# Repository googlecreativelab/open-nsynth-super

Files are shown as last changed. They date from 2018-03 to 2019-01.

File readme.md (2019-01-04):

# Open NSynth Super

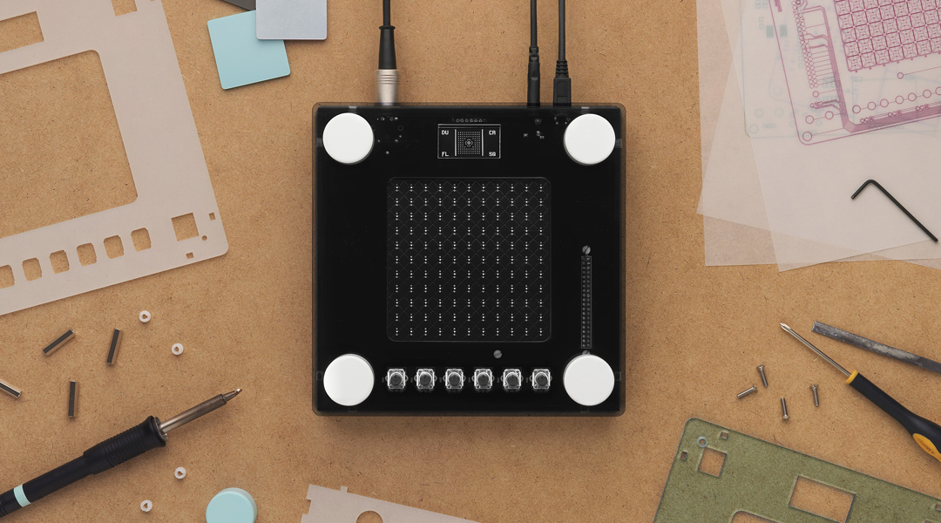
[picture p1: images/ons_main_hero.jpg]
Open NSynth Super with tools and designs


Open NSynth Super is an experimental physical interface for NSynth, a machine learning algorithm developed by [Google Brain’s Magenta team](https://magenta.tensorflow.org/) to generate new, unique sounds that exist between different sounds. Open NSynth Super allows you to create and explore new sounds that it generates through a simple to use hardware interface that integrates easily into any musician’s production rig. To find out more, visit the [NSynth Super website](https://nsynthsuper.withgoogle.com).

This repository contains all the instructions and files required to build an Open NSynth Super instrument from scratch, and you can use them to make your own version. Anyone can fork the code and schematics to remix the instrument in any way they wish.

### About this document

This document has three chapters – an overview of the instrument itself, a 'make your own' guide, and an overview of the audio creation process.

- [The 'how it works' overview](#how-it-works) summarises the technical and user interface features of the Open NSynth Super instrument.

- [The 'make your own' guide](#guide-how-to-make-open-nsynth-super) takes you through the steps required to build an Open NSynth Super unit and load it with an example Linux image containing pre-computed sample audio, helping you to get started with the instrument straight away.

- [The audio creation overview](#audio-creation-overview) gives a high-level summary of the audio creation pipeline, which enables you to process audio files (on a separate computer) and load the instrument with your own input sounds.

This repository also includes individual chapters on every aspect of Open NSynth Super, so you can build a unit from scratch, or hack and customise any part of it:

- [Application software](/app)
- [Audio creation pipeline](/audio)
- [Case & dials](/case)
- [Firmware & microcontroller](/firmware)
- [OS and provisioning](/linux)
- [PCB and hardware](/pcb_hardware)

# How it works

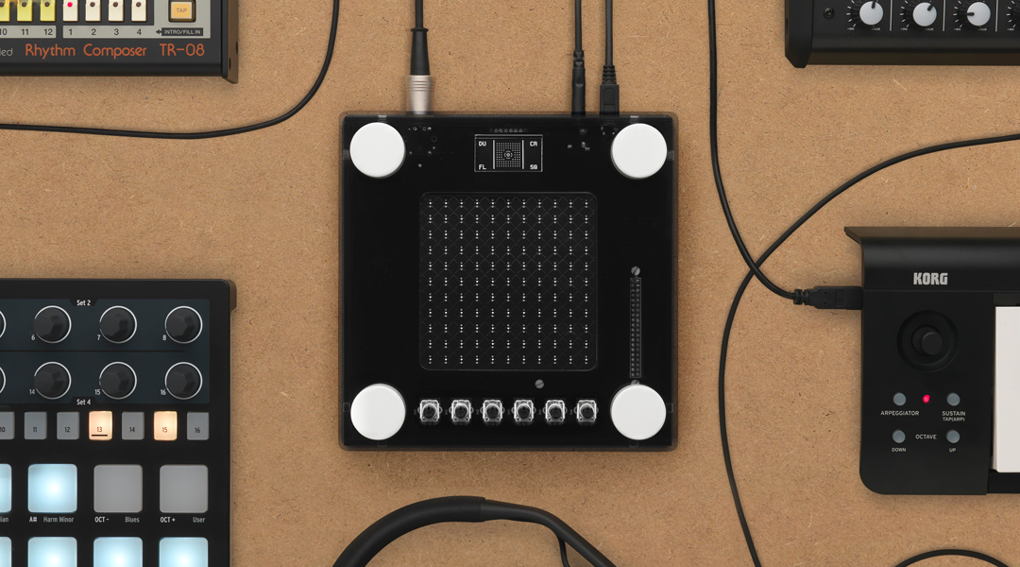
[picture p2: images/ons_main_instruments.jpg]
Open NSynth Super with audio equipment


Open NSynth Super is super simple to integrate into any production music rig. Like many other synthesizer modules, it receives MIDI input via a 5-pin DIN connector, and outputs audio through a 3.5mm jack cable. This simple interface allows it to work with almost any MIDI source, like keyboards, DAWs, or hardware sequencers.

### User interface

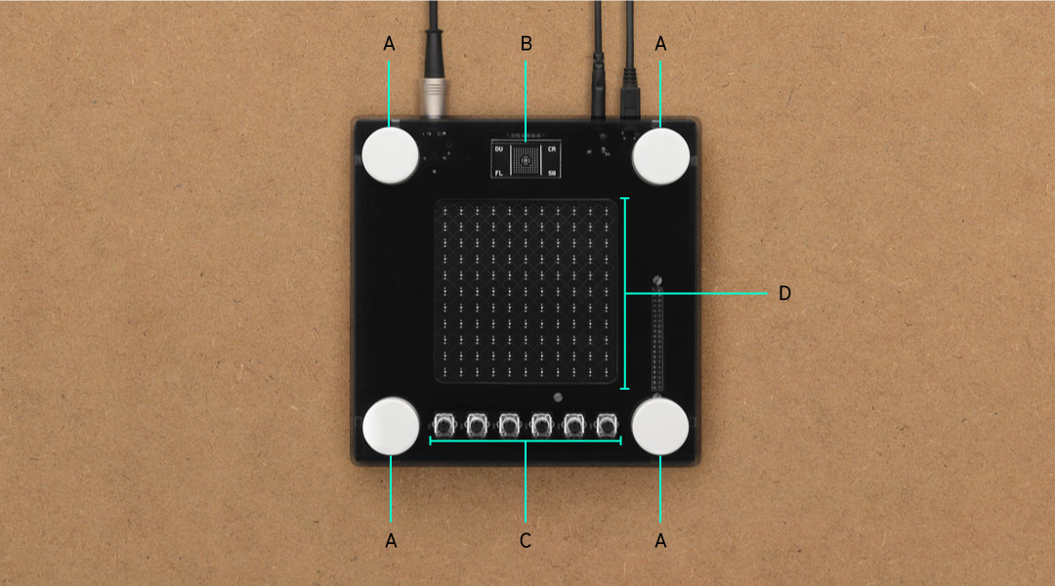
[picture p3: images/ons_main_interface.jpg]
Open NSynth Super user interface


The physical interface of Open NSynth Super is constructed around a square touch interface. Using dials in the corners of the touch surface, musicians can select four source sounds and use the touch interface to explore the sounds that the NSynth algorithm has generated between them. In addition, the instrument also has controls for tuning the new sounds via the fine controls.

**(A) Instrument selectors & patch storage** - These rotary dials are used to select the instruments that are assigned to the corners of the interface. In version 1.2.0, these selectors can be pushed down to store or clicked to recall settings patches.

**(B) OLED display** - A high-contrast display shows you the state of the instrument and additional information about the controls that you are interacting with.

**(C) Fine controls** - These six dials are used to further customize the audio output by the device:

- 'Position' sets the initial position of the wave, allowing you to cut out the attack of a waveform, or to start from the tail of a newly created sound.
- 'Attack' controls the time taken for initial run-up of level from nil to peak.
- 'Decay' controls the time taken for the subsequent run down from the attack level to the designated sustain level.
- 'Sustain' sets the level during the main sequence of the sound's duration, until the key is released.
- 'Release' controls the time taken for the level to decay from the sustain level to zero after the key is released.
- 'Volume' adjusts the overall output volume of the device.

**(D) Touch interface** - This is a capacitive sensor, like the mouse pad on a laptop, which is used to explore the world of new sounds that NSynth has generated between your chosen source audio.

### Technical overview

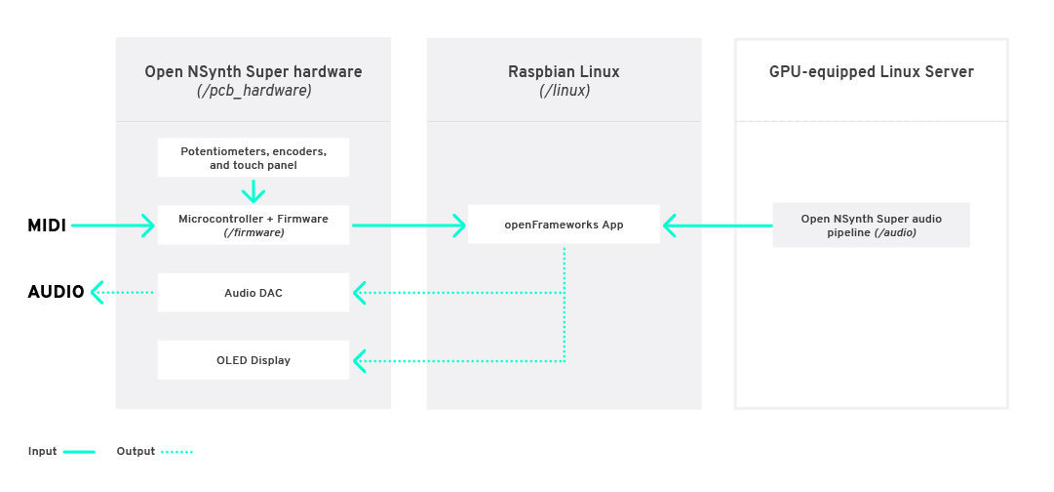
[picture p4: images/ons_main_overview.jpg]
Open NSynth Super system diagram


There are several distinct components to each Open NSynth Super unit: a custom PCB with a dedicated microcontroller and firmware for handling user inputs; a Raspberry Pi 3 computer running Raspbian Linux and an openFrameworks-based audio synthesiser application; and a series of scripts for preparing audio on a GPU-equipped Linux server using the NSynth algorithm. In addition to the software, firmware, and hardware, there are files for creating a casing and dials for the unit.

##### Hardware & firmware

The electronics are built around a Raspberry Pi 3 running Raspbian Linux, and a custom PCB used to read the inputs and control the outputs. A microcontroller on the PCB manages the physical inputs: there are four rotary encoders on the four corners for instrument selection; six potentiometers below the interface to control the position, envelope, and volume settings; and a capacitive grid on the surface of the PCB (exposed through the top layer of the case) used to select the mixing point of the four instruments.

More information on the electronics, hardware, and firmware can be found [here](/pcb_hardware), and [here](/firmware). A complete bill of materials for the case and electronics is available in this Excel [spreadsheet](https://storage.googleapis.com/open-nsynth-super/onss_bom_1.2.0.xlsx).

##### Software
Open NSynth Super runs a multisampler audio application built on [openFrameworks](http://openframeworks.cc) to process incoming MIDI note data and generate sound output. More information about this application can be found in the [software readme file](/app).

##### Case
We designed a case for the electronics that can be easily manufactured with a laser cutter, and held together with standard screws and fittings. This design is easily customisable using different materials, colors, dials, and shapes. Read more about this in the [case readme file](/case).

##### Audio
Audio for the Open NSynth Super instrument is produced by the NSynth algorithm. Because generating audio requires a great deal of processing power, this repository includes a set of scripts that you can run on a server which will take any audio recordings of your choice and convert them into a format compatible with the instrument. For more information, see the [audio readme file](/audio) or the [audio creation overview](#audio-creation-overview) in this document.

# Guide: How to make Open NSynth Super

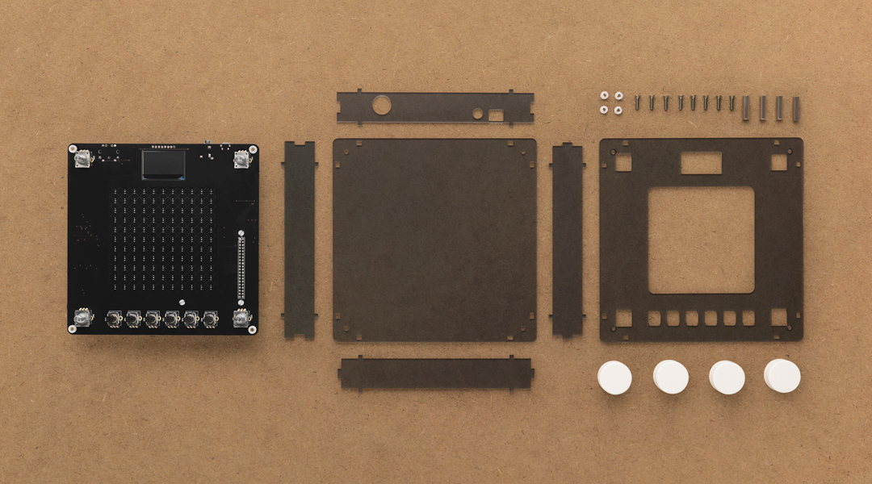
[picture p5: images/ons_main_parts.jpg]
Open NSynth Super parts


This guide gives you an overview of how to create casing and electronics for Open NSynth Super, and load the device with a premade Linux image which is already set up with application software, hardware support, and example sounds.

The example image file includes the following software features:
- Raspbian Linux Lite
- Full configuration to support the Open NSynth Super mainboard
- Open NSynth Super software application pre-loaded and configured
- Sample audio data
- A read-only filesystem for robustness

You will need the following off-the-shelf items to complete this guide:

- Micro SD card (16GB or 64GB)
- Raspberry Pi 3B+
- 5V 2A micro-USB power supply

You will also need the following Open NSynth Super-specific items, which are detailed in the steps below:

- Open NSynth Super mainboard
- Laser cut Open NSynth Super case
- 3D printed dials (optional)

### 1. Laser cut the shell

This repository contains a reference design for a laser-cut shell for Open NSynth Super. As well as the case design, there are two sizes of 3D-printed dials which can optionally be added to the build. Parts for the case can be cut manually, or obtained easily from a laser-cutting service by supplying these files. More detailed information and specifications for the case can be found in the [case readme](/case) file.

You should make or order a case following the above guide before moving forward with the build. Don't assemble the case yet, as you will need access to the ports on the Raspberry Pi.

### 2. Manufacture and assemble the PCB 

Open NSynth Super is built around a custom PCB with inputs for the hardware controls, audio and data I/O ports, and an OLED display for the UI. The PCB can be ordered fully assembled (this is most cost effective when ordering several boards), or be assembled by hand in a few hours. Further detail on the manufacture and assembly of the board can be found in the [PCB readme](/pcb_hardware) file.

**You will need to obtain or build your PCB before proceeding further with this guide.**

In order to test the board, you will need to have a working Open NSynth Super software installation, which you will prepare at the next step. Before proceeding, connect the Raspberry Pi GPIO pins to the Open NSynth Super mainboard.

### 3. Prepare the SD card

There are two preconfigured OS images available, both loaded with sample audio and fully configured for use with NSynth Super. Depending on the size of your SD card, you can choose either the [64GB image](https://storage.googleapis.com/open-nsynth-super/images/onss_1.2.0_full.img.bz2) or [16GB image](https://storage.googleapis.com/open-nsynth-super/images/onss_1.2.0_lite.img.bz2).

The easiest way to create the SD card is to use GUI software like [Etcher](https://etcher.io/), Win32DiskImager, or the [SD Card Association's](https://www.sdcard.org/downloads/formatter_4/) formatter to burn the example image to a card.

The supplied images are compressed in bz2 format. These can be decompressed on the fly when writing to an SD card using the following command:

```
$ bzcat <IMAGE NAME> | sudo dd of=<DISK NAME>
```

 Connect a keyboard and screen to the Raspberry Pi, insert the SD card, and plug a USB power cable into the socket on the Open NSynth Super mainboard. You should see the Pi booting up on the connected display; when you receive a prompt, you can login with the default username and password: pi / raspberry. **Note that the device might run a file system check when you first boot up from the new card – this will take about 5 minutes depending on the size of the disk.**

### 4. Install the firmware

The firmware will need to be loaded to the microcontroller on your Open NSynth Super mainboard. This allows the software application running on the Raspberry Pi to interact with the controls.

Because the file system is locked for robustness, you will need to remount the disk as read/write by running the following command on your Raspberry Pi:

```
$ sudo mount -o remount,rw /
```

Next, navigate to the firmware directory and run the install command:

```
$ cd /home/pi/open-nsynth-super-master/firmware/src
$ make install
```

This command will build and install the firmware to the microcontroller. You will receive a message on screen confirming the operation has been successful:

```
** Programming Started **
auto erase enabled
Info : device id = 0x10006444
Info : flash size = 32kbytes
wrote 12288 bytes from file ../bin/main.elf in 0.607889s (19.740 KiB/s)
** Programming Finished **
** Verify Started **
verified 11788 bytes in 0.050784s (226.680 KiB/s)
** Verified OK **
** Resetting Target **
adapter speed: 1001 kHz
shutdown command invoked
```

More detailed information about the firmware can be found in the [firmware readme](/firmware) file. When the firmware installation is complete, you can power down the system using the following command, and move to the next step:

```
$ sudo poweroff
```

### 5. Verify the installation

Before assembling the shell and 'finishing' the instrument, it's important to check that everything is functioning correctly. To do this, plug in a MIDI device (like a keyboard), a pair of headphones or speakers, and power on the instrument.

After a few seconds, you should see the grid interface appear on the OLED screen. Move your finger around the touch interface to test its responsiveness. Next, adjust the six controls at the base of the unit; the UI should update according to the control that you are adjusting. Finally, test the four instrument selection encoders, which will scroll through an instrument list on the screen.

To test the audio, ensure your MIDI device is broadcasting on channel 1 (the default channel), and send some notes to the device. You should hear audio coming from the speakers or headphones (if you don't hear anything, make sure the device audio is turned up, and that the envelope and position controls aren't cutting the audible part of the waveform).

Because the standard image is preconfigured, you can use it to test that your Open NSynth Super mainboard is functioning correctly. If all features are up and running, you can move on to final assembly.

### 6. Assemble the shell

Now that you have a fully functioning instrument, you can finally build it into its shell. Power the unit down, remove all connections (e.g. screen, keyboard, MIDI, power), and follow the instructions found [here](/case).

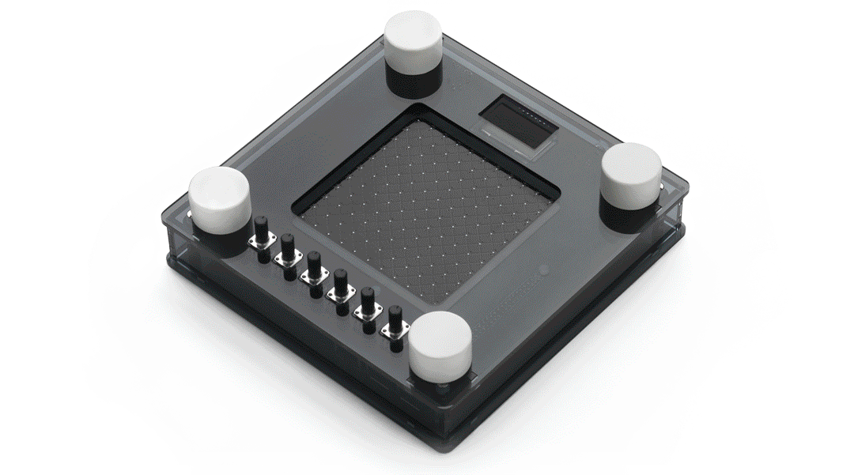
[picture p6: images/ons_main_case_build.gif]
Open NSynth Super case


### 7. Play with Open NSynth Super

With the case assembled, firmware installed, and the device tested, you're ready to go and make music with your Open NSynth Super. There are detailed readmes in this repository for the software application, case, PCB and audio creation pipeline if you want to go into more detail, or start hacking the device.

# Audio creation overview

Sounds for Open NSynth Super are created using the neural synthesis technique implemented by Google Brain’s [Magenta](https://magenta.tensorflow.org/) team as part of their NSynth project. You can read more about Magenta and NSynth on their [project page](https://github.com/tensorflow/magenta/tree/master/magenta/models/nsynth).

Because generating audio requires a great deal of processing power, this repository includes a set of scripts that you can run on a server which will take any audio recordings of your choice and convert them into a format compatible with the instrument. This audio pipeline is built on top of the NSynth implementation available through [Magenta's GitHub page](https://github.com/tensorflow/magenta/tree/master/magenta/models/nsynth).

The pipeline has the following stages:

1. Assemble input audio files and assign sounds to corners of the interface
2. Calculate the embeddings of the input sounds with the NSynth model
3. Interpolate between these to create a set of embeddings for newly generated sounds
4. Generate the audio
5. Remove crackles and other artifacts from the generated audio
6. Package and deploy the audio to the device

**More detailed instructions on how to run the pipeline, including how to set up and provision a GPU-equipped Linux server for processing audio, are available [here](/audio).**

---

### Changelog

##### Version 1.2.0
The latest version of Open NSynth Super is 1.2.0. This version adds support for storage and recall of patches and settings, swaps the instrument selector encoders for push-button variants, and introduces note looping to enable sustaining notes beyond their original sample length. Version 1.2.0 software is backwards compatible with version 1.0.0 hardware, although the push-button patch storage feature is not available.

##### Version 1.0.0
Version 1.0.0 is tagged in this repository. The example disk images for software version 1.0.0 are available for download as a [64GB image](https://storage.googleapis.com/open-nsynth-super/images/onss_1.1_full.img) or [16GB image](https://storage.googleapis.com/open-nsynth-super/images/onss_1.0_lite.img).

---

### Notes
This is a collaborative effort between Google Creative Lab and [Magenta](https://github.com/tensorflow/magenta), [Kyle McDonald](https://github.com/kylemcdonald), and our partners at [RRD Labs](https://github.com/dgym). This is not an official Google product.

We encourage open sourcing projects as a way of learning from each other. Please respect our and other creators’ rights, including copyright and trademark rights when present when sharing these works and creating derivative work. If you want more info on Google's policy, you can find it [here](https://www.google.com/permissions/). To contribute to the project, please refer to the [contributing](CONTRIBUTING.md) document in this repository.

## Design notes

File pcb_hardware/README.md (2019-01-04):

# Open NSynth Super PCB hardware

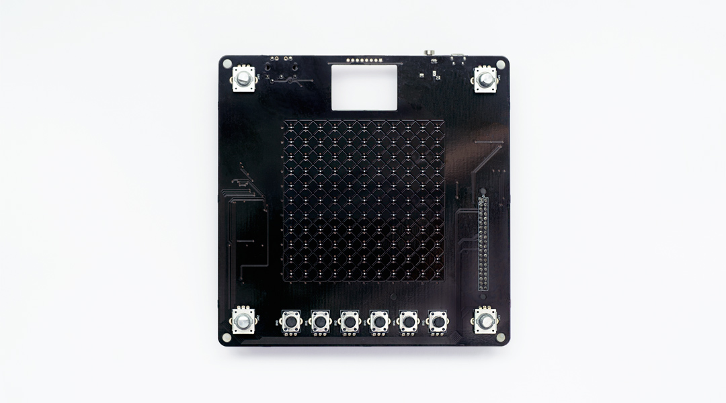
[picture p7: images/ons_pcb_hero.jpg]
Open NSynth Super PCB


This folder contains all of the source files for making your own Open NSynth Super PCB hardware: a KiCAD project for the PCB in `projects/open-nsynth-super`, rendered gerber files from the KiCAD project in `render/`, and exported schematics from the KiCAD project in `schematics/`.

The PCB design includes a mix of SMT and through-hole components. It is possible to assemble individual boards by hand in a few hours, however for multiple boards it would be advisable to order multiple fully assembled (or at least SMT assembled) PCBs. If you wish to have the PCB manufactured, the files in `render/` should be all you need; additionally, a bill of materials is [available here](https://storage.googleapis.com/open-nsynth-super/onss_bom_1.2.0.xlsx).

For reference, development PCBs were fabricated at the following specification:

- 160mm x 160mm board
- 1.6mm thickness
- 1oz copper
- 2 layers
- Silkscreen both sides
- Smallest drill (for vias) 0.4mm
- Smallest router 0.8mm

# PCB overview

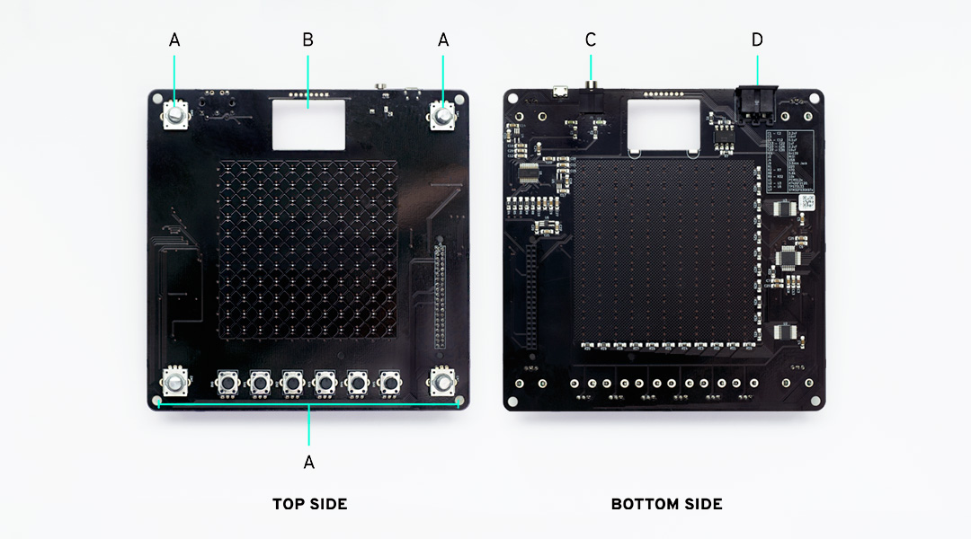
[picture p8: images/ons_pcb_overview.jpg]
Top and bottom sides of Open NSynth Super PCB


The hardware component of Open NSynth Super provides:

 **(A)** A set of encoders and potentiometers for controlling the audio signal and interface, and a capacitive sensor as a physical interface for controlling the synthesizer voice

 **(B)** Connector for an OLED display module

 **(C)** A dedicated audio output circuit with a 3.5mm audio output

 **(D)** MIDI input via a 5-pin DIN jack

# User inputs

### Rotary encoders

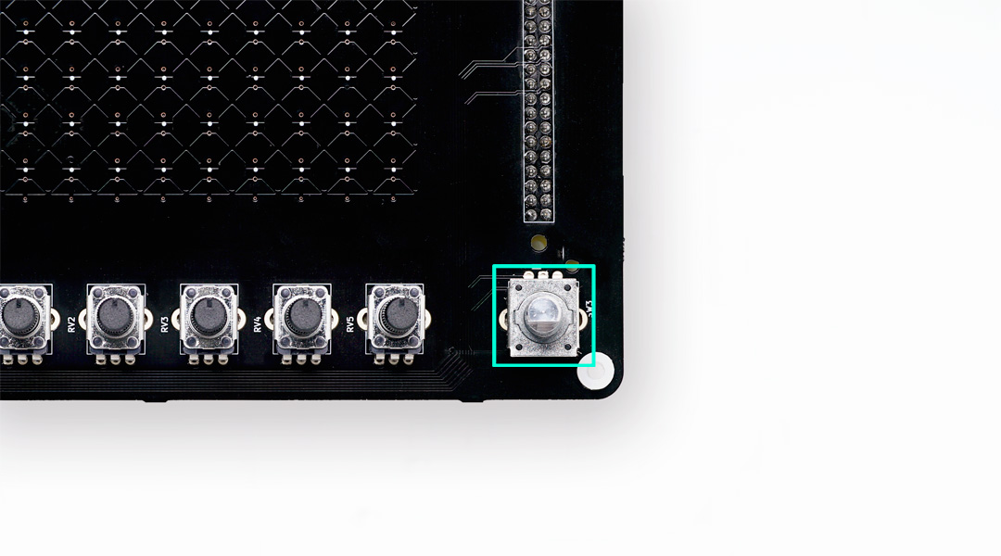
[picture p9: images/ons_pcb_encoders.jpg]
Rotary encoders select source sounds


The four instruments are selected by rotary encoders placed in the four corners of the PCB. These are connected to the MCU which keeps track of their changes.

### Potentiometers

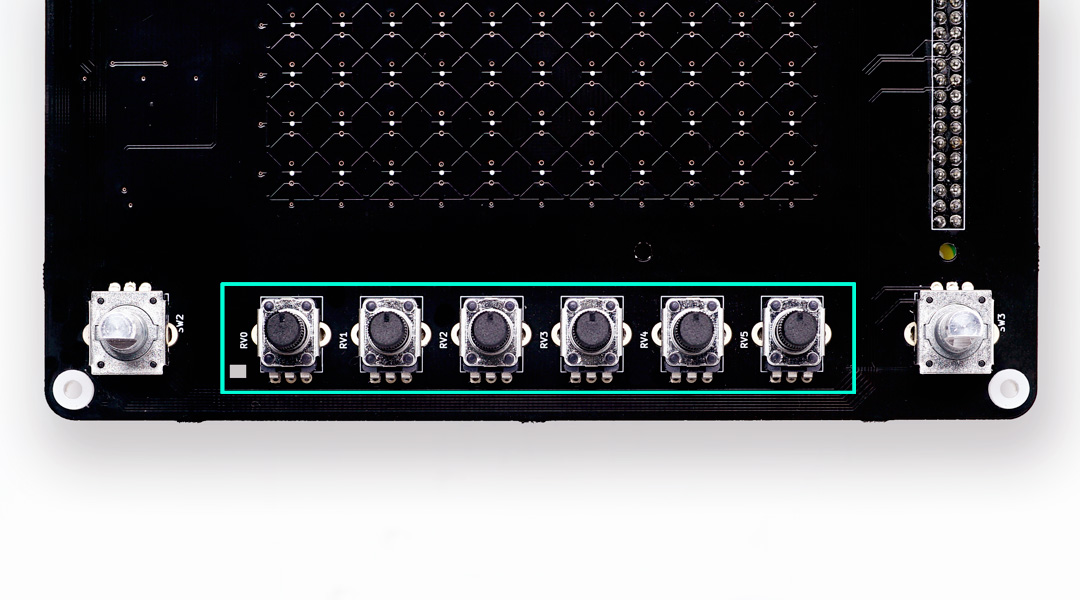
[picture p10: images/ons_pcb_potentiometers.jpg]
Potentiometers are for fine control


The position, sound envelope and volume are controlled by six potentiometers placed along the bottom edge of the PCB. These are connected to the MCU which performs the ADC conversions to read the current values.

### Touch interface

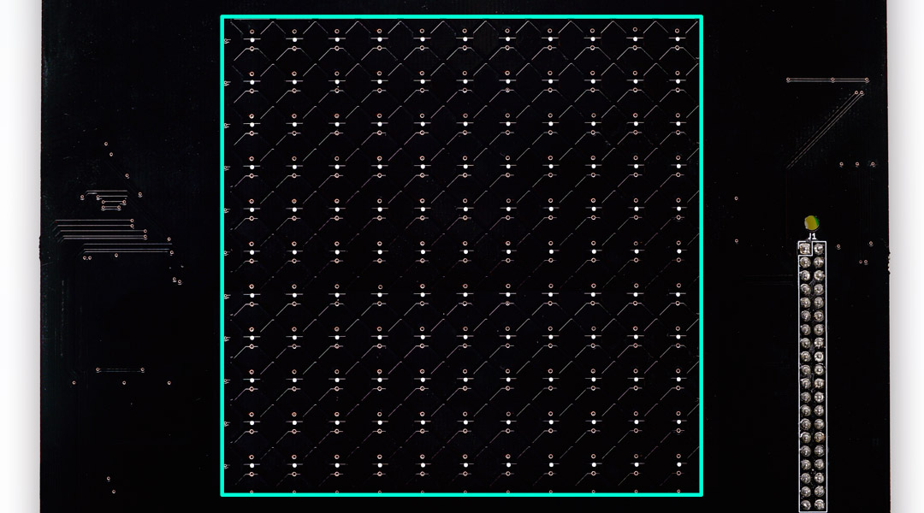
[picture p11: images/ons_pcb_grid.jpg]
Touch sensitive grid for choosing new voices


The PCB has a touch sensitive area used to control the interpolation between the four selected instruments. Each axis of the grid is connected to a touch controller IC reading the eleven channels. Because the touch controllers use a fixed I²C address they can not operate on the same bus. For this reason they are not connected to the Raspberry Pi's I²C bus, instead they are connected to the MCU on two additional I²C buses.

# Inputs & outputs

### MIDI

The 5 pin 180 degree MIDI input socket is connected to an opto-isolator circuit. The output of this is connected to the Raspberry Pi's serial input.

### Audio

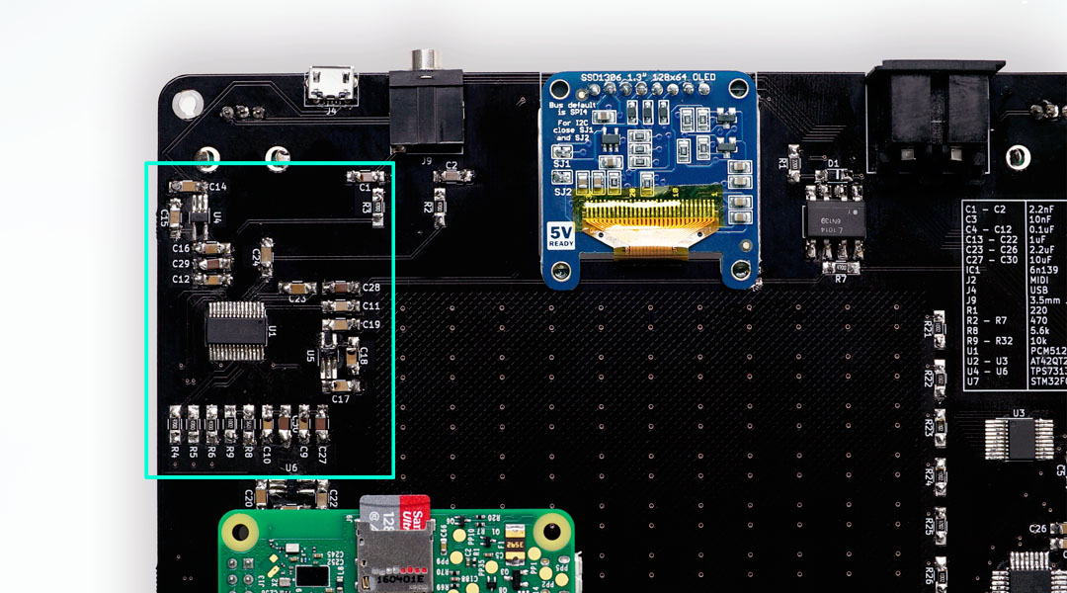
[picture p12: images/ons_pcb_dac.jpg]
Audio output portion of the Open NSynth Super PCB


The PCB includes a good quality DAC driving the line out 3.5mm jack. The DAC is connected to the Raspberry Pi's I²S bus for audio data. It is also connected to the Raspberry Pi's I²C bus for volume and other controls.

The DAC's analog and charge pump sources are supplied by two dedicated LDO voltage regulators for improved sound quality.

# Attaching the display

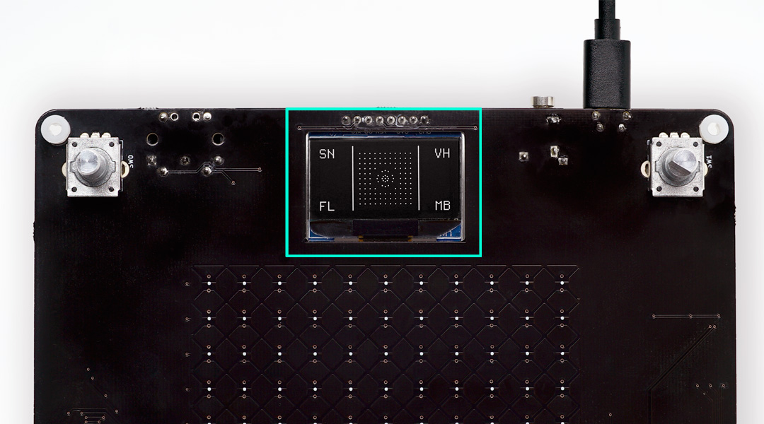
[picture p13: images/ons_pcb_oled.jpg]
High contrast OLED display module


For ease of assembly the display is an [off the shelf module](https://www.adafruit.com/product/938) with a board to board mounting. It is controlled by I²C and is on the Raspberry Pi bus. The module requires reset logic that can be done in hardware but to reduce component count it is done by GPIO instead. The reset pin is connected to a Raspberry Pi GPIO pin. The OLED screen supports two modes: I²C and SPI. By default, it runs in SPI mode, but for Open NSynth Super it should be set to I²C. On the back of the screen there are two jumper pads (SJ1 and SJ2) that need to be soldered to switch to I²C mode:

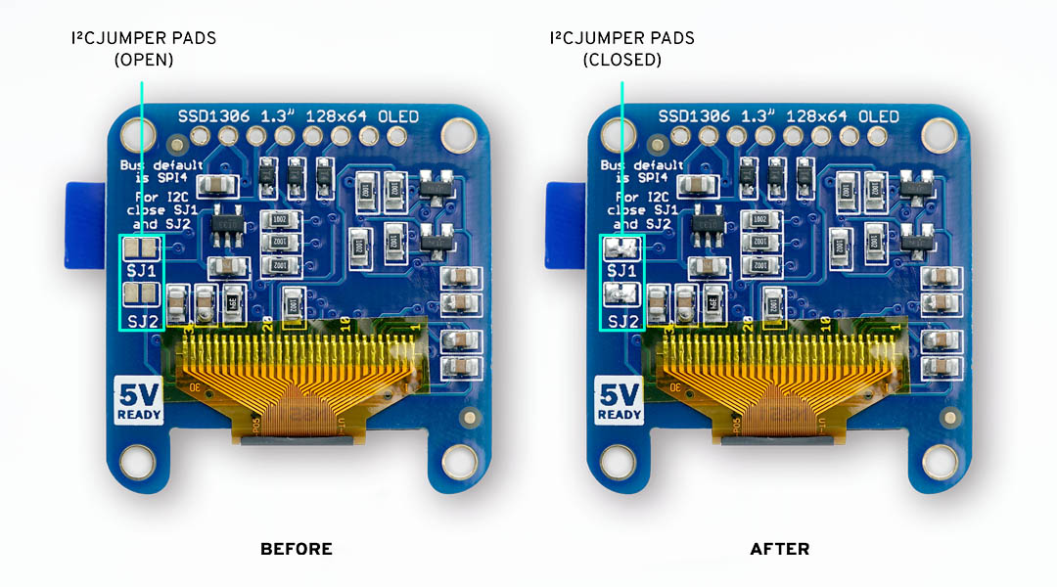
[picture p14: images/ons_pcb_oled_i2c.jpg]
Set the display module to I2C mode


The screen module has a through hole connector that connects it directly to the PCB. To improve mechanical resistance, we suggest to solder also the bottom pads. First, apply some flux on the pads:

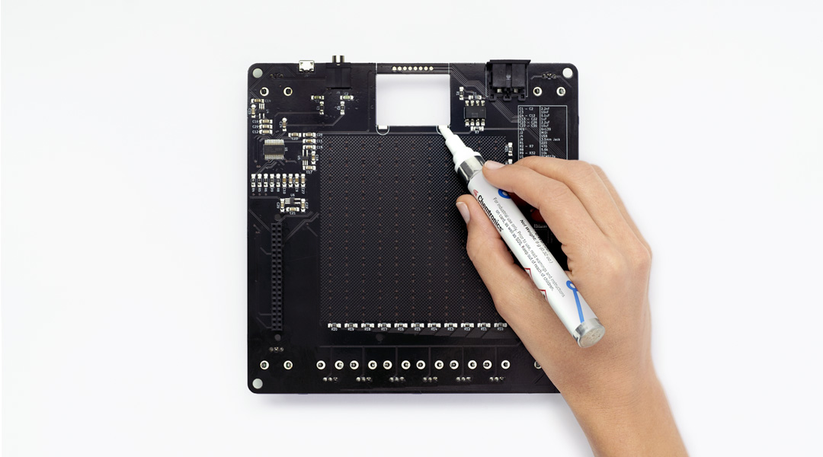
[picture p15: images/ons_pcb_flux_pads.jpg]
Apply flux to the pads


Apply some solder to the pads:

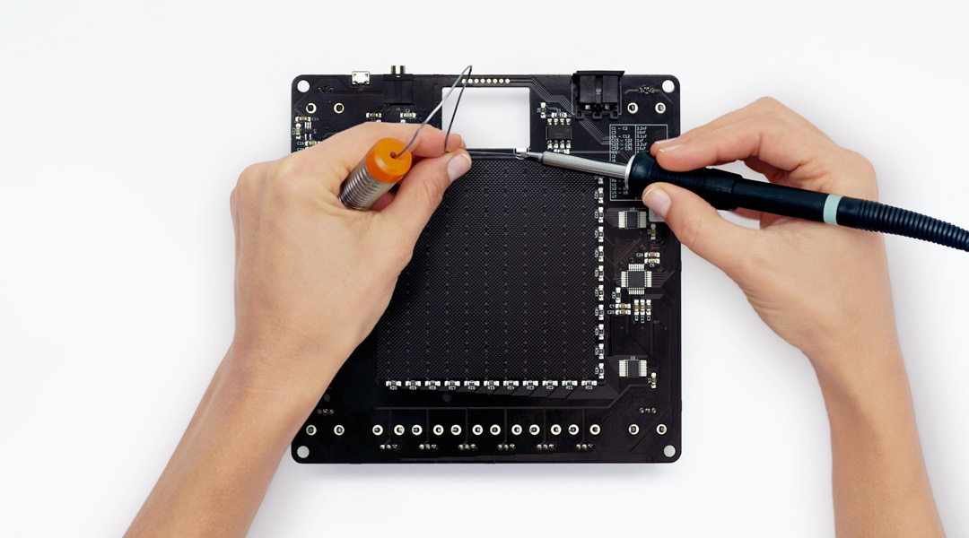
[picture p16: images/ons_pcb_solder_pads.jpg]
Apply solder to the pads


With the screen PCB held in place (you can use electrical tape to help), push one end of the header through both PCBs and solder to the top side of the main Open NSynth Super board:

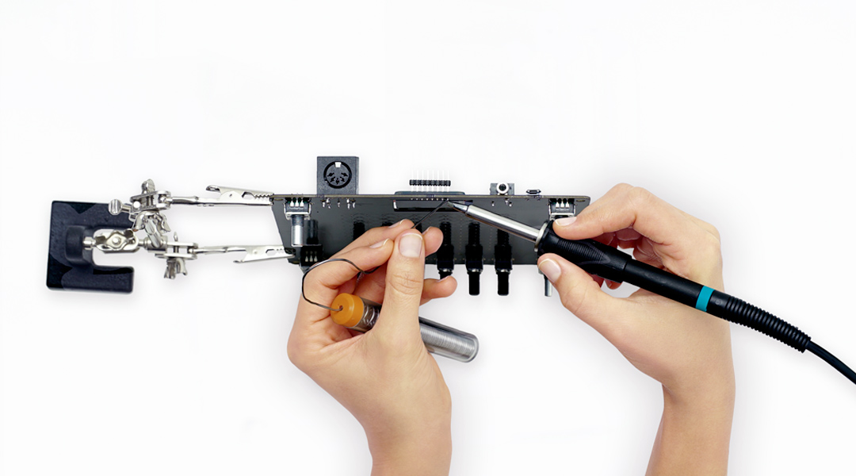
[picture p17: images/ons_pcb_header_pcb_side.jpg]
Solder headers to the Open NSynth Super PCB


Clip the excess header on the reverse side of the board, leaving enough to securely solder to the screen PCB:

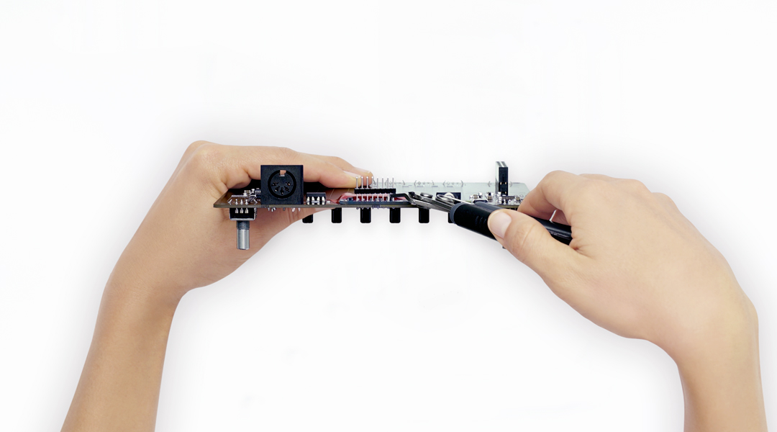
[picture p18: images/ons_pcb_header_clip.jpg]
Clipp the excess header


Solder the remaining header connector on the screen board (you can cut away any excess header after this step):

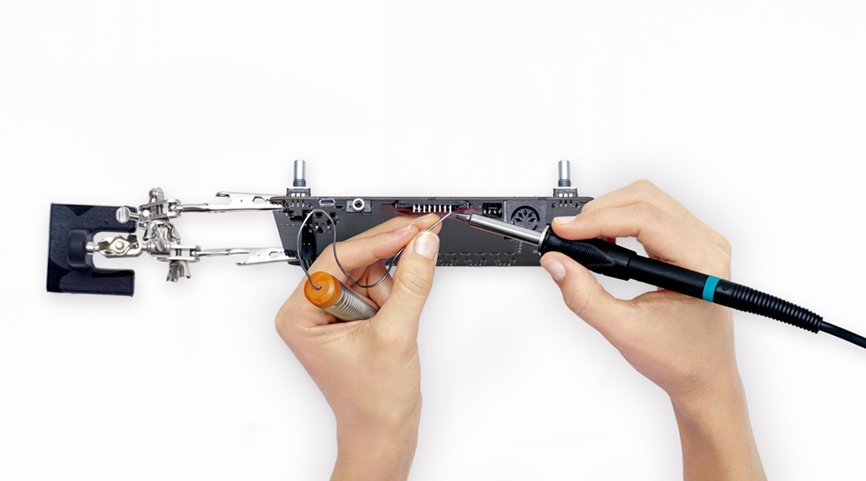
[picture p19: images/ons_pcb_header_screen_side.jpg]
Solder header to the screen module


Finally, you need to solder the screen on the bottom pads for extra mechanical strength. Put a good amount of flux in the screen PCB hole:

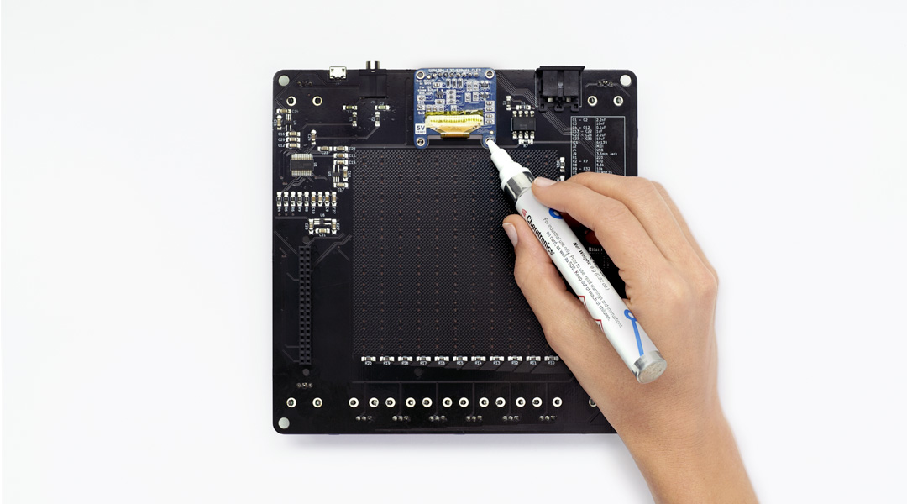
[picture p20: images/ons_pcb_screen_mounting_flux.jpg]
Apply flux to the screen mounting holes


Now, apply a small amount of solder on the tip of the iron, and then, while holding the screen down to the board, hold the iron in the mounting hole for a short period of time (until you feel the solder has melted). Continue holding the board and screen together until you feel that the solder has cooled:

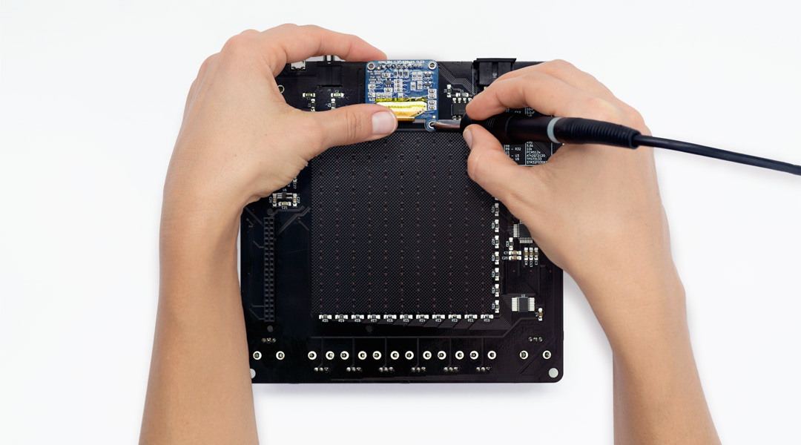
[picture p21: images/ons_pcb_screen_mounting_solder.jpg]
Apply solder to the screen mounting holes


# Finishing the PCB

After soldering the potentiometers and rotary encoders, the pins highlighted below (SW3, RV5, RV4) should be trimmed, to avoid contact with the Raspberry Pi. Optionally, they can also be covered with an insulant material such as electrical tape.

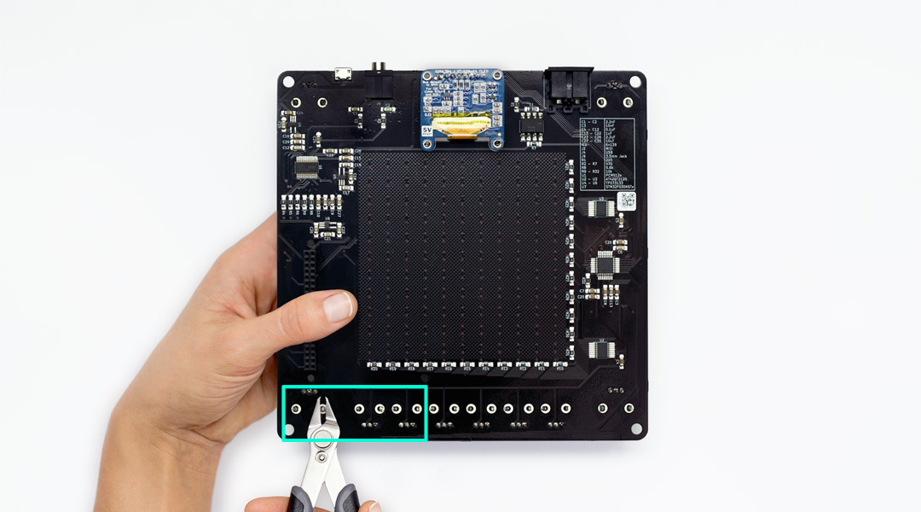
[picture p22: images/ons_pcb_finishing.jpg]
Finishing the board by clipping excess solder and mounts


In order to preserve performance of the touch panel, you can add a layer of adhesive plastic to the surface of the board to insulate from moisture (depending on the thickness of the plastic you may wish to adjust the sensitivity of the touch sensor; however the default settings should work for a thin sheet of adhesive plastic.)

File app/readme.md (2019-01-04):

# Open NSynth Super application

Open NSynth Super is run by an openFrameworks application that is installed on the Raspberry Pi. It communicates with the OLED display, receives input from the encoders and potentiometers via the microcontroller, processes incoming MIDI data, and outputs audio. The app is built using openFrameworks 0.9.8 and the following addons:

- [SoundParts](https://github.com/kylemcdonald/SoundParts) by Kyle McDonald
- [ofJson](https://github.com/openframeworks/openFrameworks/blob/master/libs/openFrameworks/utils/ofJson.h) from openFrameworks (development version)

This document includes a guide for setting up the application, and additional details for configuring the application (e.g. MIDI channel, file paths, audio settings).

# Installation guide

1. If you haven't already copied this repository to the device, you will need to do so. You can run the following command on your device to find out its IP address:
	```
	$ ifconfig | grep inet
	inet addr: <DEVICE IP ADDRESS> Bcast: 255.255.255.0 Mask 255.255.255.0
	```

	You can copy the repository directory to the device from your host computer via SCP:

	```
	$ scp -r open-nsynth-super-master pi@<DEVICE IP ADDRESS>:~
	```

2. These instructions assume that you have run the setup script from the [provisioning readme](../linux), which establishes the file structure used in this guide.

	On the Pi, navigate to the openFrameworks apps directory, and create a new directory for the ```open-nsynth``` application.

	```
	$ cd /home/pi/opt/of/apps/
	$ mkdir open-nsynth
	```

3. Copy the contents of the app directory in this repository into the openFrameworks app directory you just created on the device.

	```
	$ cp -r /home/pi/open-nsynth-super-master/app/open-nsynth /home/pi/opt/of/apps/open-nsynth
	```

4. When the directory has copied, navigate to it, and build the application. This will take up to 2 hours.

	```
	$ cd /home/pi/opt/of/apps/open-nsynth/open-nsynth
	$ make -j4
	```

	The openFrameworks build script will inform you if the application has installed successfully. When you see this message, the application is set up. If you are using an example settings file, you should copy it now to the application folder:

	```
	$ cp /home/pi/settings.json /home/pi/opt/of/apps/open-nsynth/open-nsynth/bin/data/settings.json
	```

	If you are following the provisioning instructions, you can return to that guide now.

# Changing application settings

The application is configured via a JSON file (`settings.json`) which is located in the `/home/opt/of/apps/open-nsynth/open-nsynth/bin/data/` directory. The most important property is instrument assignment (which source sounds are placed in which corner), which should match exactly the names of the audio patches that you are using.

### Audio data path
Set the property `nsynth: dataDirectory` to the absolute path of the audio data directory (either the [1.7GB lite](https://storage.googleapis.com/open-nsynth-super/audio/onss_lite_audio.tar.gz) or [26GB full](https://storage.googleapis.com/open-nsynth-super/audio/onss_full_audio.tar.gz) sample audio, or created using the [audio pipeline](../audio)).

### Pitches
The `nsynth: pitches` array should contain all of the input note values that you have trained the dataset on. Setting this incorrectly will cause pitches and voicings to be mismatched on playback.

### Instrument assignment
Use `corners: instruments` to assign instruments to the corners of the interface. The order of these arrays are: top left, top right, bottom left, bottom right. The `name` property should match the filename; `display` will set the text displayed in the instrument selection interface on the device (with a limit of 8 characters); `abbr` is the two character abbreviation used in the main display.

### MIDI channel
The default MIDI device should be unchanged, while the channel can be safely altered with the `channel` property.

### Loop points
There is a default audio looping point defined in the settings file. By tweaking the values of `loopStart` and `loopEnd` you can change the point in the sample where the device will loop notes. Looping can be enabled and disabled with the `looping` boolean.

### Patch Saving
The patch saving feature in version 1.2.0 enables storing and recalling settings. The path for this file can be set with the `patchFile` property.

# Deploying new sounds to the device
Any sounds that you've created using the [audio pipeline](../audio) should be placed in a directory on the device. As this can be many gigabytes of audio data, it's recommended that you remove the SD card from the device and copy locally using a Linux computer. (You may need to wait for `fsck` to run when you reinsert the card to the device and boot up for the first time after copying.)

The `dataDirectory` setting needs to be updated to match the new file and instrument names that have been copied. It's quite a common error to input the instrument names incorrectly, or in the wrong order, which prevents the software from locating the audio files. If you experience any issues after updating audio, this is the most likely issue.

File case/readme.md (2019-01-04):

# Open NSynth Super case

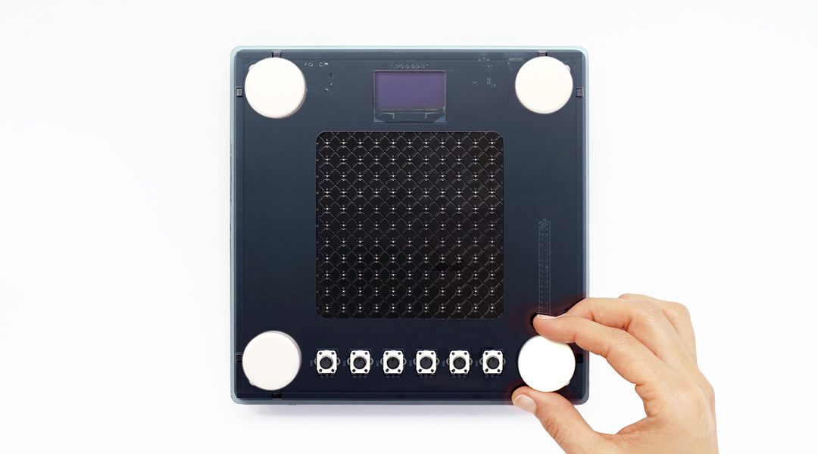
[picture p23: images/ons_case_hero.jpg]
Open NSynth Super case design


This directory contains all of the source files you will need to construct your own case for an Open NSynth Super unit. These files are provided as a reference design and are intended to be modified.

If you're in the process of building an Open NSynth Super for the first time, it's strongly advised that you make assembling your instrument into a case your last step, as you'll need access to ports for debugging.

# About the files

### Laser cutting template

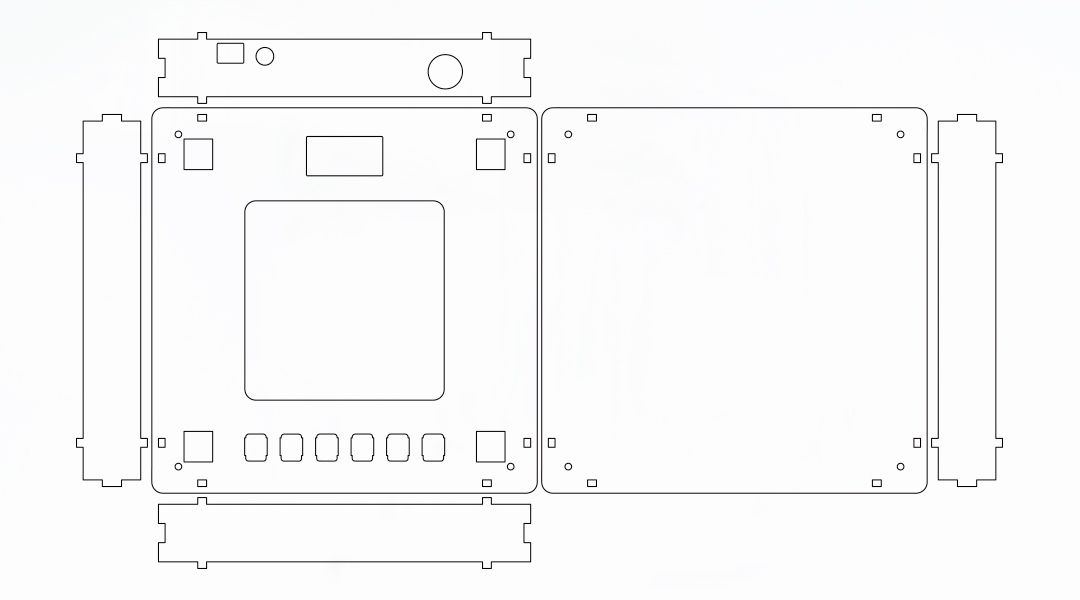
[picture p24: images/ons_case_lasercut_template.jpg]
Laser cut vector template


- [NSynth_Super_Lasercut_Template.dxf](NSynth_Super_Lasercut_Template.dxf)
- [NSynth_Super_Lasercut_Template.ai](NSynth_Super_Lasercut_Template.ai)

Templates for laser cutting the reference case design are provided in Adobe Illustrator and DXF format.

### Dial designs for 3D printing

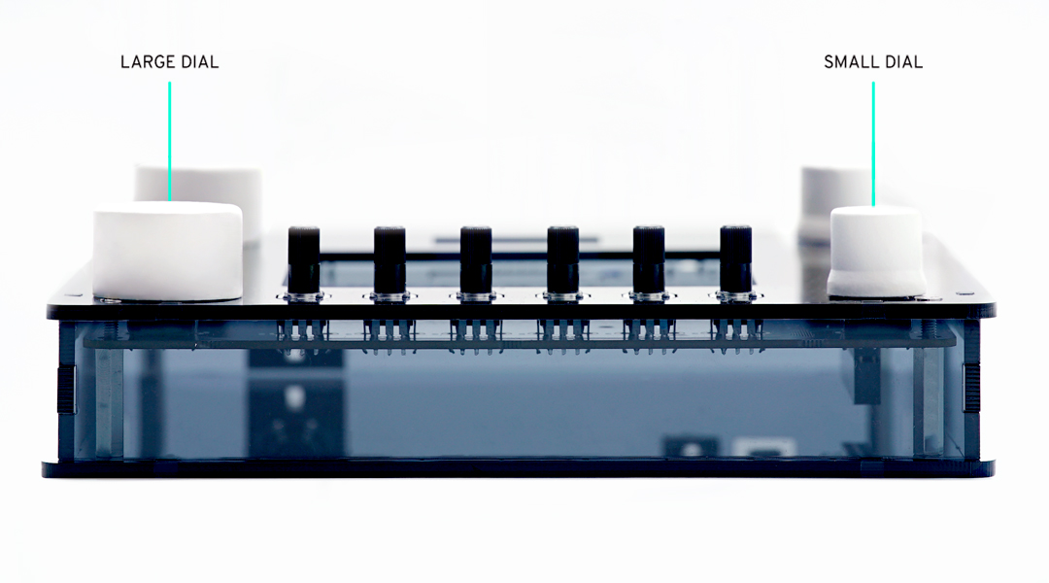
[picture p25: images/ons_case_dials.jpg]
Large and small dial designs


- [NSynth_Super_Dial_Big.stl](NSynth_Super_Dial_Big.stl)
- [NSynth_Super_Small_Dial.stl](NSynth_Super_Small_Dial.stl) 

There are two 3D-printable dial designs for the Open NSynth Super's instrument selection encoders. The larger dial requires you to countersink the mounting screws into the face of the top plate.

### Parts

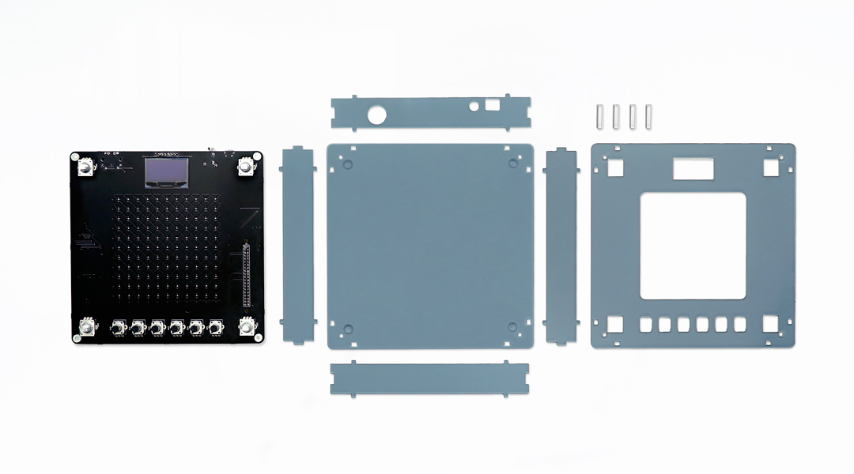
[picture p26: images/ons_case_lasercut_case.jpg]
Laser-cut acrylic Open NSynth Super case


- A sheet of 3mm thick, laser cuttable material (approx. 430mm x 260mm)
- 8 x 12mm M3 screws
- 4 x 20mm M3 standoffs 
- 4 x 3.2mm self retaining spacers
- Allen keys or screwdriver (depending on screw socket)

A bill of materials for the whole project is [available here](https://storage.googleapis.com/open-nsynth-super/onss_bom_1.2.0.xlsx).

# Building the case

Start by downloading the .ai or .dxf file from this repository for laser cutting. If necessary, load the files and edit for compatibility with your laser cutter (depending on the brand and model of the laser cutter you are using the setting will vary).

Attach the self retaining spacers to the PCB as shown.

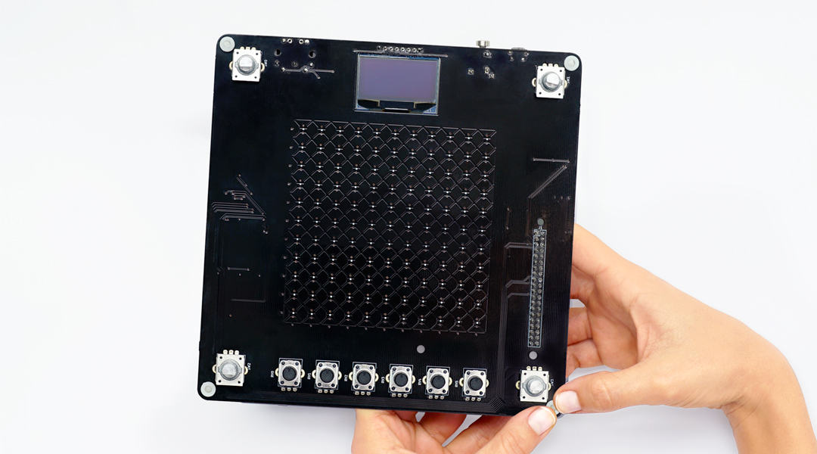
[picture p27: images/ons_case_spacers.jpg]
Attach self retaining spacers to the PCB


Use four of the 12mm M3 screws to fasten the 20mm standoffs to the bottom face of the case.

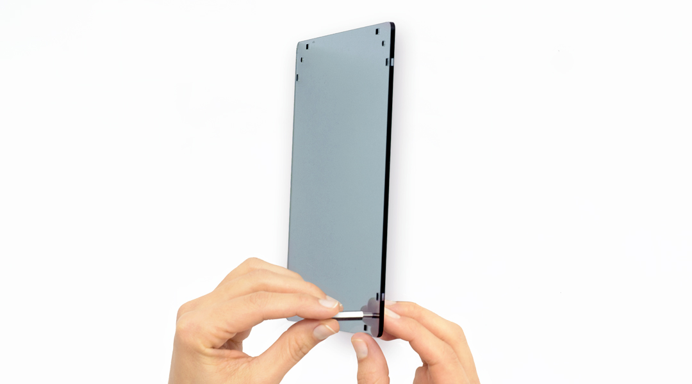
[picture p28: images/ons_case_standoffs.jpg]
Attach standoffs to the bottom panel


Position the PCB on the standoffs so that the drill holes are aligned with the screw holes of the standoffs.

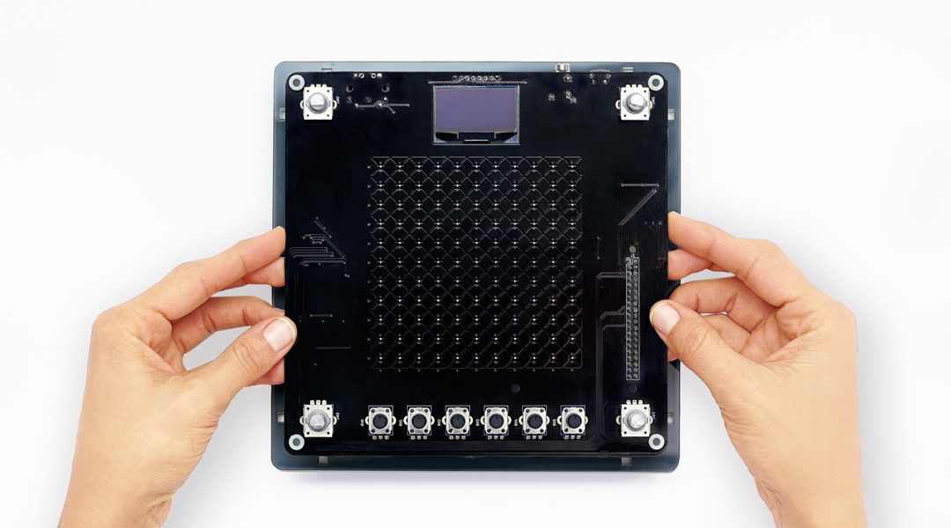
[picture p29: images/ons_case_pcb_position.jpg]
Position the PCB above the standoffs


Slot the back panel of the case into the base.

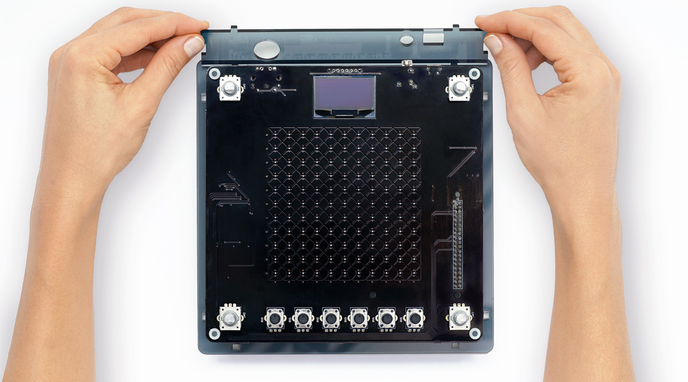
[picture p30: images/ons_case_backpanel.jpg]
Fit the back panel to the base


Fit the remaining side and front faces to the base and slot together the corner joints.

Fit the side and front pieces

Place the top face over the PCB, aligning the teeth with the side panels.

Place the top panel over the PCB

Screw the top face in place using the other four 12mm M3 screws. If you are using a dial with a radius bigger than 9.5 mm, such as the larger example in this repository, the top screws need to be countersunk using a pillar drill. 

Screw in the top panel

To finish the case, attach the dials to the encoders.

Attach the dials to the encoders

# Hacking the case

Cases made with different materials

These files are a starting point for creating a reference Open NSynth Super case; experimentation and modification is encouraged, for example adding vector graphics to the .AI file in a separate layer for rastering, or combining different materials and colors.

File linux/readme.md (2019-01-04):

# Open NSynth Super Device provisioning

Use this guide to provision a new Open NSynth Super device from scratch. You may wish to skip this process and download one of the pre-made images: [64GB with all sample audio](https://storage.googleapis.com/open-nsynth-super/images/onss_1.2.0_full.img.bz2) or the [16GB 'lite' version](https://storage.googleapis.com/open-nsynth-super/images/onss_1.2.0_lite.img.bz2).

As part of the process of setting up a new system, you will also have to install the Open NSynth Super software application and firmware for the Open NSynth Super mainboard. There are separate documents in this repository to help with this, which are linked in this step-by-step guide. Creating a new OS image will take 1-2 hours (depending on your internet connection speed) however most of this time is spent downloading and compiling software; the 'hands-on' time required is considerably shorter.

You will need:

- A Raspberry Pi 3
- An assembled Open NSynth Super mainboard PCB
- An SD card with at least 8GB capacity
- A wireless or wired network connection
- Raspbian Stretch Lite ([version 2018-06-27](http://downloads.raspberrypi.org/raspbian_lite/images/raspbian_lite-2018-06-29/))
- A Mac, Linux or Windows PC with SD writing capability (for example using [Etcher](http://etcher.io))

### 1. Create the SD card (cross-platform)

The easiest way to create the SD card is to use the Etcher software. Download the [application](http://etcher.io) from the Etcher website and set up on your machine (the process for doing this will differ across platforms).

You will need to download the correct Raspbian Stretch Lite image from the [Raspbian archive](http://downloads.raspberrypi.org/raspbian_lite/images/raspbian_lite-2018-06-29/). Open NSynth Super may work with other releases too.

It should take about 5 minutes to flash the image, depending on the speed of your card reader and card.

### 2. Create the SD card (*NIX specific)

##### Mac OS

1. Download Raspbian Stretch Lite from the [Raspbian archive](http://downloads.raspberrypi.org/raspbian_lite/images/raspbian_lite-2018-06-29/).

2. Insert the SD card and use Disk Utility to check your system for its path:

	```
	$ diskutil list

	/dev/<DISK_NAME> (external, physical):
	#:	TYPE NAME 					SIZE 			IDENTIFIER
	0:	FDisk_partition_scheme		*127.9 GB 		disk2
	1:	Windows_FAT_32				127.9 GB 		disk2s1
	```

3. Unmount the disk:

	```
	$ diskutil unmountDisk /dev/<DISK_NAME>
	Unmount of all volumes on disk2 was successful
	```

4. Start the copying process to flash the image:

	```
	$ sudo dd if=2018-06-27-raspbian-stretch-lite.img of=<DISK_NAME> bs=64m
	```

5. Upon completion, eject the disk and insert into the Raspberry Pi:

	```
	$ sudo diskutil eject /dev/<DISK_NAME>
	Disk /dev/disk2 ejected
	```

##### Linux

1. Download Raspbian Stretch Lite from the [Raspbian archive](http://downloads.raspberrypi.org/raspbian_lite/images/raspbian_lite-2018-06-29/).

2. Insert the SD card and use check your system for its path (to ensure you choose the correct path, list the contents of `/dev/sd*` before and after inserting the card):

	```
	$ ls /dev/sd*
	/dev/sda	/dev/sdb	/dev/sdb1	/dev/sdc	/dev/sdc1
	```

3. Unmount the SD card:

	```
	$ sudo umount /dev/<DISK_NAME>
	```

4. Start the copy process to flash the image:

	```
	$ sudo dd if=2018-06-27-raspbian-stretch-lite.img of=/dev/<DISK_NAME> bs=64M
	```

5. Upon completion, unmount the disk and insert into the Raspberry Pi:

	```
	$ sudo umount /dev/<DISK_NAME>
	```

### 3. Prepare the OS

1. First, connect the Open NSynth Super mainboard to the Raspberry Pi 3, and plug in a screen and keyboard. You can now insert the SD card and power up by connecting a micro USB power supply to the port on the ONS mainboard. The device will power up, and expand the filesystem before rebooting. When the system has booted to a login prompt, enter the default username and password (`pi` / `raspberry`).

2. Connect the device to a network; either using an ethernet cable, or using the built-in wifi of the Raspberry Pi 3 (for instructions, follow [this guide](https://wiki.archlinux.org/index.php/WPA_supplicant#Connecting_with_wpa_cli), starting from 'At this poin run:' around half way down the page; you don't need to set up `wpa_supplicant` as it is preconfigured on the Raspbian image).

3. Update the package list and upgrade any dependencies (this will take up to an hour depending on your internet connection speed):

	```
	$ sudo apt-get update
	$ sudo apt-get upgrade -y
	```

4. Enable SSH, I²C, serial, and SPI on the device in the 'Interfacing Options' of the Raspberry Pi configuration tool (they are listed under 'Interfacing Options' in the main menu of the tool):

	```
	$ sudo raspi-config
	```

5. You should now copy this repository to the device. You can run the following command on your Pi to find out its IP address:

	```
	$ ifconfig | grep inet
	```

	With this information, you can now copy the `open-nsynth-super-master` directory to the device via `scp` (running from your host computer):

	```
	$ scp -r open-nsynth-super-master pi@<DEVICE IP ADDRESS>:~
	```

6. There is a script included 
in the repository which will set up all OS dependencies and establish a file structure in the home directory on the device. To run the script, enter the following commands on the Pi (this will take up to an hour, based on your internet connection speed):

	```
	$ cd /home/pi/open-nsynth-super-master/linux
	$ bash nsynth-setup.sh
	```

	You will be returned to a command prompt when this script has finished running; if there are any errors logged to the console, you should address any issues and re-run the script (for example if any packages are unavailable, or the network connection is lost).

### 4. Copy audio files

You can use the [audio pipeline](../audio) in this repository to create your own audio patches for running on your Open NSynth Super device. To get you started, there are three example audio patches available to download: the [full set (27GB)](https://storage.googleapis.com/open-nsynth-super/audio/onss_full_audio.tar.gz) or ['lite' set (1.7GB)](https://storage.googleapis.com/open-nsynth-super/audio/onss_lite_audio.tar.gz). Whichever approach you take, ensure that the application settings are updated to match the filenames of the patches you've created or chosen.

When you have a directory of audio files (from either source) saved to your computer, copy them to the home directory of the Raspberry Pi. If possible, you should do this directly (by inserting the SD card into your computer); however you can also copy via a network (this will take considerably longer - up to a few hours for the larger sets of audio, depending on the speed of your network connection).

In addition to the audio files, you will need to copy the accompanying settings file(for the [full set](https://storage.googleapis.com/open-nsynth-super/audio/onss_full_settings.json), for the ['lite' set](https://storage.googleapis.com/open-nsynth-super/audio/onss_lite_settings.json)).

```
$ scp -r pads/ pi@<DEVICE IP ADDRESS>:~
$ scp onss_full_settings.json pi@<DEVICE IP ADDRESS>:~
```

When you have installed the application software in a later step, you will need to update the `settings.json` file in the application directory; for now, you can leave it in the home directory.

### 5. Set up the firmware

Having copied all necessary files to the device, you are ready to install the MCU firmware for the Open NSynth Super mainboard. There are detailed instructions on how to approach this in the [firmware readme](../firmware) file. When you have completed these instructions, you can return to this guide and move to the next step.

### 6. Set up the application

The only remaining element to set up on the device is the Open NSynth Super application itself. There is a detailed guide on how to accomplish this in the [application readme](../app) file. Make sure that if you are using an example `settings.json` file that you now move it to the application directory, for example:

```
$ cp onss_full_settings.json /home/pi/opt/of/apps/open-nsynth/open-nsynth/bin/data/settings.json
```

When you have completed these instructions, you can return to this guide and move to the next step.

### 7. Test the configuration

Before assembling the shell and 'finishing' the instrument, it's important to check that everything is functioning correctly. First, power off the device:

```
$ sudo poweroff
```

You can now remove the keyboard and screen from the Raspberry Pi. Connect a pair of headphones or speakers, and a MIDI keyboard (or other MIDI device). You can now power up the device.

After a few seconds, you should see the grid interface appear on the OLED screen. Move your finger around the touch pad to test its responsiveness. Next, adjust the six controls at the base of the unit; the UI should update according to the control that you are adjusting. Finally, test the four instruent selection encoders, which will scroll through an instrument list on the screen.

To test the audio, ensure your MIDI device is broadcasting on the channel you have set in your application configuration (the default channel is 1 for all the sample audio sets) and send some notes to the device. You should hear audio coming from the speakers or headphones (if you don't hear anything, make sure the device audio is turned up, and that the envelope and position controls aren't cutting the audible part of the waveform).

##### Debugging audio

If you aren't able to hear audio, you should power down the device, reconnect the keyboard and screen, and boot it up again. When you see the command prompt, enter the following commands:

```
$ sudo service open-nsynth stop
$ speaker-test
```

If your audio hardware is functioning, you should hear a test sound playing through the connected headphones or speakers.

##### Debugging MIDI

If your audio hardware is working correctly, but you aren't hearing audio played by the application via MIDI, you should first check that your device is broadcasting on the correct channel (this is set in the `settings.json` file in the Open NSynth Super application directory; for more information about the settings file, see the [application readme](../app) file).

##### Controlling the service

You can start and stop the `open-nsynth` service using the following commands:

```
$ sudo service open-nsynth stop
$ sudo service open-nsynth start
$ sudo service open-nsynth restart
```
### 7. Lock the filesystem (optional)

When you have set up your device and are happy with the configuration, it is advisable to lock the file system to prevent corruption upon a hard power down (i.e. when the power cable is removed from the device). Reconnect the keyboard and screen for these steps. 

1. Open `fstab` in a text editor
	```
	$ sudo vi /etc/fstab
	```

2. Add `,ro` to the root partition to lock the filesystem at next boot:

	```
	proc 					/proc           proc    defaults  	        	0 		0
	PARTUUID=7762b82d-01 	/boot           vfat    defaults				0 		2
	PARTUUID=7762b82d-02 	/               ext4    defaults,noatime,ro 	0 		1
	```

3. Reboot, and test the filesystem by using `touch xyz` to create a new file named `xyz`. You should be denied this if the system is in read-only mode.

4. To remount as read-write (to make changes), you can remove the ```,ro``` flag from fstab. To make this change temporarily (e.g. to edit some files), you can remount the filesystem as read-write:

	```
	$ sudo mount -o remount,rw /
	```

When you restart, the filesystem will once more be read-only. Your instrument is now fully set up – you can proceed to build it into a case and start to make music with it!

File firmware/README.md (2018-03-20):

# Open NSynth Super firmware

This firmware is responsible for reading hardware inputs and making that state available to the Raspberry Pi over I²C.

The inputs are:

 - 4 rotary encoders used for instrument selection
 - 6 potentiometers used for altering the sound envelope and volume
 - 2 touch controller ICs used for the touch sensitive grid

The output is an I²C interface using SMBus transactions to send the current state of the inputs.

# Installation guide

These instructions will guide you through the steps needed to build and install the firmware that runs on the Open NSynth Super mainboard microcontroller. For more information about setting up the rest of the system, you should follow first either the [main quick-start guide](https://github.com/googlecreativelab/open-nsynth-super) or the [full Linux setup](../linux) documentation. You should have the Open NSynth Super mainboard connected to the Raspberry Pi, and a keyboard and screen plugged in before starting.

1. If you haven't already copied this repository to the device, you will need to do so. You can run the following command on your device to find out its IP address:
	```
	$ ifconfig | grep inet
	inet addr: <DEVICE IP ADDRESS> Bcast: 255.255.255.0 Mask 255.255.255.0
	```

	You can copy the repository directory to the device from your host computer via SCP:

	```
	$ scp -r open-nsynth-super-master pi@<DEVICE IP ADDRESS>:~
	```

2. In addition to the files in the firmware directory of the repository, you will need some supporting libraries from STMicroelectronics. You can download the files from the bottom of [this page on their website](http://www.st.com/en/embedded-software/stm32cubef0.html). Note that you will have to register with STM in order to download the libraries. When you have downloaded the zip archive, you need to copy it to the device:

	```
	$ scp en.stm32cubef0.zip pi@192.168.0.10:~/open-nsynth-super-master/firmware
	```

	Next, unzip the archive, and rename the unzipped directory so that it can be found by the firmware compile script. (The renamed `cube` directory should be in the `firmware` directory, alongside the `src` directory.)

	```
	$ cd /home/pi/open-nsynth-super-master/firmware/
	$ unzip en.stm32cubef0.zip 
	$ mv STM32Cube_FW_F0_V1.9.0 cube
	```

3. With the files in place, you can now compile and install the firmware:
	```
	$ cd /home/pi/open-nsynth-super-master/firmware/src
	$ make
	$ make install
	```

	You will receive a message similar to the listing below if the installation was successful:

	```
	** Programming Started **
	auto erase enabled
	Info : device id = 0x10006444
	Info : flash size = 32kbytes
	wrote 12288 bytes from file ../bin/main.elf in 0.607889s (19.740 KiB/s)
	** Programming Finished **
	** Verify Started **
	verified 11788 bytes in 0.050784s (226.680 KiB/s)
	** Verified OK **
	** Resetting Target **
	adapter speed: 1001 kHz
	shutdown command invoked
	```

	In order to verify that the firmware is functioning correctly, you will need to install the Open NSynth Super application software; a guide for this is [available here](../app). You can now return to the provisioning guide if you have been following it.

# About the firmware

### Inputs

##### Rotary encoders

The rotary encoders are two channel devices, each one is connected to two digital input pins on the MCU. The state of these pins is monitored at fixed intervals to help with de-bouncing. The input state is represented as an 8 bit integer. When a clockwise turn is detected the input state is incremented by one, and when an anticlockwise turn is detected the input state is decremented by one. The input state is not clamped, it wraps around on overflow.

An application reading these values can detect changes by comparing the current value to the previous value.

##### Potentiometers

The potentiometers are connected to analog input pins and read via the MCUs ADC unit. The input state is an unsigned 8 bit integer.

Because ADC readings are subject to noise the firmware employs two filtering steps. The first as to average many readings together to reduce high frequency noise. The second is to not report sub-bit changes to reduce jitter when the input is close to a bit boundary.

##### Touch controllers

The touch controllers are responsible for reading 11 lines each. Both ICs communicate over I²C but unfortunately have a single fixed address. They are therefore unable to operate on the same I²C bus, so the MCU defines two additional I²C buses - one for each touch IC. The MCU of the Open NSynth Super mainboard has a single hardware I²C unit and this is used to communicate with the Raspberry Pi. The additional buses are defined in firmware by bit banging the pins.

The input state for each axis is an 8 bit integer. The value is 0-10 (inclusive) if a touch has been detected, or 255 (-1) if no touch has been detected. 

### Output

The hardware I²C unit is configured to communicate with the Raspberry Pi. The interface supports separate reads and writes as well as combined write-then-read transactions commonly used for SMBus transactions.

Due to timing constraints all read transactions read from an internal buffer. To update this buffer with the current input state a write transaction must be performed. Thus a typical read cycle consists of a write followed by a read, which again is commonly used for SMBus transactions.

The MCU sends 16 bytes of data for the inputs, followed by a 4 byte checksum. For efficiency the checksum is calculated as a 32 bit value. It is the sum of 0xAA55AA55, the first 32 bits of the inputs, the second 32 bits of the inputs and the third 32 bits of the inputs.

### Hardware used

 - The hardware I²C unit is used for communications with the host. It generates interrupts.
 - A timer (TIM16) is used to generate interrupts for reading the rotary encoders. 
 - The ADC unit is used for reading the potentiometers. It generates interrupts.
 - A timer (TIM17) is used to time the bit banged I²C interfaces.
 
### Priorities

 1. The hardware I²C interrupts are given the highest priority to ensure that communications are reliable.
 2. The rotary encoders are given the next highest priority so that they are read at regular intervals.
 3. The ADC reads are given the lowest interrupt priority.
 4. Reading from the touch ICs is performed as the base task in the main loop.
 
### Compatible devices

This firmware is designed for STM320F030K6Tx devices, and is also drop in compatible with STM320F031K6Tx.

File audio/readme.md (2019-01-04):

# Open NSynth Super audio pipeline

By following this guide, you will be able to prepare audio samples in WAV format, process and interpolate them using NSynth, and deploy them to an Open NSynth Super device.

A fast computer is required to produce audio in a reasonable amount of time; however it is possible to speed up the process by simplifying the task. The variables are:

- Batch size (per process)
- Number of interpolation combinations
- Number of example pitches
- Grid resolution

As an example, a complex interpolation task (e.g. to produce the sounds in the [large example OS image](https://storage.googleapis.com/open-nsynth-super/images/onss_1.2.0_full.img.bz2)) included 4 different sounds in each corner of the instrument for a total of 256 different permutations, a 9x9 grid resolution, and 15 example pitches. (The source audio for generating these patches is available [here](https://storage.googleapis.com/open-nsynth-super/audio/onss_source_audio.tar.gz).)

For reference, a machine with 8 NVidia K80 GPUs, 128GB RAM and 8 CPU cores can generate the nearly 120,000 audio samples produced by this example in approximately 36 hours with a conservative batch size of 512.

By reducing the number of instruments in each corner to 2, the time required is reduced significantly; with a far more modest server (2x GPU, 2x CPU 16GB RAM) it would be possible to produce a patch of this size in a couple of days.

This directory includes a sequence of scripts wrapping core NSynth functions, and for processing and converting audio for deployment on the device.
You will need to a Linux PC or server with at least one CUDA-compatible GPU.

# Key files

`/settings.json` is the settings file which governs each stage of the pipeline. If running on multiple machines, ensure that this is identical across instances.

All work should be performed in the `/workdir` directory. It contains the pipeline scripts, numbered 1 - 6; these stages are:

1. Compute input file embeddings
2. Compute embeddings for the output sounds to be generated
3. Batch the output embeddings for parallel processing
4. Generate audio (this is markdown reference file rather than a script; commands should be run manually)
5. Clean the generated audio files
6. Build pads for deployment on the device

# Setting up your environment
These steps assume you have installed and configured NVIDIA CUDA correctly on your machine, which is outside the scope of this document (if you’ve been able to run Tensorflow GPU on CUDA previously, then these instructions will apply correctly). You may wish to make use of a virtual environment for some steps; this is not documented. Note that you may need additional permissions on your machine (via `sudo`) for some steps if you are installing in global scope.

### Install Bazel:

(More detailed instructions on this step are available from the [Bazel website](https://docs.bazel.build/versions/master/install-ubuntu.html).)
```
$ sudo apt-get install openjdk-8-jdk
$ echo "deb [arch=amd64] http://storage.googleapis.com/bazel-apt stable jdk1.8" | sudo tee /etc/apt/sources.list.d/bazel.list
curl https://bazel.build/bazel-release.pub.gpg | sudo apt-key add -
$ sudo apt-get update
$ sudo apt-get install bazel
$ sudo apt-get upgrade bazel
```

### Python

Check Python version is 2.7 and install / upgrade `tqdm` and `pip`:

```
$ python --version
$ pip install tqdm
$ pip install --upgrade pip
```

### Magenta
Fetch and build Magenta’s multigpu branch

```
$ git clone https://github.com/jesseengel/magenta.git
$ cd magenta
$ git checkout origin/synth-multigpu
$ bazel build //magenta/tools/pip:build_pip_package
$ bazel-bin/magenta/tools/pip/build_pip_package ~/magenta-pip-pkg --gpu
$ cd ~/magenta-pip-pkg
$ pip install -U {filename}
```

Download and install the WaveNet checkpoint file from Magenta on GitHub:

```
$ cd magenta/magenta/models/nsynth
$ wget http://download.magenta.tensorflow.org/models/nsynth/wavenet-ckpt.tar
$ tar xf wavenet-ckpt.tar
```

# Preparing to run the pipeline

### 1. Preparing audio
Open NSynth Super requires one-note samples for each of the desired source sounds across a range of pitches. In the default configuration, these should be 4000ms long. Optionally, you can release the note after 3000ms to leave a decay, however this is subjective, and something to experiment with.

According to the default settings, these files should be created at the following MIDI notes:

- 24 (C2)
- 28 (E2)
- 32 (G#2)
- 36 (C3)
- 40 (E3)
- 44 (G#3)
- 48 (C4)
- 52 (E4)
- 56 (G#4)
- 60 (C5)
- 64 (E5)
- 68 (G#5)
- 72 (C6)
- 76 (E6)
- 80 (G#6)
- 84 (C7)

For instruments that are out of range at any of these pitches, you can pitch down or up using software, or repeat the nearest ‘available’ pitch to fill in the gaps. Alternatively, for unpitched sounds like drums you can maintain a single pitch across all notes, or pitch each one manually.

Changing these conditioning values can result in interesting different combinations and is one of the most interesting and powerful ways to alter the behaviour of the instrument.

Samples should be named using the following convention:

```
[soundname]_[pitch].wav
```

For example, the sound ‘guitar’ would be stored as:

```
guitar_24.wav
guitar_28.wav
...
```

Audio should be saved as 16-bit integer wave files at 16000kHz. See the following soxi output for a valid input file:

```
$ soxi guitar_24.wav

Input File     : 'grungebass_24.wav'
Channels       : 1
Sample Rate    : 16000
Precision      : 16-bit
Duration       : 00:00:04.00 = 64000 samples ~ 300 CDDA sectors
File Size      : 128k
Bit Rate       : 256k
Sample Encoding: 16-bit Signed Integer PCM
```

When you have selected the input audio files you wish to interpolate, they should be placed in the `audio_input` folder in the pipeline working directory. There is a helper script for converting AIF audio files to the correct format in `workdir/helpers`.

### 2. Update the settings file

The entire pipeline process is governed by the settings.json file, which will need to be reflected in the application. For example:
```
{
   "pads":  {
      "NW":       ["brass","caridle", "crotales", "electroclav"],
      "NE":       ["fatpoly", "flute", "softpad", "kick"],
      "SW":       ["marimba", "electricpiano", "snare", "steeldrum"],
      "SE":       ["synthbrass", "cleanbass", "uprightbass", "windfx"]
   },

   "magenta_dir": "~/magenta",
   "pitches":     [24, 28, 32, 36, 40, 44, 48, 52, 56, 60, 64, 68, 72, 76, 80, 84],
   "resolution":  9,
   "final_length": 60000,
   "gpus":        16
}
```

##### pads
The pads property is a map of instrument layout. This object places the source audio files in different corners of the NSynth instrument; its properties are the compass locations of each corner. The lists should reflect the instrument filenames, i.e. ‘guitar’ will point the pipeline to all the correctly named ‘guitar_24.wav’, ‘guitar_28.wav’ files.

##### magenta_dir
This should point to the root directory of your Magenta installation. This is used to locate the WaveNet checkpoint file so should be set to the Magenta installation containing that file if you have multiple installations.

##### pitches
This is a list of the different input pitches that should be interpolated by the pipeline. This (as with all settings) should be reflected in the application settings file to ensure proper indexing of the audio files.

##### resolution
This setting controls how many inter-instrumental interpolations are created. Higher resolutions will create closer and smoother interpolations at a cost of disk space and processing time.

##### final_length
The length in samples of the output wave files.

##### gpus
Set this number to match the number of GPUs your system is equipped with. This will control the number of batches the processes are split into (enabling much faster processing times).

# Running the pipeline

### 1. Compute inpute embeddings

```
$ python 01_compute_input_embeddings.py
```

On occasion, this script can chop the leading character of some filenames, resulting in 'missing file' errors later on in the pipeline. You can use the `correct_truncated_names.py` helper script (in `workdir/helpers`) to correct these filenames in batches.

### 2. Compute interpolated embeddings

```
$ python 02_compute_new_embeddings.py
```

This script interpolates between the input embeddings according to the different permutations of input sounds and resolution. The target embeddings are placed in the `embeddings_output` folder.

### 3. Batch embeddings for processing
```
$ python 03_batch_embeddings.py
```

This script divides the audio embeddings into a folder per-GPU according to the settings file, in the `embeddings_batched` folder.

### 4. Generate audio
This command should be run manually, using the Magenta `nsynth_generate` command. You will need to run this command once for each batch / GPU. It is recommended that you run these commands in a series of detachable terminal sessions (for example using [`screen`](https://linux.die.net/man/1/screen) or [`tmux`](https://linux.die.net/man/1/tmux)) so that you can leave the process running for extended periods of time without having to maintain a session on the machine (even on a multi-GPU server, this process will take tens of hours depending on configuration and process settings).

The command should be invoked as follows:

```
$ nsynth_generate --checkpoint_path=/home/user/magenta/magenta/models/nsynth/wavenet-ckpt/model.ckpt-200000 --source_path=/home/user/nsynth-pipeline/workdir/embeddings_batched/batch0 --save_path=/home/user/nsynth-pipeline/workdir/audio_output/batch0 --batch_size=512 --alsologtostderr --gpu_number=0
```

You should run this command for each batch / GPU, updating the `batchN` file paths and `gpu=N` argument. This process will take a considerable amount of time depending on machine spec and arguments (e.g. batch size; number of input instruments).

### 5. Clean files

New NSynth audio files will be placed in `batchN` folders under the `output_audio` directory. Inside this directory, create a `raw_wav` folder and move all `batchN` folders into it:

```
$ mkdir audio_output/raw_wav
$ mv audio_output/batch* audio_output/raw_wav
```

The cleaning script will convert all input wave files to MP3, normalise them, and export as wave files for packing onto the device. This process is also batched; you can run it once for each batch (put the batch number after the script invocation).

```
$ python 05_clean_files.py 0
$ python 05_clean_files.py 1
...
```

### 6. Build pads
```
$ python 06_build_pads.py
```

This script will pack the wave files into efficient binary files for fast access on the device. It will output a single binary file for each instrument combination to the `pads_output` folder.

### 7. Deploy to the device
The the `pads_output` folder will now contain a binary file for each conmbination of input instruments, ready to load on to the device.

Once you have copied the contents of the `pads_output` folder to the device, you will need to update the `settings.json` file according to the new instrument names and pipeline settings. For more information on this, refer to the [application settings](../app) guide.

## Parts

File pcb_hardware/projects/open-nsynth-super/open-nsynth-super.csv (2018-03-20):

Reference | Value | Footprint | Datasheet
J1 | Raspberry_Pi_2_3 | open-nsynth-super:RPi
J9 | Audio-Jack-3 | open-nsynth-super:KLBR_4
J2 | DIN-5_180degree | open-nsynth-super:MIDI
J3 | OLED13 | open-nsynth-super:oled13
J4 | USB_OTG | Connectors:USB_Micro-B
U4 | TPS73133 | open-nsynth-super:SOT-23-5
C14 | 1uF | Capacitors_SMD:C_1206_HandSoldering
C15 | 1uF | Capacitors_SMD:C_1206_HandSoldering
C16 | 1uF | Capacitors_SMD:C_1206_HandSoldering
U5 | TPS73133 | open-nsynth-super:SOT-23-5
C17 | 1uF | Capacitors_SMD:C_1206_HandSoldering
C18 | 1uF | Capacitors_SMD:C_1206_HandSoldering
C19 | 1uF | Capacitors_SMD:C_1206_HandSoldering
U6 | TPS73133 | open-nsynth-super:SOT-23-5
C20 | 1uF | Capacitors_SMD:C_1206_HandSoldering
C21 | 1uF | Capacitors_SMD:C_1206_HandSoldering
C22 | 1uF | Capacitors_SMD:C_1206_HandSoldering
C23 | 2.2uF | Capacitors_SMD:C_1206_HandSoldering
C24 | 2.2uF | Capacitors_SMD:C_1206_HandSoldering
R2 | 470 | Resistors_SMD:R_1206_HandSoldering
R3 | 470 | Resistors_SMD:R_1206_HandSoldering
C1 | 2.2nF | Capacitors_SMD:C_1206_HandSoldering
C2 | 2.2nF | Capacitors_SMD:C_1206_HandSoldering
C9 | 0.1uF | Capacitors_SMD:C_1206_HandSoldering
C10 | 0.1uF | Capacitors_SMD:C_1206_HandSoldering
R8 | 5k6 | Resistors_SMD:R_1206_HandSoldering
R9 | 10k | Resistors_SMD:R_1206_HandSoldering
C30 | 10uF | Capacitors_SMD:C_1206_HandSoldering
C27 | 10uF | Capacitors_SMD:C_1206_HandSoldering
C11 | 0.1uF | Capacitors_SMD:C_1206_HandSoldering
C28 | 10uF | Capacitors_SMD:C_1206_HandSoldering
C12 | 0.1uF | Capacitors_SMD:C_1206_HandSoldering
C29 | 10uF | Capacitors_SMD:C_1206_HandSoldering
R4 | 470 | Resistors_SMD:R_1206_HandSoldering
R5 | 470 | Resistors_SMD:R_1206_HandSoldering
R6 | 470 | Resistors_SMD:R_1206_HandSoldering
U1 | PCM512x | open-nsynth-super:TSSOP-28_4.4x9.7mm_Pitch0.65mm
U7 | STM32F030K6Tx | open-nsynth-super:LQFP-32_7x7mm_Pitch0.8mm
R32 | 10k | Resistors_SMD:R_1206_HandSoldering
C13 | 1uF | Capacitors_SMD:C_1206_HandSoldering
C6 | 0.1uF | Capacitors_SMD:C_1206_HandSoldering
C7 | 0.1uF | Capacitors_SMD:C_1206_HandSoldering
C25 | 2.2uF | Capacitors_SMD:C_1206_HandSoldering
C3 | 0.01uF | Capacitors_SMD:C_1206_HandSoldering
C8 | 0.1uF | Capacitors_SMD:C_1206_HandSoldering
RV4 | POT | open-nsynth-super:Potentiometer_Alps_RK09K
RV3 | POT | open-nsynth-super:Potentiometer_Alps_RK09K
RV2 | POT | open-nsynth-super:Potentiometer_Alps_RK09K
RV1 | POT | open-nsynth-super:Potentiometer_Alps_RK09K
RV0 | POT | open-nsynth-super:Potentiometer_Alps_RK09K
RV5 | POT | open-nsynth-super:Potentiometer_Alps_RK09K
SW0 | Rotary_Encoder | Potentiometers:Potentiometer_Alps_RK09L_Sleve_Single_Horizontal
SW1 | Rotary_Encoder | Potentiometers:Potentiometer_Alps_RK09L_Sleve_Single_Horizontal
SW2 | Rotary_Encoder | Potentiometers:Potentiometer_Alps_RK09L_Sleve_Single_Horizontal
SW3 | Rotary_Encoder | Potentiometers:Potentiometer_Alps_RK09L_Sleve_Single_Horizontal
C26 | 2.2uF | Capacitors_SMD:C_1206_HandSoldering
U2 | AT42QT2120 | open-nsynth-super:TSSOP-20_4.4x6.5mm_Pitch0.65mm
C4 | 0.1uF | Capacitors_SMD:C_1206_HandSoldering
U3 | AT42QT2120 | open-nsynth-super:TSSOP-20_4.4x6.5mm_Pitch0.65mm
C5 | 0.1uF | Capacitors_SMD:C_1206_HandSoldering
TC1 | touch | open-nsynth-super:touch_cell
TC2 | touch | open-nsynth-super:touch_cell
TC3 | touch | open-nsynth-super:touch_cell
TC4 | touch | open-nsynth-super:touch_cell
TC5 | touch | open-nsynth-super:touch_cell
TC6 | touch | open-nsynth-super:touch_cell
TC7 | touch | open-nsynth-super:touch_cell
TC8 | touch | open-nsynth-super:touch_cell
TC9 | touch | open-nsynth-super:touch_cell
TC10 | touch | open-nsynth-super:touch_cell
TC11 | touch | open-nsynth-super:touch_cell
TC12 | touch | open-nsynth-super:touch_cell
TC13 | touch | open-nsynth-super:touch_cell
TC14 | touch | open-nsynth-super:touch_cell
TC15 | touch | open-nsynth-super:touch_cell
TC16 | touch | open-nsynth-super:touch_cell
TC17 | touch | open-nsynth-super:touch_cell
TC18 | touch | open-nsynth-super:touch_cell
TC19 | touch | open-nsynth-super:touch_cell
TC20 | touch | open-nsynth-super:touch_cell
TC21 | touch | open-nsynth-super:touch_cell
TC22 | touch | open-nsynth-super:touch_cell
TC23 | touch | open-nsynth-super:touch_cell
TC24 | touch | open-nsynth-super:touch_cell
TC25 | touch | open-nsynth-super:touch_cell
TC26 | touch | open-nsynth-super:touch_cell
TC27 | touch | open-nsynth-super:touch_cell
TC28 | touch | open-nsynth-super:touch_cell
TC29 | touch | open-nsynth-super:touch_cell
TC30 | touch | open-nsynth-super:touch_cell
TC31 | touch | open-nsynth-super:touch_cell
TC32 | touch | open-nsynth-super:touch_cell
TC33 | touch | open-nsynth-super:touch_cell
TC34 | touch | open-nsynth-super:touch_cell
TC35 | touch | open-nsynth-super:touch_cell
TC36 | touch | open-nsynth-super:touch_cell
TC37 | touch | open-nsynth-super:touch_cell
TC38 | touch | open-nsynth-super:touch_cell
TC39 | touch | open-nsynth-super:touch_cell
TC40 | touch | open-nsynth-super:touch_cell
TC41 | touch | open-nsynth-super:touch_cell
TC42 | touch | open-nsynth-super:touch_cell
TC43 | touch | open-nsynth-super:touch_cell
TC44 | touch | open-nsynth-super:touch_cell
TC45 | touch | open-nsynth-super:touch_cell
TC46 | touch | open-nsynth-super:touch_cell
TC47 | touch | open-nsynth-super:touch_cell
TC48 | touch | open-nsynth-super:touch_cell
TC49 | touch | open-nsynth-super:touch_cell
TC50 | touch | open-nsynth-super:touch_cell
TC51 | touch | open-nsynth-super:touch_cell
TC52 | touch | open-nsynth-super:touch_cell
TC53 | touch | open-nsynth-super:touch_cell
TC54 | touch | open-nsynth-super:touch_cell
TC55 | touch | open-nsynth-super:touch_cell
TC56 | touch | open-nsynth-super:touch_cell
TC57 | touch | open-nsynth-super:touch_cell
TC58 | touch | open-nsynth-super:touch_cell
TC59 | touch | open-nsynth-super:touch_cell
TC60 | touch | open-nsynth-super:touch_cell
TC61 | touch | open-nsynth-super:touch_cell
TC62 | touch | open-nsynth-super:touch_cell
TC63 | touch | open-nsynth-super:touch_cell
TC64 | touch | open-nsynth-super:touch_cell
TC65 | touch | open-nsynth-super:touch_cell
TC66 | touch | open-nsynth-super:touch_cell
TC67 | touch | open-nsynth-super:touch_cell
TC68 | touch | open-nsynth-super:touch_cell
TC69 | touch | open-nsynth-super:touch_cell
TC70 | touch | open-nsynth-super:touch_cell
TC71 | touch | open-nsynth-super:touch_cell
TC72 | touch | open-nsynth-super:touch_cell
TC73 | touch | open-nsynth-super:touch_cell
TC74 | touch | open-nsynth-super:touch_cell
TC75 | touch | open-nsynth-super:touch_cell
TC76 | touch | open-nsynth-super:touch_cell
TC77 | touch | open-nsynth-super:touch_cell
TC78 | touch | open-nsynth-super:touch_cell
TC79 | touch | open-nsynth-super:touch_cell
TC80 | touch | open-nsynth-super:touch_cell
TC81 | touch | open-nsynth-super:touch_cell
TC82 | touch | open-nsynth-super:touch_cell
TC83 | touch | open-nsynth-super:touch_cell
TC84 | touch | open-nsynth-super:touch_cell
TC85 | touch | open-nsynth-super:touch_cell
TC86 | touch | open-nsynth-super:touch_cell
TC87 | touch | open-nsynth-super:touch_cell
TC88 | touch | open-nsynth-super:touch_cell
TC89 | touch | open-nsynth-super:touch_cell
TC90 | touch | open-nsynth-super:touch_cell
TC91 | touch | open-nsynth-super:touch_cell
TC92 | touch | open-nsynth-super:touch_cell
TC93 | touch | open-nsynth-super:touch_cell
TC94 | touch | open-nsynth-super:touch_cell
TC95 | touch | open-nsynth-super:touch_cell
TC96 | touch | open-nsynth-super:touch_cell
TC97 | touch | open-nsynth-super:touch_cell
TC98 | touch | open-nsynth-super:touch_cell
TC99 | touch | open-nsynth-super:touch_cell
TC100 | touch | open-nsynth-super:touch_cell
TC101 | touch | open-nsynth-super:touch_cell
TC102 | touch | open-nsynth-super:touch_cell
TC103 | touch | open-nsynth-super:touch_cell
TC104 | touch | open-nsynth-super:touch_cell
TC105 | touch | open-nsynth-super:touch_cell
TC106 | touch | open-nsynth-super:touch_cell
TC107 | touch | open-nsynth-super:touch_cell
TC108 | touch | open-nsynth-super:touch_cell
TC109 | touch | open-nsynth-super:touch_cell
TC110 | touch | open-nsynth-super:touch_cell
TC111 | touch | open-nsynth-super:touch_cell
TC112 | touch | open-nsynth-super:touch_cell
TC113 | touch | open-nsynth-super:touch_cell
TC114 | touch | open-nsynth-super:touch_cell
TC115 | touch | open-nsynth-super:touch_cell
TC116 | touch | open-nsynth-super:touch_cell
TC117 | touch | open-nsynth-super:touch_cell
TC118 | touch | open-nsynth-super:touch_cell
TC119 | touch | open-nsynth-super:touch_cell
TC120 | touch | open-nsynth-super:touch_cell
TC121 | touch | open-nsynth-super:touch_cell
R10 | 10k | Resistors_SMD:R_1206_HandSoldering
R11 | 10k | Resistors_SMD:R_1206_HandSoldering
R12 | 10k | Resistors_SMD:R_1206_HandSoldering
R13 | 10k | Resistors_SMD:R_1206_HandSoldering
R14 | 10k | Resistors_SMD:R_1206_HandSoldering
R15 | 10k | Resistors_SMD:R_1206_HandSoldering
R16 | 10k | Resistors_SMD:R_1206_HandSoldering
R17 | 10k | Resistors_SMD:R_1206_HandSoldering
R18 | 10k | Resistors_SMD:R_1206_HandSoldering
R19 | 10k | Resistors_SMD:R_1206_HandSoldering
R20 | 10k | Resistors_SMD:R_1206_HandSoldering
R21 | 10k | Resistors_SMD:R_1206_HandSoldering
R22 | 10k | Resistors_SMD:R_1206_HandSoldering
R23 | 10k | Resistors_SMD:R_1206_HandSoldering
R24 | 10k | Resistors_SMD:R_1206_HandSoldering
R25 | 10k | Resistors_SMD:R_1206_HandSoldering
R26 | 10k | Resistors_SMD:R_1206_HandSoldering
R27 | 10k | Resistors_SMD:R_1206_HandSoldering
R28 | 10k | Resistors_SMD:R_1206_HandSoldering
R29 | 10k | Resistors_SMD:R_1206_HandSoldering
R30 | 10k | Resistors_SMD:R_1206_HandSoldering
R31 | 10k | Resistors_SMD:R_1206_HandSoldering
IC1 | 6N139 | open-nsynth-super:DIP-8_SMD
D1 | DIODE | open-nsynth-super:D_1206
R1 | 220 | Resistors_SMD:R_1206_HandSoldering
R7 | 470 | Resistors_SMD:R_1206_HandSoldering

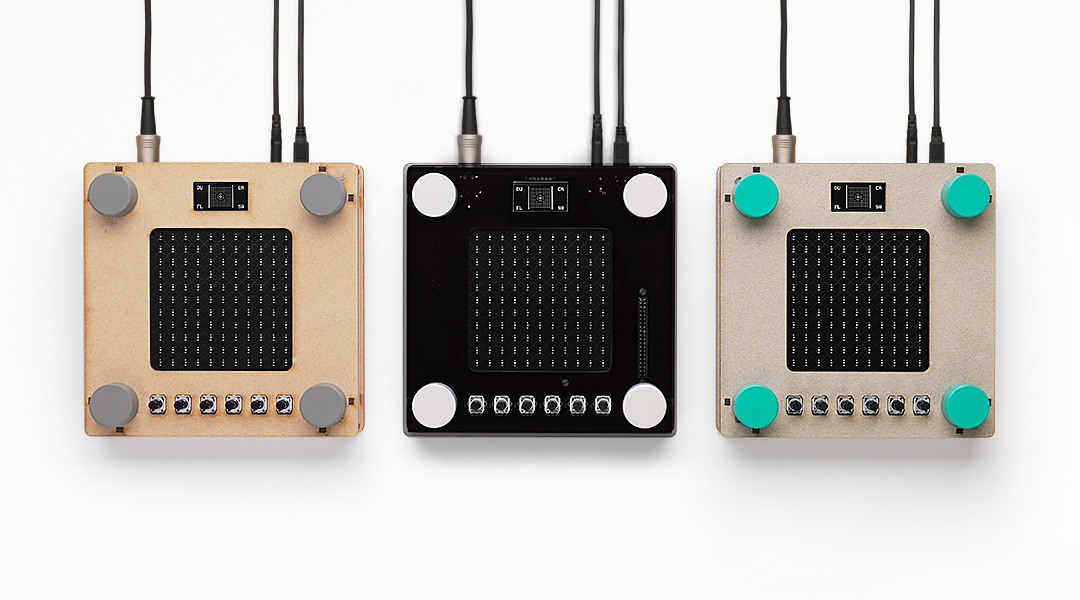
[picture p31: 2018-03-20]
images/ons_case_materials.jpg

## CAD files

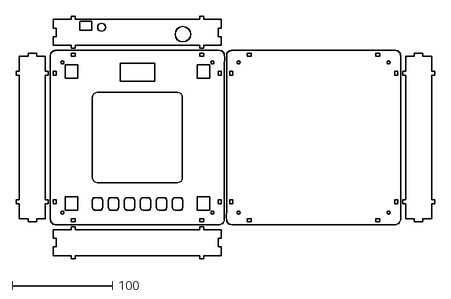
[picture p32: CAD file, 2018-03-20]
case/NSynth_Super_Lasercut_Template.dxf
418.0 x 242.0

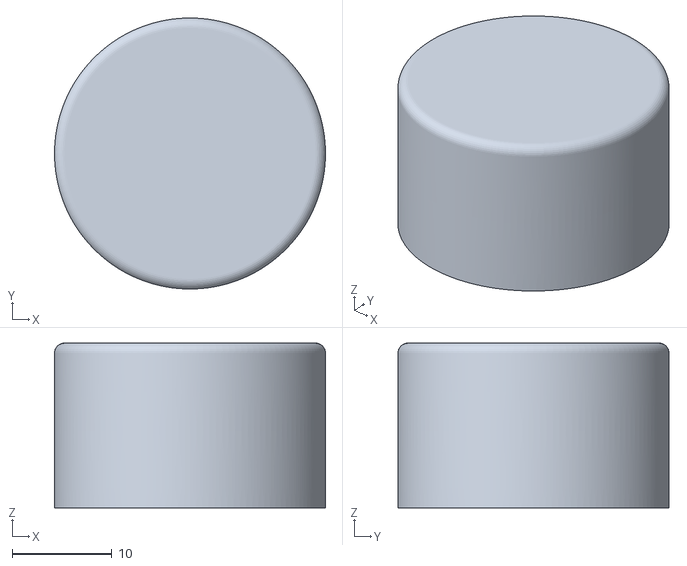
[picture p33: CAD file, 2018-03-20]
case/NSynth_Super_Dial_Big.stl
27.2 x 27.2 x 16.6

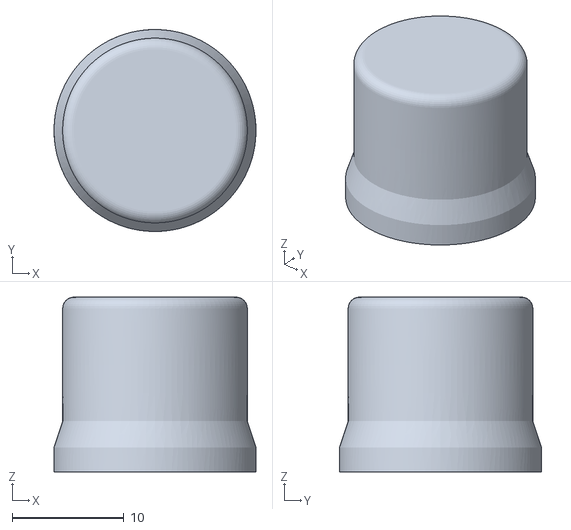
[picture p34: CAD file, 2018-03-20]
case/NSynth_Super_Small_Dial.stl
18.1 x 18.1 x 15.6

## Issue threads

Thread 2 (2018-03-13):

"You will need to obtain or build your PCB before proceeding further with this guide."

FuzzyWobble, 2018-03-13:
Hello :)
What exactly do you mean by "obtain"?

undothis, 2018-03-13:
Are there any builders out there?

Also if there are only 4 sound sources how can there be 100,000 sounds is that because of the variations of the 4 sound sources ?

HelveticaScenario, 2018-03-14:
i just used macrofab.com to order a partially assembled (smt) pcb. took some fiddling around tho

mcnasby, 2018-03-14:
Out of curiousity, what did the cost come to for the board through macrofab? Also, would you be willing to share any of the files you adjusted for use with macrofab?

ensonic, 2018-03-14:
The page make sas one can order the PCB with components, but I can't find any link :/

kasperkamperman, 2018-03-14:
@HelveticaScenario would you mind sharing the other necessary files.

sqfmi, 2018-03-14:
You can get the plain PCB here https://www.tindie.com/products/11702/

axmonti, 2018-03-14:
Ordered the PCB from the above link (cheap!); also created a "pure" Digi-Key BOM:

https://drive.google.com/file/d/1Hz521jbr1duW_I0DMHjfOVAaWWFHkrFS/view?usp=sharing

Note that the BOM doesn't include case hardware (screws, standoffs, etc.) and the only rotary encoder in-stock has 24 detents (instead of 12) - still 12PPR

aaronortiz, 2018-03-14:
Maybe we need a tablet app for this!

sqfmi, 2018-03-14:
The KLBR 4 Audio Connector wasn't available on Digi-Key, so I replaced the footprint with [another audio connector](https://www.digikey.com/product-detail/en/cui-inc/SJ1-3523N/CP1-3523N-ND/738689) in my [fork](https://github.com/sqfmi/open-nsynth-super/tree/master/pcb_hardware/projects/open-nsynth-super). I created a Digi-Key cart as well with all the components [here](http://www.digikey.com/short/jj2rt4), swapped some of the components that were low/out of stock.

HelveticaScenario, 2018-03-14:
the cost of the printing, the smt components, and the labor cost to place them came out to $123.08, without shipping. This doesnt cover any other costs like the through hole components, raspberry pi, screen, case, etc. The modifications i made were actually done inside their interface and i cant find a way to export or share it. ive emailed their support team and hopefully they will get back to me.

sqfmi, 2018-03-15:
@axmonti good call! I updated the footprint to accept switch/no switch connectors

RichardBronosky, 2018-03-15:
Why does this require a PCB? This is insane. RPi + potentiometers + rotary encoders + Android device connected via BLE. Done.

HelveticaScenario, 2018-03-15:
[NSynthSuperMacrofab.zip](https://github.com/googlecreativelab/open-nsynth-super/files/1817418/NSynthSuperMacrofab.zip)
These are the files, let me know if they dont work

ailgun, 2018-03-16:
@aaronortiz you probably can use the NSynth M4L device with MIRA and have it on tablet anyway.

undothis, 2018-03-16:
For some reason the telephone number to buy the PCB’s is not working. Any thoughts?

213-746-7272

Best,

Ory

Sent from the future

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

aaronortiz, 2018-03-16:
@ailgun Can you point me to MIRA? I don't know what it is, sadly.

ailgun, 2018-03-16:
@aaronortiz it's cycling74's iPad application to mirror the Max patches you have.
https://cycling74.com/products/mira

Even magenta uses it in it's 'ai jam' example, you can see it here;
https://github.com/tensorflow/magenta-demos/tree/master/ai-jam-ableton
or here; https://www.youtube.com/watch?v=ZRnbbtqxBEc

My idea was to mirror the NSynth Max for Live patch to the iPad via MIRA so it practically would be a tablet version NSynth Super [without the colours etc]. I don't have time right now but might try to actually implement it and share it here in a few weeks.

sqfmi, 2018-03-17:
You can now get the semi-assembled PCB here https://www.tindie.com/products/11733/

All SMD parts soldered, just need to bring your own pi + discrete components

NullMember, 2018-03-17:
@sqfmi your tindie page says it's just bare PCB. Are you sure SMD parts are soldered?

cameronaaron, 2018-03-17:
I'm wondering this as well! He is the seller though so I trust him

sqfmi, 2018-03-17:
@NullMember @cameronaaron sorry about that, looks like the tindie admins haven't published the listing yet, should be up shortly!

NullMember, 2018-03-18:
@sqfmi interestingly when I search NSynth word on tindie I can see semi-assembled version in results. But when I click the product it's redirect me to your store page

MariusLub, 2018-03-19:
Same for me here, i just ordered the PCB from squaro's link. I wanted the semi assembled one but i just realized It said "plain". What should i be expecting ?

ailgun, 2018-03-19:
@NullMember it doesn't appear when searched as well.
I wonder when will it be online?

cameronaaron, 2018-03-19:
@sqfmi Any ideas when this will be up?

w4ilun, 2018-03-19:
Looks like the link is now up, sorry about the delay!

https://www.tindie.com/products/11733/

sqfmi, 2018-03-19:
Looks like the link is now up, sorry about the delay!

https://www.tindie.com/products/11733/

axmonti, 2018-03-20:
So, while we're waiting for boards/parts, has anyone installed the _[Open NSynth Super audio pipeline](https://github.com/googlecreativelab/open-nsynth-super/tree/master/audio)_ and started to create sounds to load on NSynth? It would be great if there was an initial corpus of sounds to download (either the initial wav files, or a ready-to-load set) and play around with. Complex convolutions appear to take a couple of days to process on decent hardware.

axmonti, 2018-03-29:
@sqfmi Received your board today - looks great - thanks (nice business card as well). Strange that the USPS tracking number provided still indicates that a label has been created but not yet in the system (not sure others have received their board yet). If I knew it was coming, I would have released my Digi-Key BOM, but at least I'll have the parts for a weekend build.

Closed 2018-04-30.

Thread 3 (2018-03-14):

Paste files not included in the renders

HelveticaScenario, 2018-03-14:
it seems that the bottom and top paste files arent included in the renders, is there a reason why or is it a mistake?

nsynthsuper, 2018-03-16:
If these aren't available in the renders you should be able to export them from the PCB CAD project.

Closed 2018-03-16.

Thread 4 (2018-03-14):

What's the best way to manufacture the PCB?

sinosoidal, 2018-03-14:
Hi. I would love to have some recommendations on websites where to produce the PCB from the files provided.

nevvkid, 2018-03-14:
@sinosoidal You can use https://aisler.net/ for example. As well they will provide all the electronic components you need to build the PCB. To source the display / raspberry pi you can probably go to adafruit.com, watterott.com or pimoroni.com

sinosoidal, 2018-03-14:
@nevvkid thanks for your feedback!

sqfmi, 2018-03-14:
@sinosoidal you can also buy the PCB from here https://www.tindie.com/products/11702/

sinosoidal, 2018-03-14:
I have orderedd an hour ago!

yamill, 2018-03-15:
@sqfmi when do you plan on selling a partially assembled and fully assembled pcb?

jonmoshier, 2018-03-16:
There's a facebook group called 'Pusherman', mostly it's DIY Eurorack, but there is a thread there about NSynth. ~$50 for a PCB with the SMD components pre-soldered, shipping in the US and the Cortex M0 has been programmed.

yamill, 2018-03-16:
@jonmoshier Sweet. Thanks for the info! I just tried joining the FB group, still waiting to get access to the group 👍

sqfmi, 2018-03-17:
@yamill we've been trying to sort out the logistics, you can now get the semi-assembled board :) https://www.tindie.com/products/11733/ (PCB + SMD components soldered, you'll need to bring your own pi, etc.)

sqfmi, 2018-03-19:
Looks like the link is now up, sorry about the delay!

https://www.tindie.com/products/11733/

yamill, 2018-03-20:
@sqfmi Amazing! Thank you for coming through! I will definitely place an order.

yamill, 2018-03-20:
@sqfmi just placed my order for the semi assembled. is it safe to say i'll need the following to complete the board?

1 | Adafruit 1.3" OLED display
1 | Raspberry Pi 3
1 | GorillaPi Heatsinks
1 | SanDisk 64GB MicroSD card
6 | Potentiometers
4 | Rotary encoders PEC11R-4315F-N0012
1 | USB socket
1 | MIDI socket
1 | 3.5mm audio jack
1 | tall rpi gpio header

sqfmi, 2018-03-20:
@yamill you'll need everything you've listed except for the USB socket, which comes pre-soldered (the tiny pins can be tricky with a soldering iron)

MariusLub, 2018-03-20:
@sqfmi i bought the plain and semi assembled pcb yesterday on tindie but in the end i only need the semi assembled one. Can you cancel my order for the plain one ? And can i get the money back ?

Thanks !

panfriedcharlie, 2018-03-30:
@sqfmi Just a note, I received my unpopulated board the other day and was impressed with the quality. Thanks so much!

jjsomewhere, 2018-04-10:
Can anybody tell me if there are alternative rotary encoders that would work, or a third supplier for the one specified? In the UK the main supplier specified in the BOM has a 17 week lead time, and the backup supplier has a minimum order of 150. Any suggestions welcome!

panfriedcharlie, 2018-04-11:
@jjsomewhere I'm just _guessing_ here that many PEC11R parts will work keeping in mind the important aspects. Considering the data sheet, you're definitely going to want a PEC11R-4 part. Both detent options 2 and 3 have the same pulse count.

The next designator in the part no. is shaft length (15, 20, 25, 30mm). One could reasonably assume that the shaft length would make little difference to the part's operation and would more have to do with whether the knob fit. So if you're fine running without a knob or with a knob that floats slightly above the case, you should be good with any length.

The next designator is the shaft style. F (flatted) if you are going to use a knob. K (knurled) if you aren't or don't care.

The BOM has been updated to mention that either the switch (S) or no switch (N) versions are compatible.

The final designator is the resolution. Keep in mind that when you play with resolution and detents, you're looking at varying degrees of responsiveness.

jjsomewhere, 2018-04-11:
@panfriedcharlie Thankyou for your detailed reply, very helpful. I'll look in more detail later but I *think* that means the components I'm looking at, which differ only in the detant, should work fine. Their detant is double the resolution compared to the one specified, but so long as that's only a UI thing and doesn't feed back to the circuit it shouldn't make any difference. But I'll look around a bit more later and explore the other options, and maybe order an alternative and test them both before soldering anything. Thank you again.

KyleWerle, 2018-04-11:
I have the NSynth Super running pure data right now. Can't imagine why it wouldn't be able to run another magenta experiment setup.

jjsomewhere, 2018-04-12:
Humm interesting @kylewerle, I have an NSynth PCB in the post, will experiment!

elimuro, 2018-05-09:
@ailgun check out this page on the digikey.ca website https://www.digikey.ca/products/en?FV=ffeca563 . there are other versions that should work fine that have longer or shorter knob length if you are ok with that

ailgun, 2018-05-09:
@elimuro thanks a lot. I have checked these out but I have already 3D printed the large dials. Would any of these fit right into it? I can do some minor edits by maybe carving it etc. but I can't say I'm a very handy person so I feel like I should buy the exact thing :)

jjsomewhere, 2018-05-09:
@elimuro I went with PEC11R-4215F-S0012
 , but I haven't built the NSynth yet so can't confirm that it works.

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

fakemau5, 2018-05-10:
@elimuro @jjsomewhere I built it with PEC11R-4215F-S0012 too and can confirm they works. The only downsides:
* you'll need to bend or cut the 2 extra legs (unused) to fit the board
* due to the doubled encoder resolution (24 steps instead of 12) the instrument changing is triggered every 2 steps on the knob.

jjsomewhere, 2018-05-10:
@elimuro @jjsomewhere Ah ha, thank you @fakemau5, useful info. That's what I suspected. I might think about getting a PEC11R-43 with a different knob length, as not building quite yet. Then again it isn't critical.

jjsomewhere, 2018-05-10:
@elimuro @jjsomewhere @fakemau5 I just had another look around, Mouser in the UK (and so maybe elsewhere) have 66 of the PEC11R-4315K-S0012 in stock. This appears to be identical to the PEC11R-4315F-S0012 except that it had a knurled knob rather than a smooth one. I just ordered some.

ailgun, 2018-05-10:
@jjsomewhere thanks for the info. Do you have any idea would these fit in to the 3D printed large dials?

jjsomewhere, 2018-05-10:
@ailgun Sorry, I can't say for certain. My guess is probably not exactly, but they're both 6mm shafts so it won't be far off. But I'm sure there are plenty of other knobs out there that will fit a 6mm knurled shaft, or models to print from on somewhere like Shapeways? I'm just going to wing it and see what works when I get to it.

ailgun, 2018-05-10:
@jjsomewhere Thanks a lot, I think I'll go with these and see if they'll fit or not - I can maybe carve inside or something if they don't exactly fit.

Also, would these work PEC11R-4215F-N0024? I found these on another seller.

Thanks a lot really and sorry for the hassle, this is an area I'm totally alien to!
--

jjsomewhere, 2018-05-10:
No problem, my background's software, so the electronics stuff is new to me as well. Bourns have a pdf on their website which interprets the product codes for the PEC11R series (bottom of page one). http://www.bourns.com/docs/Product-Datasheets/PEC11R.pdf Don't rely on my interpretation but from what I understand that one would probably *not* work. It has 24 detents per revolution and 24 pulses, whereas the specified encoder as 12 of both.

ailgun, 2018-05-12:
@jjsomewhere Thanks a lot for the information, it seems I'll be going with PEC11R-4315K-S0012's and can buy again by September if these don't exactly work.

Closed 2018-04-30.

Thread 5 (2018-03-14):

Colour touch LCD version

rphi, 2018-03-14:
Are you likely to publish schematics for the model in the demo video with the colour touch LCD display? Although I appreciate the model here is designed to be simpler to build, having such a large display makes the thing look even more awesome, so if it weren't too expensive to do I'd love to give that model a try.

Cheers,
Rob

benjigreig, 2018-03-14:
Agreed. I'd love to be able to build that version too.

DaveRGP, 2018-03-14:
Absolutely agree

supchikov, 2018-03-14:
Want to build version with touch screen. Please, share it.

RichardBronosky, 2018-03-15:
Please do not bring new touch screens into the world!

We discard millions of Android and Apple phones every year. When planning any Maker project that needs an interface, find a way to allow people to repurpose these displays. (I don't mean disassembling the display. I mean via USB, BLE, even GPIO on known devices.) It makes me sad to see that you ever even designed that complicated PCB touch grid.

nsynthsuper, 2018-03-16:
Thanks for your interest Rob, the unit you refer to with the touch screen was designed as an experience prototype for developing the interface and we have no plans to release the source files.

Closed 2018-03-16.

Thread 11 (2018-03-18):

Can't setup network

doodlegabe, 2018-03-18:
When trying to use `sudo wpa_cli` it hangs 'Could not connect to wpa_suplicant:wlan0 - re-trying`. When I trace the wpa_cli I see it repeating that it's a read-only file system.

Do we need to set up an new wpa_supplicant.conf someplace outside the locked image?

----

Was able to connect by remounting and editing the wpa config. Maybe instruction change?

nsynthsuper, 2018-03-19:
You can temporarily remount the filesystem as rw to make changes to configuration:

`$ sudo mount -o remount,rw /`

When you reboot the filesystem will mount as RO again, unless you update that setting in fstab (it's recommended to keep as RO to protect against cuts of power)

Closed 2018-03-19.

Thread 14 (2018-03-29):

Raspberry Pi mounting

FHIM, 2018-03-29:
I've been going through the documentation to see how the Raspberry Pi needs to be mounted, but I couldn't find any pictures. Everything else, like the OLED, the enclosure and all the mechanical parts is very well documented (hats off!), but it seems to be missing for the R Pi.

KyleWerle, 2018-03-29:
The USB ports go towards the potentiometers. If you try to put it in any other way the rPi will be extruding pretty far off the main board.

I currently have an updated laser cut file for exposing the USB ports on the rPi.

FHIM, 2018-03-29:
Ah, thanks for your quick response!

Closed 2018-04-30.

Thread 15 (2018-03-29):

Touchscreen

relaxis, 2018-03-29:
Hi there, I can see a massive difference between this model and the one posted by Google which is the touchscreen is missing from this design. Is there a way to include the touchscreen from adafruit instead of the capacitative pad?

panfriedcharlie, 2018-03-30:
@relaxis This was addressed in a [previous issue](https://github.com/googlecreativelab/open-nsynth-super/issues/5), since closed. The answer is you will have to design, build, and program such an implementation yourself. 😄Quote:

> the unit you refer to with the touch screen was designed as an experience prototype for developing the interface and we have no plans to release the source files.

relaxis, 2018-03-30:
Righto, what did I expect from an "open" project from Google.

Closed 2018-04-11.

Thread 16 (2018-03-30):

directory discrepency in onss_1.1_full.img

panfriedcharlie, 2018-03-30:
Hi! Great project! The build was really fun, hope I didn't mess it up. 😜So I wrote 'onss_1.1_full.img' to a 64GB card and tried to follow the instructions in the firmware installation section of the make guide. It tells me:

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

Problem is I can't find the directory 'open-nsynth-super-master' anywhere on the card. I found 'open-nsynth-super' -- which leads down the same hierarchy of directories -- but when I 'make install' from there, I get an error: "could not intialize the debug port."

Any thoughts? Thanks in advance!!

KyleWerle, 2018-03-30:
In the lite image the directory was also /home/pi/open-nsynth-super/firmware/src

The -master would only be relevant if you were downloading the source files on a fresh image as that is what the guide seems to be based on.

A problem may be that you must run make before make install?

`$ cd /home/pi/open-nsynth-super/firmware/src`
`$ make`
`$ make install`

panfriedcharlie, 2018-03-31:
@KyleWerle thanks so much for your reply. I tried running "make" and I get:

> make: Nothing to be done for 'all'.

I tried the lite build this time and still got after I tried "make install":

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

Any thoughts? A few notes:

I see a lightning bolt in the upper right-hand corner of the screen. I'm using a pi 3 specific power adapter. Could that cause such an issue?

Also, should the OLED light up at all when plugged into HDMI before firmware install? It does not, does that mean something is screwy or does it need the firmware and hardware controllers to work?

Thanks again!

KyleWerle, 2018-03-31:
The STM firmware is what connects all the controls and oled screen to the rPi. To utilize all of those you will need to write the STM firmware.

It sounds like you are having a connection issue between the STM board and your rPi. Possibly double check the board? Is it the correct STM chip? Solder bridges? There are 2 STM chips that should be compatible.

panfriedcharlie, 2018-03-31:
Thanks @KyleWerle! I reflowed the ICs and Pi socket. Still no luck. Time to sit down and have a really close look at everything! Thanks again for the advice.

KyleWerle, 2018-03-31:
Good luck!

panfriedcharlie, 2018-03-31:
@KyleWerle Okay, yeah, my dumb fault. After another reflow and some fastidious cleaning I was able to write the firmware. Seems to be working okay now...

SarahHopeB, 2018-04-05:
I'm at the same step now and having difficulty with the make process as well.  I'm also using the lite image. I was able to successfully run make, when invoking make install I receive an error:

_BCM2835 GPIO nums: swclk = 25, swdio = 24
BCM2835 GPIO config: srst = 23
srst_only separate srst_gates_jtag srst_push_pull connect_deassert_srst
srst_only separate srst_nogate srst_push_pull connect_deassert_srst
adapter_nsrst_delay: 100
adapter_nsrst_assert_width: 100
Info: BCM2835 GPIO JTAG/SWD bitbang driver
Info: SWD only mode enabled (specify tck, tms, tdi and tdo gpios to add JTAG mode)

**Error: An adapter speed is not selected in the init script. Insert a call to adapter_khz or jtag_rclk to proceed.

Makefile:40: recipe for target 'install' failed
make: *** [install] Error 1**_

So, after some Googling, I added the line into the openocd.cfg file...
adapter_khz 1001

From looking at the post above and seeing that 1001kHz was the selected adapter speed.  But still, no dice... It's now exiting with:

_BCM2835 GPIO nums: swclk = 25, swdio = 24
BCM2835 GPIO config: srst = 23
srst_only separate srst_gates_jtag srst_push_pull connect_deassert_srst
srst_only separate srst_nogate srst_push_pull connect_deassert_srst
adapter_nsrst_delay: 100
adapter_nsrst_assert_width: 100
Info: BCM2835 GPIO JTAG/SWD bitbang driver
Info: SWD only mode enabled (specify tck, tms, tdi and tdo gpios to add JTAG mode)
Info: clock speed 1001 kHz

**Error: BUG: current_target out of bounds
Makefile:40: recipe for target 'install' failed
make: *** [install] Error 255**_

Long story short, would someone on this thread who had a successful firmware flash care to show me what the openocd.cfg file looked like?  To my eyes it looks like it's simply not the right *.cfg that I'm using as the TargetName: stm32f0x.cpu isn't being found??

SarahHopeB, 2018-04-05:
I'm wondering if this is any way related to the fact that I had to use a mirror site for installing openocd yesterday.... The version I am using is Open On-Chip Debugger 0.10.0 -- Could someone confirm which version of openocd ended up working?

SarahHopeB, 2018-04-05:
Resolved this issue, reference the first problem with openocd repo being down: https://github.com/googlecreativelab/open-nsynth-super/issues/22

Once re-installing openocd from the secondary source within the makefile, I was able to execute 'make install' and received the same error code as @panfriedcharlie ...

Then after inspecting the PCB I found that the STM chip pin 1 is not located to the upper-left when facing text on the IC. Instead, it is registered with the indentation. After rotating the chip on the board I was able to flash the firmware.

I'm all set!

panfriedcharlie, 2018-04-05:
@SarahHopeB I ~almost~ had that same issue. I second-guessed myself and zoomed waaay in on the build photos to check the dot orientations. Still too lazy to look up the pins and check the schematics. Glad you were able to solve the problem!

KyleWerle, 2018-04-09:
I ended up lining the dot / orientation marker on all the parts with the very small extra line on the silkscreen for the ICs.

SarahHopeB, 2018-04-10:
That's a great idea. I would also add a larger diode cathode band to the
opti-isolator midi circuit.  I had swapped the orientation initially due to
my squinty eyes...

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

KyleWerle, 2018-04-11:
We just need open source telescopic retinal enhancements and we'd be good.

USERxUNKNOWN, 2018-04-17:
Hey. So I used this image and it is asking for a login and password.  Any ideas?

SarahHopeB, 2018-04-17:
Asking for login/password at which step?

On Mon, Apr 16, 2018 at 11:14 PM USERxUNKNOWN <notifications@github.com>
wrote:

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

KyleWerle, 2018-04-17:
The default user is **pi** , and the password is **raspberry**.

Closed 2018-04-30.

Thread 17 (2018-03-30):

Multidimensional Polyphonic Expression (MPE) Support?

EchozAurora, 2018-03-30:
I'm on a waitlist to order a PCB to build an NSynth Super at the moment so it may be a bit before I'm able to test this, but I'm curious whether MPE is supported by this?

If not familiar, this is a new specification recently adopted by MIDI and allows multidimensional controllers such as the LinnStrument and Seaboard to add pitch bends, vibrato, etc to individual notes rather than the all of the notes played simultaneously.

If not currently an option, I'd love to see it in a future addition to the hardware/software 👍

Here is a link to MIDI's release on the standard for more info:
https://www.midi.org/articles/midi-polyphonic-expression-mpe

nsynthsuper, 2018-04-13:
The unit currently supports MIDI notes and velocity, but this would be a terrific thing to add to the code.

Closed 2018-04-13.

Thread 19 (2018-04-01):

Maximum Resolution for Capacitive Grid

KyleWerle, 2018-04-01:
Currently the capacitive touch grid is mapped to 0-10 or a point per touch IC sensor on each axis.

Is it possible to map the cap touch grid to a higher resolution?
Looking at the datasheet for the ICs suggests it is possible for much higher resolution with triangular trace designs.

nsynthsuper, 2018-04-30:
Hi Kyle – this would be an interesting experiment for sure. Bear in mind that you'll have to increase the resolution of the audio generation as well to match, which will result in larger audio binaries, fewer combinations, or a much larger SD card.

Closed 2018-04-30.

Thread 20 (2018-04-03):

Compatible with Raspberry Pi 3 Model B

jonas18z, 2018-04-03:
Is this Compatible with Raspberry Pi 3 Model B or only the standard Pi3?

KyleWerle, 2018-04-04:
The new one is the rPi 3 b+. I am also curious. I currently have 2 NSynth Supers on rPi 3 model b and they run well.

nsynthsuper, 2018-04-11:
This hasn't yet been tested with the 3B+. It is likely that it will **not** work out of the box, however, as it looks like the 3B+ requires the latest version of Raspbian; some effort & debugging will probably be needed to get everything running with the latest board.

Closed 2018-04-11.

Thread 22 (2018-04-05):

Cloning OpenOCD fails in nsynth-setup.sh

SarahHopeB, 2018-04-05:
The git tree on sf.net for openocd is down, [reference here](http://sourceforge.net/p/openocd/code/).  The Nsynth bash file would hang on the "Cloning into 'openocd' step.  I had to modify nsynth-setup.sh to pull from the [secondary (official) git repo](http://repo.or.cz/w/openocd.git) for openOCD:

git://repo.or.cz/openocd.git

(This is for future info... not really a bug, but in case someone else runs into the same issue in the meantime)

nsynthsuper, 2018-04-30:
Thanks for the info Sarah

Closed 2018-04-30.

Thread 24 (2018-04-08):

Odd grid behavior

axmonti, 2018-04-08:
After building, installing, and successively testing the board with the Raspberry Pi 3 model B connected to a monitor, I shut down the system and tested the board in standalone mode. For some reason, the y-coordinate becomes “stuck” on the third row from the bottom, and by stuck, I mean that it’s quite difficult (but not impossible) to coax the grid indicator on the panel to move up or down to another y-coordinate by pressing on another row for a few seconds (the x-coordinate works fine).

On a whim, I plugged in the HDMI cable again, and the grid started working normally (and back to ‘sticky’ grid behavior when the cable is unplugged). I tried the 64GB image, but it had the same issue. It’s almost as if there’s an imaginary line on the 3rd-last row that make it difficult to cross when nothing is plugged into the HDMI port (unplugging or plugging in the mouse and keyboard had no effect).

Had anyone had the same odd grid behaviour? Could it have something to do with the model B and/or video driver? I double-checked the grid behaviour right to the IC pins with a scope and can’t see anything unusual between working and not working modes, which makes me think it’s software-related.

SarahHopeB, 2018-04-10:
Hmm.. That sounds like a strange correlation between HDMI cable and the grid...  Do you notice any differences in ground (floating, maybe?) when the HDMI cable is plugged in?  Are you sure you don't have any bridged pins on the IC or the pull-up/down resistors near the grid?

axmonti, 2018-04-10:
I originally had a solder bridge between pins 11 and 12 of U2, but that also shorted out power to the MCU from U6, so it was fairly easy to track down and rectify. Based on the correct touch behaviour when the HDMI cable is connected, I didn't think there was any lasting harm to the chip (or any others), and U2 controls the x-axis, which appears to work just fine.  That being said, I'll order two replacement touch chips on my next Digi-Key order (just in case). I also checked every trace passthrough to every resistor (especially for row 3), and they're all ok - nothing shorted.

I also left the board alone long enough for the Pi's 'screensaver' to kick-in (even though there wasn't a display attached). When I tried the touch surface, it worked normally until I chose another sound, at which point, an interrupt 'woke up' the display and the 'cursor' became stuck on the 3rd last row again.

I'm currently modifying ParticleScreen to display diagnostics on the oled, but a floating ground didn't occur to me, I'll first have a look from that PoV tonight - thanks for the suggestions!

axmonti, 2018-04-11:
Ok, good thinking on the ground issue - if I connect an external ground to any ground point on the board or the Pi, the touch panel works perfectly. As soon as the ground is disconnected, the cursor becomes stuck on row 9. The same goes for my hand - as long as I'm touching a ground point, the panel works normally. I'm not at all sure why row 9 is the only row affected; it's connected to pin 7 of U3, and the other side of the pullup is connected to the capacitive trace - all in keeping with every other row. I re-checked component connected to ground for continuity and 'leaks' with nothing found. Any additional thoughts/things to try would be appreciated.

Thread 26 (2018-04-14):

PCB table lists all components except D1

dillontiner, 2018-04-14:
The table of reference codes for the surface mount components printed on the back of the pcb contains every component except the diode, which is [listed](https://github.com/googlecreativelab/open-nsynth-super/blob/master/pcb_hardware/projects/open-nsynth-super/open-nsynth-super.csv) as D1. There's an unlisted connection labeled D1 to the right of the display. The below image shows the D1 connection at the top right and the list on the far right.

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

Closed 2018-04-30.

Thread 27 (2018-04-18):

OLED screen won't turn on.

USERxUNKNOWN, 2018-04-18:
I have tried resoldering the jumpers and the pins but nothing is powering it.  Nsynth makes noise when plugged into my MPC. So I know that at least works.  Any ideas? Is there a firmware for the OLED that I am maybe missing?

KyleWerle, 2018-04-18:
I don't think the MIDI goes through the STM and goes directly from the optocoupler input to the rPi.
I'm pretty sure it is the same for the OLED, but with the way the nsynth app works it may not refresh correctly without the Firmware for the STM? I'm not entirely sure.

You may need to double check that you have flashed your STM with the nsynth firmware.

`$ cd /home/pi/open-nsynth-super/firmware/src`
`$ make install`

You should get a confirmation similar to this after successfully flash the STM
```
** Programming Started **
auto erase enabled
Info : device id = 0x10006444
Info : flash size = 32kbytes
wrote 12288 bytes from file ../bin/main.elf in 0.607889s (19.740 KiB/s)
** Programming Finished **
** Verify Started **
verified 11788 bytes in 0.050784s (226.680 KiB/s)
** Verified OK **
** Resetting Target **
adapter speed: 1001 kHz
shutdown command invoked
```

Good luck!

nsynthsuper, 2018-04-19:
The OLED doesn't require any firmware itself, if it's connected and working then it should power up. Regarding the firmware, if you can hear a difference when you turn the encoders and potentiometers then you will know that the firmware is installed and running correctly.

If you have a spare Arduino lying around then it may be worth using it to test the screen module you've got using the Adafruit example library.

acbakhit, 2018-04-20:
I too am experiencing no display on my OLED, this is actually the second display I'm trying too, I'm thinking chances are low having two bad displays? Any other way of troubleshooting the display?

tekfunk, 2018-05-07:
+1

My display is not working as well.  When I hook up a monitor to the Pi, I can see the simulated display and all the knobs are working.  Is there not something that we can run on the pi that can look for the display?

USERxUNKNOWN, 2018-05-13:
*Bump

nsynthsuper, 2018-05-14:
Per the previous comment, it would be worth checking that the OLED is functioning correctly using an Arduino or other separate device. Following that, you should check for continuity and shorts on your ONS board.

rockycamp, 2018-05-14:
A note of caution with this part of assembly - some separation of the boards is advisable when soldering pins to the respective pads as this will avoid solder bridges that can get sandwiched between boards. That said, I have yet to get the OLED working. I have checked power and traced data and clock to the STM. I have also confirmed functionality of the OLED with arduino. Using 16Gb image. Firmware successfully flashed. Controls, audio and midi are all working.

WellDrestGhost, 2018-05-29:
I am having similar issues as stated above.
I am using the 16GB LITE  version of the firmware disk image.  I have my Raspberry Pi 3 connected via HDMI to a monitor, as well as a keyboard.  When the Rpi boots up, I can see what should display on the Nsynth's OLED in the upper-left hand corner.  When I press keys to login and start the firmware installation, I am able to hear sounds (as if i pressed a key on a midi keyboard)  coming out of the 3.5mm audio jack.   I am able to turn the encoders, and the 6 potentiometers and move my finger around the touch pad with the display on my monitor responding correctly.  After installing the firmware (via the instructions) I no longer get audio when pressing the keyboard.  My OLED screen does not show a display (even after reseting) and I am not getting any response from a  plugged in MIDI keyboard or Audio from the 3.5mm jack.  I tried to get audio of the Rpi's audio jack, and still no response.  I cannot see any physical solder bridges or shorts, however I am not ruling that out.  Any ideas?

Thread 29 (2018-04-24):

MIDI over USB

nwesthoff, 2018-04-24:
I would like to send MIDI over USB from a [Traktor Pro Remix Deck](https://support.native-instruments.com/hc/en-us/articles/212536009-How-to-use-TRAKTOR-s-Step-Sequencer-with-a-TRAKTOR-KONTROL-F1-Controller) (in step sequence or one-shot mode) to be able to use the NSynth in a live environment while DJ'ing.

Is it possible to send MIDI over USB? Or do I _have_ to use the 5-pin DIN port?
I couldn't find anything about it in the docs, and would try myself, but I'm currently waiting for the PCB to arrive.

KyleWerle, 2018-04-24:
The NSynth can only send / receive MIDI over USB as a USB Host. It is less easy to send MIDI between two host computers. There are many ways to do what you want, but very few of them are easy to setup and none as easy as connecting the NSynth Super to your computer with a USB cable.

The easiest solution in this case is to use a USB to MIDI DIN Adapter.

nanu-c, 2018-05-15:
This is easly done by adding the ofxMidi library to the app

nanu-c, 2018-05-15:
I can expand the openframeworksapp to do that and it's only some 20 lines of code

nanu-c, 2018-05-15:
* get a version of ofxMidi that works with yout version of openframeworks for 0.9.8
`$ cd /home/pi/opt/of/addons && git clone https://github.com/danomatika/ofxMidi/`
* add `ofxMidi` to ~/opt/of/apps/open-nsynth/open-nsynth/addons.make
* in  /home/pi/opt/of/apps/open-nsynth/open-nsynth/src/ofApp.h add at the beginning after the includes `#include "ofxMidi.h"` and  change line 35 to
`class ofApp : public ofBaseApp, public ofxMidiListener{`
* add at line 73
```
               // the midi stuff
                void newMidiMessage(ofxMidiMessage& eventArgs);
                ofxMidiIn midiIn;
                ofxMidiMessage midiMessage;
```
* In  /home/pi/opt/of/apps/open-nsynth/open-nsynth/src/ofApp.cpp change after line 77 add at end of void ofApp::setup() -> adapt this to your needs

```
	// print input ports to console
	midiIn.listPorts(); // via instance -> comment this line when done
	//ofxMidiIn::listPorts(); // via static as well

	// open port by number (you may need to change this)
	midiIn.openPort(1);
	//midiIn.openPort("IAC Pure Data In");	// by name
	//midiIn.openVirtualPort("ofxMidiIn Input"); // open a virtual port

	// don't ignore sysex, timing, & active sense messages,
	// these are ignored by default
	midiIn.ignoreTypes(false, false, false);

	// add ofApp as a listener
	midiIn.addListener(this);

	// print received messages to the console
midiIn.setVerbose(true);
```
* add at the end of ofApp.cpp
```
void ofApp::newMidiMessage(ofxMidiMessage& msg) {
		midiMessage = msg;
	// ofLog(OF_LOG_NOTICE,"channel: " + ofToString(midiMessage.channel) + " control: "
	// + ofToString(midiMessage.control) +" value: " + ofToString(midiMessage.value)+" pitch: " + ofToString(midiMessage.pitch)
	// +" velocity: " + ofToString(midiMessage.velocity));
		int idx;
		idx = midiMessage.pitch;
		if (msg.velocity == 127){
			synthMutex.lock();
			synth.on(idx);
			synthMutex.unlock();
		}
		else{
			synthMutex.lock();
			synth.off(idx);
			synthMutex.unlock();
		}
}
```
* in ~/opt/of/apps/open-nsynth/open-nsynth run `$ make -j4`
* stop nysth service `sudo service  open-nsynth stop`
* run compiled app `$ bin/open-nsynth`

hagan66, 2018-08-29:
Has anyone done this and prepared a ready-to-go image file? I have no recent programming experience but I would very much like my Nsynth to speak USB. :-)

gitunit, 2019-01-07:
@nanu-c thx for the code. there is a minor typo though. it should be "listInPorts()" instead of "listPorts" at least in the latest version of ofxMidi.

nanu-c, 2019-01-08:
it's different, you have to put a usbmidi device in the raspberry pi. Like a akai or so.
If you wan't to use your pcb as usbmidi it's not possible like that because I  think the usb connector on the pcb is only for power.

if you want use the touch/knobs as midi input and send it to a other machine there a 2 common ways to do it.
1. connect the rpi to your windows network

2. use either https://github.com/hiroyuki/ofxArtnet for Artnet or

osc depending what is supported py the program you try to use in windows.
 https://github.com/openframeworks/openFrameworks/tree/patch-release/addons/ofxOsc https://www.youtube.com/watch?v=TczI-tSOIpY

gitunit, 2019-01-08:
ok. i get it. thx for clarification. btw. im from vienna, too. saw your homepage. nice projects ;)

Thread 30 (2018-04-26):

compute input embeddings error: "no such file or directory"

nwesthoff, 2018-04-26:
running `$ python 01_compute_input_embeddings.py` from `~/open-nsynth-super/audio/workdir` to test the pipeline gives me an `OSError: [Errno 2] No such file or directory`

I split up the subprocess.call to get a more specific line, though I don't think that worked (it breaks on the last line regardless).

Traceback:
```
Traceback (most recent call last):
  File "01_compute_input_embeddings.py", line 31, in <module>
    subprocess.call(["nsynth_save_embeddings", "--checkpoint_path=%s/magenta/models/nsynth/wavenet-ckpt/model.ckpt-200000" % settings['magenta_dir'], "--source_path=%s/audio_input" % source_dir, "--batch_size=64", "--save_path=%s/embeddings_input" % source_dir])
  File "/usr/lib/python2.7/subprocess.py", line 523, in call
    return Popen(*popenargs, **kwargs).wait()
  File "/usr/lib/python2.7/subprocess.py", line 711, in __init__
    errread, errwrite)
  File "/usr/lib/python2.7/subprocess.py", line 1343, in _execute_child
    raise child_exception
OSError: [Errno 2] No such file or directory
```
all folders exist and are readable, writeable and executable by current user

I think it might have to do something with the wavenet-ckpt folder which contains `checkpoint`, `model.ckpt-200000.data-00000-of-00001`, `model.ckpt-200000.index` and `model.ckpt-200000.meta` but no `model.ckpt-200000`

nwesthoff, 2018-04-26:
Scratch that. I think it has trouble locating `nsynth_save_embeddings`, which is in `~/magenta/magenta/models/nsynth/wavenet`, not inside the workdir, is this incorrect on my part? or an error in the python script? I'm also not sure what the best way is to fix it.

nwesthoff, 2018-04-26:
Reran the entire process of fetching and building magenta, that fixed it. I think that installed `nsynth_save_embeddings` as a general command.

Closed 2018-04-26.

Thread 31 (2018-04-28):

Jack 3,5mm doesn't fit into the PCB

minijouin, 2018-04-28:
My PCB (ordered on Tindle) doesn't have the right holes (not like on the picture) to put the 3,5mm audio jack !

Does anyone had the same problem ?

Thanks !

minijouin, 2018-04-30:
Are you sure ? Cause it's seems to be exactly the same ...

minijouin, 2018-04-30:
This is the good one to use !
http://www.conrad.fr/ce/fr/product/705866/Jack-35-mm-Embase-femelle-horizontale-Cliff-FC68133-Nombre-total-de-poles-4-stereo-noir-1-pcs/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

jditte, 2018-04-30:
The one in Squaro Engineering's DigiKey shopping cart is made by CUI and has pins that are symmetric with respect to the center of the audio plug. These pins do not fit the published PCB. The one in the original BOM is made by Lumberg and has asymmetric pins.

jditte, 2018-04-30:
I decided to order the Lumberg part instead. DigiKey didn't have it, but other suppliers (Newark, for example) do...

nafem, 2018-05-03:
As mentioned above, the Cliff FC68133 fits my PCB not the Lumberg part.
[http://uk.farnell.com/cliff-electronic-components/fc68133/stereo-jack-3-5mm-5pos-pcb/dp/2518190](http://uk.farnell.com/cliff-electronic-components/fc68133/stereo-jack-3-5mm-5pos-pcb/dp/2518190)

jditte, 2018-05-03:
The semi-assembled PCB that is offered by Squaro Engineering on Tindie? Then there must be multiple versions. It certainly didn't fit mine...

tekfunk, 2018-05-07:
Yea this Audio jack is hard to find in the US, I found it here:

http://www.newark.com/lumberg/klbr-4/phone-audio-connector-socket-3/dp/97K2709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

@jditte I also got the semi-assembled PCB for Squaro and this fits.

It fits, BUT I still cannot get sound.  getting this error:

Playback open error: -16, Device or resource busy

kaosbeat, 2018-11-24:
yes there seems to be some discussion on the audio jack. I just received my PCB from Squaro (ordered from Tindie) and tyhe one I got from the supplied BOM does not fit at all.

I got this one (DOES NOT FIT)
https://be.farnell.com/pro-signal/mj-352w-0/connector-receptacle-3-5mm-phono/dp/1267400?CMP=i-bf9f-00001000

holes look different on my PCB then they do on the PCB assembly manual website though...

jditte, 2018-11-24:
@kaosbeat As mentioned before, this is the one that worked on my PCB from Squaro (ordered from Tindie):

https://be.farnell.com/lumberg/klbr-4/receptacle-3-5mm-phono-tht-r-a/dp/1217016

but I don't know whether they have redesigned the PCB in the meanwhile...

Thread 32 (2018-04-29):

Lots of missed MIDI notes

jditte, 2018-04-29:
My Open NSynth Super plays only a fraction of the notes that I play on my MIDI keyboard. Most of them are missed and do not result in any sound. Does anybody else have the same issue? Any ideas what the problem could be?
Also, selecting some of the sounds like, for example, "El. Tom", "Snare", or "Vox. Hit" does not result in any audible sound whatsoever. Any clues?

nsynthsuper, 2018-04-30:
Try adjusting the attack and position controls – for shorter notes like the ones you mentioned, it's possible to set the start position of the note _after_ the initial attack, resulting in quiet or inaudible notes.

jditte, 2018-05-07:
Thank you! Adjusting the Position setting fixes the problem of not being able to hear anything when selecting "El. Tom", "Snare", or "Vox. Hit". (I had made the wrong assumption that having the potentiometer centered would be a "neutral" setting.)
What persists is the problem of many MIDI notes not being played (unless a relatively long time has passed since the last note has been triggered). Is this supposed to be a playable synth in the sense that you can play actual musical lines with it? Even a monophonic synth has to have the ability to re-trigger notes (start a new note even if the envelope of the previous one hasn't been full played yet). Is the Open NSynth Super supposed to have this capability?
So, similar to what mgiuli has posted as a separate issue, it would be helpful to be able to do some debugging whether the MIDI receiving side is the limiting factor or whether the problem is on the audio playback side. I will look into it, but if Open NSynth Super already has some built-in debugging capabilities it would be helpful to know.

haigarmen, 2018-05-08:
I've run into the same problem as jditte, midi notes not triggering until a long amount of time has past. Shortening the decay doesn't seem to make a difference. Any suggestions?

t-asano, 2018-05-08:
I made the following changes. Are they effective?
```cpp
--- MidiThread.cpp.org
+++ MidiThread.cpp
@@ -117,7 +117,11 @@

 			if((header & 0x0f) == channel){
 				synthMutex.lock();
-				synth.on(note, static_cast<float>(velocity) / 127.0f);
+				if (velocity == 0) { // support zero velocity note on
+					synth.off(note);
+				} else {
+					synth.on(note, static_cast<float>(velocity) / 127.0f);
+				}
 				synthMutex.unlock();
 			}
```

nsynthsuper, 2018-05-14:
You should be able to send MIDI notes in sequences or manually from any DAW, keyboard, or sequencer; the device should support polyphony and fast sequences of notes without issue. It may be worth checking with an alternative device to what you are using currently to test that your machine is sending MIDI correctly (i.e. sending noteoff signals).

haigarmen, 2018-05-15:
I'm going to try a different MIDI controller and see what happens. The one I used works just fine on other gear.

elimuro, 2018-05-15:
@haigarmen if you have a usb to midi you could probably try writing some midi in ableton and sending it directly to the nsynth

nsynthsuper, 2018-05-17:
@jditte The image you mentioned is well tested with fast sequences, polyphony etc… using the RPi 3B. Good luck with your testing!

haigarmen, 2018-05-18:
I've now tried a couple of midi sources and they all seem to result in the NSynth dropping notes and no polyphony. Feels like a software problem but could it be the hardware?

jditte, 2018-05-18:
@haigarmen I was wondering the same thing. Did you also order the NSynth Super Semi-Assembled from Squaro Engineering on tindie?

elimuro, 2018-05-18:
@haigarmen I noticed that the IC (in the midi area) that you had on your board looked different from mine which I ordered from the parts list. could be just that it looks different but I have noticed other differences as well such as the audio jack so its worth looking into

jditte, 2018-05-18:
@elimuro I will certainly have a closer look at the components on the board...

haigarmen, 2018-05-27:
I soldering a new 6N139 Optocoupler onto the board after reading a suggestion from closed issue no 34 https://github.com/googlecreativelab/open-nsynth-super/issues/34 but it didn't make any difference. Still getting intermittent midi notes and no polyphony. I'd like to find a test script that will help me assess whether I'm receiving all the MIDI info correctly. Anyone have a suggestion?

nanu-c, 2018-05-27:
You can add some logging in this file: https://github.com/googlecreativelab/open-nsynth-super/blob/d16f49de2ac428065125232f42aaef6b89a33e09/app/open-nsynth/src/MidiThread.cpp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

like that

```
ofLog(OF_LOG_NOTICE,"note: " + ofToString(note));
```
and after https://github.com/googlecreativelab/open-nsynth-super/blob/d16f49de2ac428065125232f42aaef6b89a33e09/app/open-nsynth/src/MidiThread.cpp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
you could add

```
ofLog(OF_LOG_NOTICE,"velocity: " + ofToString(velocity));
```
Giving the note from the midi to the sound producing algorithm is happening here:
https://github.com/googlecreativelab/open-nsynth-super/blob/d16f49de2ac428065125232f42aaef6b89a33e09/app/open-nsynth/src/MidiThread.cpp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

And finally you could add usbmidi functionality like done here: https://github.com/googlecreativelab/open-nsynth-super/issues/29

WellDrestGhost, 2018-05-30:
@jditte I am also having the same issue as haigarmen, I have tried 3 midi controllers

KORG Microkorg midi out- I am able to get single notes and arpeggios via the arpeggiator button.  No polyphony.

Roland A-300 Pro- single notes work. No polyphony

M-Audio Oxygen 8 v2- the same as @haigarmen- some single notes, long delays needed between each note press and some missed notes. No polyphony.

I haven’t been able to get polyphony out of any of the controllers I tried. The Roland midi controller seems to work best, but it still seems to lose notes. I am completely new to coding, but willing to learn/try.  I used the 16gb lite disk image provided on this site.
If your file fixes these issues, I would be happy to try to implement it, however if you could give me a few more details or send me in the right direction, I would be grateful!

jditte, 2018-05-31:
Sure, would be happy to. To replace the file and recompile the application you will need access to the Raspberry Pi. Hook it up to an HDMI monitor and a USB keyboard and boot it. Initially, you will see a copy of the Open NSynth Super screen. Hitting the ESC key will get you to a login prompt. Use the username "pi" (without quotes) and the password "raspberry" to log in. As the SD card is mounted as read only by default, you will need write access by remounting it: "sudo mount -u remount,rw /". Now you have two options:
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
jditte, 2018-05-31:
Sorry to hear! This is pretty strange. So, you still had a monitor attached when testing it? I don't see why it should hurt, but I have never tested running the NSynth Super with a monitor attached. You might want to give it a try without. Also, did you reboot before testing it? You certainly wouldn't want to have multiple instances of the app running. Also, I have only done limited testing so far, but everything seemed fine. It certainly didn't crash on me when bombarding it pretty heavily with sequences of short notes and multiple notes in prallel for a minute or so, but let me do some more testing to make sure that it is stable... Do you get sound when having all controls in the same setting and using the original MidiThread.cpp? Did you try to reboot when the crash happened and did the same thing happen again right away?

haigarmen, 2018-05-31:
@jditte It has been strange, I can't seem to even get back to a compiled version with original MidiThread.cpp. I've copied the original back into /home/pi/opt/of/apps/open-nsynth/open-nsynth/src/MidiThread.cpp but it behaved the same way as with your MidiThread.cpp file. Then I deleted all the src files and recompiled and same deal. And I've been restarting between compiles. So close but yet so far....

haigarmen, 2018-06-01:
I'll try to be clearer about what I mean. I downloaded the original src files from this repo before recompiling and I did use the touch command. What are the object files?

nanu-c, 2018-06-01:
if you replace any code you have to go to this folder
` /home/pi/opt/of/apps/open-nsynth/open-nsynth/` and run `make -j4`
then
`sudo service open-nsynth stop `
and
`bin/open-nsynth`
If you get some errors while compiling or while running `bin/open-nsynth` you can paste them here and we can help you.

jditte, 2018-06-04:
@haigarmen The object files are what the compiler creates from the source files. (You can find them in the obj directory; save level as the src directory.) These object files then get linked together to create the application.
I have now been able to do some more testing. The NSynth works perfectly fine for me for minutes. It certainly doesn't crash. The only strange observation is that, after minutes of playing, the volume gradually decreases until I can't hear anything anymore, but this doesn't seem to be a MIDI-related problem. I yet have to figure out what is going on.
@haigarmen If you are able to record the MIDI stream that causes the crash in your case please feel free to send it my way. I would be happy to give it a try and, in case it should crash my device, too, do some debugging what is going on...

jditte, 2018-08-24:
No, this is a pure software issue, not at all hardware-related. The way the MIDI parser was implemented was not fully compliant with the MIDI specifications. Whether or not you experience problems with the original software depends on what equipment you use to send MIDI information to the NSynth. Problems occur if either
a) the MIDI stream contains real time messages, or
b) the equipment sends Note On messages with zero velocity instead of Note Off messages, or
c) the equipment takes advantage of "running status".

joegiralt, 2018-10-24:
is the Nsynth MPE compatible?

Fluqz, 2019-06-23:
Hey, im having the same problems here. Bought on Tindie and midi notes are only played in weird intervals. Im trying to replace the MidiThread.cpp file from a USB stick, but its always saying 'read-only'.
I mounted the sda1 as pointed [here](https://www.raspberrypi-spy.co.uk/2014/05/how-to-mount-a-usb-flash-disk-on-the-raspberry-pi/). I try to copy the file after point 4. of the Tutorial with
`sudo cp /media/usb/MidiThread.cpp /home/pi/opt/of/apps/open-nsynth/open-nsynth/src/MidiThread.cpp`
How do I get write access?

jditte, 2019-06-24:
@Fluqz Did you remount the filesystem ("sudo mount -u remount,rw /") as explained in my post from May 30th, 2018 above?

Fluqz, 2019-06-25:
Hey, after booting and logging in Im trying `sudo mount -u remount, rw /` but it says:

`mount: invalid option -- 'u'`

I think last time I did it with `-o`. Is that correct?

Fluqz, 2019-06-25:
Hey, I tried `sudo mount -u remount,rw /` but it says invalid option `-u`. But it is working with -o. And I was able to copy the MidiThread.cpp file, but when i do `make -j4` I get some errors at the end.
```
recipe for target 'obj/linuxarmv61/Realease/src/main.o' failed
recipe for target 'Realease' failed
```

Fluqz, 2020-04-04:
Hey, im still having this problem. Im giving it another try to solve this issue. @jditte would you help with this? Maybe via pm. Is there anything new maybe?

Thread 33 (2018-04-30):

Potentiometers instead of rotary encoders ?

minijouin, 2018-04-30:
Hi !

I'm wondering if it could be possible to put some potentiometers instead of the 4 rotary encoders in the corners (the good reference is impossible to find on the internet and I had the one with 2 more arms -or could I cut them ?- )

Thanks !

fakemau5, 2018-05-05:
If you mean you got the "S0012" variant of the encoders, you're good to go. They have a "push button" feature, so they have the two more arms that are going to be short-circuited when you press the button, but given the "button" feature of the encoders is not used you can safely cut or bend them to fit on the board, and they will perform fine!

minijouin, 2018-05-05:
Ok thank you so much !

Closed 2018-05-14.

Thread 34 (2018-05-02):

Midi input troubleshooting

mgiuli, 2018-05-02:
I'm desperate for some help.  I completed build a few days ago and have been unable to resolve the issue on my own.  I cannot get any sounds to be made with my synth.  I ran a sound test through a command and was able to hear noise out of the headphone jack.  That leads me to believe that no Midi signal is reaching the device.  I tried using the 64 and 16 GB preconfigured images.  With both, everything else appears to function just by plugging the imaged card into my system.  The screen functions and shows an expected response when each dial is turned.  On the Midi connection, I have tried plugging in a keyboard with 5 pin end on each side (no USB involved) and also tried playing some notes out of a couple of DAWs installed on my PC and connecting with a USB to Midi cable.  Are there any diagnostics that I can run to see if a signal is even being received?  Is there something additional I needed to do in first setup of the software?  Perhaps something else basic that I missed?  I don't have much knowledge in this area, so I won't be offended by any suggestions.  Thanks in advance!

Wolfberti, 2018-05-09:
I have the same problem. All the Inputs are working fine, but I don't get any sounds. I double checked the Soldering for Bridges and measured for wrong Voltages, but couldn't find an error. Are there preexisting scripts to test the MIDI input? Has anybody resources how to write a python script on your own?

Wolfberti, 2018-05-10:
Now it gets a little weird. I connected the pi with a keyboard, a hdmi Display and headphones. Now i can Play with the keys from q to p. At least I now know that the dac works.

mgiuli, 2018-05-12:
I've given up for the most part.  It may be time to conclude that my board is damaged and I need to find a new one.  I did run the dmesg command in console and reviewed the log.  This line is the only one that jumps out at me:

 **2.188288] systemd[1]: [/etc/systemd/system/open-nsynth.service:3] Failed to add dependency on alsa.restore, ignoring: Invalid argument**

Can someone please confirm if that's normal or not?

Wolfberti, 2018-05-12:
You could try to build the OS from Scratch. I'm currently downloading the 16gb version, if this will fail i will try Building from scratch.

nsynthsuper, 2018-05-14:
Hi mgiuli & wolfberti – the preconfigured image will have the baud rate set correctly; this does indeed sound more like an issue with the MIDI part of your hardware build. The easiest way to test the MIDI is to send notes to all channels which you should be able to do via your DAW.

mgiuli, 2018-05-19:
I'm glad that worked for you.  I knew it was a long shot for me, but I tried it anyways without success.  Thanks again!

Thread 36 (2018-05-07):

Playback open error

tekfunk, 2018-05-07:
I am so close to getting this working. Even though my display wont power on, I can use the HDMI port on the pi to check everything out.  Nsynth is running, and all the knobs + touchpad work.  When I run the speaker-test, however, I get an error:

Playback open error: -16, Device or resource busy

Any ideas on what could be causing this?

Thanks

Wolfberti, 2018-05-10:
May I ask you what kind of speaker-test you run?

sqfmi, 2018-05-10:
try stopping the open-nsynth service before running speaker-test

nsynthsuper, 2018-05-17:
As mentioned by @sqfmi – the open-nsynth application will hold the audio card and prevent speaker-test from running.

Closed 2018-05-17.

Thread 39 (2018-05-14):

make it work with raspberry pi 3 b+ and latest openframework

nanu-c, 2018-05-14:
# Set up the rpi 3 b+
* get latest raspbian as described on https://www.raspberrypi.org/downloads/raspbian/

* Do the things in section 3 and 4 from https://github.com/googlecreativelab/open-nsynth-super/tree/master/linux#3-prepare-the-os
# get nsyth from git
```
$ wget https://codeload.github.com/googlecreativelab/open-nsynth-super/zip/master
$ unzip master && rm master
```

# Set up the firmeware
* follow the guide from here https://github.com/googlecreativelab/open-nsynth-super/tree/master/firmware#installation-guide ->  get  `en.stm32cubef0.zip`  from http://www.st.com/en/embedded-software/stm32cubef0.html and put in /home/pi/open-nsynth-super-master/firmware/
```
$ cd /home/pi/open-nsynth-super-master/firmware/
$ unzip en.stm32cubef0.zip
```
* get the depencies
`$ cd /home/pi/open-nsynth-super-master/firmware/utils && sudo ./install_dependencies.sh`
-> this takes a while

* don't do this `$ mv STM32Cube_FW_F0_V1.9.0 cube` it gives then the error
`make: *** No rule to make target '../STM32Cube_FW_F0_*/Drivers/CMSIS/Device/ST/STM32F0xx/Source/Templates/gcc/startup_stm32f030xc.s', needed by '../bin/main.elf'.  Stop.`

* flash chip
`$ make install`
```
sudo /home/pi/open-nsynth-super/firmware/openocd/bin/openocd --file openocd.cfg --command "program ../bin/main.elf verify reset exit"
Open On-Chip Debugger 0.10.0 (2018-05-14-21:26)
Licensed under GNU GPL v2
For bug reports, read
	http://openocd.org/doc/doxygen/bugs.html
BCM2835 GPIO nums: swclk = 25, swdio = 24
BCM2835 GPIO config: srst = 23
srst_only separate srst_gates_jtag srst_push_pull connect_deassert_srst
adapter speed: 1000 kHz
adapter_nsrst_delay: 100
srst_only separate srst_nogate srst_push_pull connect_deassert_srst
cortex_m reset_config sysresetreq
srst_only separate srst_nogate srst_push_pull connect_deassert_srst
adapter_nsrst_delay: 100
adapter_nsrst_assert_width: 100
Info : BCM2835 GPIO JTAG/SWD bitbang driver
Info : SWD only mode enabled (specify tck, tms, tdi and tdo gpios to add JTAG mode)
Info : clock speed 1001 kHz
Info : SWD DPIDR 0x0bb11477
Info : stm32f0x.cpu: hardware has 4 breakpoints, 2 watchpoints
Error: stm32f0x.cpu -- clearing lockup after double fault
Polling target stm32f0x.cpu failed, trying to reexamine
Info : stm32f0x.cpu: hardware has 4 breakpoints, 2 watchpoints
    TargetName         Type       Endian TapName            State
--  ------------------ ---------- ------ ------------------ ------------
 0* stm32f0x.cpu       cortex_m   little stm32f0x.cpu       halted
adapter speed: 1001 kHz
target halted due to debug-request, current mode: Thread
xPSR: 0xc1000000 pc: 0xfffffffe msp: 0xfffffffc
adapter speed: 1001 kHz
target halted due to debug-request, current mode: Thread
xPSR: 0xc1000000 pc: 0xfffffffe msp: 0xfffffffc
adapter speed: 4061 kHz
** Programming Started **
auto erase enabled
Info : device id = 0x10006444
Info : flash size = 32kbytes
wrote 12288 bytes from file ../bin/main.elf in 0.614188s (19.538 KiB/s)
** Programming Finished **
** Verify Started **
verified 11788 bytes in 0.050718s (226.975 KiB/s)
** Verified OK **
** Resetting Target **
adapter speed: 1001 kHz
shutdown command invoked
```
# copy audio files
* https://github.com/googlecreativelab/open-nsynth-super/tree/master/linux#4-copy-audio-files
# Set up latest openframework from git

* get latest openframeworks from git
`$ cd ~ && mkdir opt/ && cd opt/ && git pull --depth=1 https://github.com/openframeworks/openFrameworks.git`
* rename the openframeworks folder to be compatible with manual
`$ mv openframeworks of`
*  get openframeworks dependencies
`$ cd of/scripts/linux/debian && sudo ./install_dependencies.sh`
* get libs for openframeworks
`$ cd ~/opt/of/scripts/linux &&  download_libs.sh `
* copy the files from https://github.com/googlecreativelab/open-nsynth-super/tree/master/app/open-nsynth to `$ mkdir  /home/pi/opt/of/apps/open-nsynth && cp -r /home/pi/open-nsynth-super-master/app/open-nsynth /home/pi/opt/of/apps/open-nsynth/`
* replace in the code `Poco::FastMutex` with `std::mutex` -> this is in various files
* build the app in `~/opt/of/apps/open-nsynth/open-nsynth` with
`$ make -j4` -> this takes a while
* get the settings.json in the right place `https://github.com/googlecreativelab/open-nsynth-super/tree/master/linux#4-copy-audio-files`
* test if it's running with
`$ bin/open-nsynth`
# get nsynth dependencies
`$ cd ~/open-nsynth-super-master/linux`
* edit ./nsynth-setup.sh and edit the section replace every `gstreamer0.10` with `gstreamer1.0`
```
install_deps() {
    apt-get update
    apt-get install -y i2c-tools python-smbus gdb-arm-none-eabi gcc-arm-none-eabi \
        git autoconf libtool make pkg-config build-essential \
        libcairo-dev gstreamer1.0-dev gstreamer1.0-x \
        gstreamer1.0-plugins-base-apps gstreamer1.0-alsa \
        libudev-dev libsndfile-dev libopenal-dev libssl-dev \
        gstreamer1.0-plugins-good gstreamer1.0-plugins-bad \
        gstreamer-plugins-base0.10-dev freeglut3-dev libasound2-dev \
        libxmu-dev libxxf86vm-dev libgl1-mesa-dev libglu1-mesa-dev \
        libraw1394-dev libudev-dev libdrm-dev libglew-dev libopenal-dev \
        libsndfile-dev libfreeimage-dev libcairo2-dev libfreetype6-dev \
        libssl-dev libpulse-dev libusb-1.0-0-dev libopencv-dev \
        libegl1-mesa-dev libgles1-mesa-dev libgles2-mesa-dev libassimp-dev \
        librtaudio-dev libboost-filesystem-dev
}
```
* remove the follow section:
```
setup_openframeworks() {
    if ! [ -e /home/pi/opt/of ]
    then
        echo "Fetching openFrameworks"
        mkdir -p /home/pi/opt
        (
            cd /home/pi/opt
            curl http://openframeworks.cc/versions/v0.9.8/of_v0.9.8_linuxarmv6l_release.tar.gz | tar -xzf -
            mv of_v0.9.8_linuxarmv6l_release of
            #sudo of/scripts/linux/debian/install_dependencies.sh
        )
    fi
}
```
* run it `$ sudo sh ./nsynth-setup.sh`
* reboot `$ sudo reboot`

nanu-c, 2018-05-14:
and it works ;)

nsynthsuper, 2018-05-17:
Thanks so much nanu-c – will leave this issue open for others to reference.

ellasayers, 2018-12-15:
@nsynthsuper @nanu-c  is it possible to make an image for this, I've been hitting a lotttt of snags bouncing between these two instruction sets and cannot always find the correct packages referenced. Please and thanks!

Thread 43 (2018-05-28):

Midi real-time bytes cause the app's midi thread to shut down

damian0815, 2018-05-28:
The Midi thread currently misinterprets "system real-time" messages (which may be inserted into the midi byte stream at any point) as malformed data and exits. This makes nsynth unusable in a production environment where midi clock messages are used to keep devices in sync.

ref: http://www.lim.di.unimi.it/IEEE/MIDI/SOT3.HTM "Real Time messages can be sent at any time and may be inserted anywhere in a MIDI data stream, including between Status and Data bytes of any other MIDI messages."

nanu-c, 2018-05-28:
Let's have a look at this updated file:
https://github.com/nanu-c/open-nsynth-super/blob/master/app/open-nsynth/src/MidiThread.cpp

damian0815, 2018-05-28:
@nanu-c huh. I guess that's another way to achieve the same thing. I prefer mine TBH :)

jditte, 2018-06-05:
My solution in the thread "Lots of missed MIDI notes" fixes this problem, too (in addition to interpreting Note On with zero velocity correctly and being able to handle running status).

Closed 2018-07-30.

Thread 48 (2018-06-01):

Help...

unrealone1, 2018-06-01:
Hi experts,
OK built my unit,,,,

I have loaded the SD card with the image , booted and get presented with this image of lots of colours but it goes no further , any advice please

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

haigarmen, 2018-06-01:
Looks like your RaspberryPi doesn't have enough power. Try using a power adapter with 5 volts at 2.5 amps. https://www.raspberrypi.org/documentation/hardware/raspberrypi/power/README.md

unrealone1, 2018-06-01:
Hi Haig,
I currently am running the power /psu  through the nsync board only,  do I need a secondary power adapter for the raspberry as well
Thanks

YANN DAVIES
ABCOM IT Solutions
Unit 3 Ashwyn Business Centre
Marchants Way
Burgess Hill
West Sussex
RH15 8QY
+44 1444 871 200
www.abcom.co.uk
PROUDLY PROVIDING IT SERVICES FOR OVER 20 YEARS
On 1 Jun 2018, at 10:41 pm, Haig Armen <notifications@github.com<mailto:notifications@github.com>> wrote:

Looks like your RaspberryPi doesn't have enough power. Try using a power adapter with 5 volts at 2.5 amps. https://www.raspberrypi.org/documentation/hardware/raspberrypi/power/README.md

—
You are receiving this because you authored the thread.
Reply to this email directly, view it on GitHub<https://github.com/googlecreativelab/open-nsynth-super/issues/48#issuecomment-394016559>, or mute the thread<https://github.com/notifications/unsubscribe-auth/Al_vqoQa8wqN7oYlEfAoDm645rqk8Cskks5t4bTrgaJpZM4UXTHB>.

unrealone1, 2018-06-02:
Hi ...I still have the same image even when suitable power supply on the raspbery pi and the nysnc board.

themangoest, 2018-06-02:
This is a b d rpi install

unrealone1, 2018-06-02:
So I just need to reinstall the image onto the Pi? I am downloading the 64Gb version on a 128GB card , hopefully that should sort it. By the way When I install the image should it completely wipe the Pi O/S..
Is there any tutorials out there?

unrealone1, 2018-06-03:
Hi all,
I am running a power supply to both the raspberry pi and the synth board, I have installed onto the sd card the larger 64Gb image.
I am still getting the rainbow image (with lightning strike)
Is the fact that Ive formatted completly the sd card the issue here ?
Do I need o/s on the card or a bootable partition?
Thanks

ErikOostveen, 2018-06-09:
Hi - I'd try loading the 16G image and see if that boots fine. I am having kernel panic errors with the 64G image, however, the 16G image runs just fine. I am using a RPI 3 Model B V1.2

damian0815, 2018-06-18:
@unrealone1 do you have a rpi 3 b or a 3 b+? The b+ didn’t work for me (same issue) but the b did.

ErikOostveen, 2018-06-20:
The exact wording on the PI's PCB is as follows "Raspberry Pi 3 Model B V1.2" ... so "B", not "B+". I have given up on the 64G image and stick to the 16G. It's now time to process my own sounds :-)

unrealone1, 2018-06-20:
Hi Erik, thanks for coming back to me. I am just about to buy the correct version PI and Ill update you once I have it...Thanks

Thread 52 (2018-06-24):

Encoder pins don't match

biggytruck, 2018-06-24:
Since I can't find PEC11R-4315F-N0012-ND, I use PEC11R-4315F-S0012-ND as encoders(also works according to the instruction). However, the encoders have 5 pins with 3 on one side and 2 on the other, while there are only 3 cutouts on the board. I looked at the PCB image and found that the demo board has 3 pins as well. How do I deal with this? Can I just cut off the extra 2 pins of the encoders?

tako3, 2018-06-29:
I'm having the same problem😱

NullMember, 2018-06-30:
You can use it. PEC11R-4315F-S0012-ND have built-in switch which PEC11R-4315F-N0012-ND don't have. Extra 2 pins are switch pins.

biggytruck, 2018-07-01:
@NullMember So can I trim the extra 2 pins off?

NullMember, 2018-07-01:
@biggytruck yes you can :)

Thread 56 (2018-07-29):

What does position do?

notthetup, 2018-07-29:
More a question than an issue. I'm looking through the code trying to understand how the Multisampler works.

What does the parameter `position` (in some parts referred to as  `offset` when multiplied with `ncols`) do? I can deduce it can be changed by the first potentiometer, but still can't wrap my head around how it changes the synth.

nsynthsuper, 2018-08-06:
It sets the start position of the waveform output by the device

Closed 2018-08-06.

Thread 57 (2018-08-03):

Gracefully shutdown the nsynth raspberry

fakemau5, 2018-08-03:
Once the device is up&running as a standalone synth, is there any way or guideline to gracefully invoke the raspberry shutdown from the hardware user interface?

nsynthsuper, 2018-08-06:
If you're running from the provided images then the OS runs in RO mode to protect the contents of the disk.

However you if you created a UX for this (for example, if the volume control is set to zero) you could add the functionality to the application itself. By default, it isn't needed.

Closed 2018-08-06.

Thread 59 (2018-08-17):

Chinese OLED display instead of adafruit?

zacYP2, 2018-08-17:
I noticed in the hardware folder that display communicates via i2c, does that mean we could actually use a generic i2c OLED instead of the 20$ adafruit one? As long as we solder the 4 pins in the right place it should work, right?

notthetup, 2018-08-22:
Yes. I have tried this and it works. The pinout is all over the place so you'll need some jumpers.

zacYP2, 2018-09-19:
I have recieved my OLED, it is this model:

https://www.aliexpress.com/item/TZT-1-3-OLED-module-white-color-128X64-1-3-inch-OLED-LCD-LED-Display-Module/32777866923.html

As you said, pinout is different, I managed to plug DATA, CLOCK, VCC and GND in their respective places, but it still doesn't work. Maybe this is because I'm lacking the RESET pin?

I also have a Nokia 5110 I though I could use, which has a reset pin, but it didn't work, only random lines. Maybe because I need to connect the jumper on the back to switch to I2C instead of default SPI?

notthetup, 2018-09-25:
I believe there is a way to reset it using an SPI command. The driver actually uses that. So it should be OK. Check your connection again and maybe you can try to drive the display with an Arduino or something to make sure it works.

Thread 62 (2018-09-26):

Unable to connect to STM32

alexdgourlay, 2018-09-26:
Ok, I am really confused. I had everything working (OLED, audio, touch, encoders) and then everything stopped. Now I’m back to trying to connect to the micro controller and am stuck at this error. Help!

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

alexdgourlay, 2018-09-26:
Have checked functionality of all rpi GPIO pins and continuity of rpi header.
I have checked the voltage at supply pins of the STM32 and get a reading of 5V, is this correct?

cnuty, 2018-11-23:
Hi,
I have exactly the same problem and report with the STM32. I posted yesterday about it (post #67). Waiting for comments...
Cnuty

kaosbeat, 2018-11-26:
@alexdgourlay are you saying, you had a fully working box and it then stopped working?
on mine the display works, but there is no sound, and no working encoders (I can select instruments with the keyboard though)
problem indeed related (same error on screen) as #67
I also measure 5V across C7, it should be 3.3V I read
did you get your board from tindie?

alexdgourlay, 2018-11-26:
Yep, had everything working. Then came back to the board and had a blank OLED screen. Tried re-running the make file which failed.

Weirdly I managed to run the make file successfully once more, after adjusting the position of the RPi but then stopped working again.

Board was bought from tindie yes.

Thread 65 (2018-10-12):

No power from PCB

didierbergeron, 2018-10-12:
Hello all,

When connecting my power supply to the PCB, nothing happens.
However, when i connect it directly to the raspberry pi, everything is fine and I can use the instrument.

Could it be because I didn't solder the lcd screen yet?
Any advice?

Thank you

amrmarzouk, 2019-09-16:
Most probably was the USB connector soldering.

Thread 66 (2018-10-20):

no reaction to encoders, pots, touch panel and midi signal

RoaX2, 2018-10-20:
Hi all,

I finished a semiassambled nsynth, but it doesn't work.

RPI is booting correctly, the display shows the grid (also a monitor when connected), but there's no respond to encoders, pots and touch panel. There's also no respond to midi signals and there's no sound.
Does somebody has any idea?
Thank you,
RoaX

kaosbeat, 2018-11-24:
did you flash the firmware to the STM32?

RoaX2, 2018-11-24:
No. I thought that I do not have to do anything like this if I use a semi-assambled board with a precompiled image (in this case the light image) and it should be out of the box. Am I wrong with that?
Thank you for your answer.

kaosbeat, 2018-11-24:
I assume you still have to flash the board, I just got mine semi-assembled, but no luck so far. Flashing does not even work

follow these steps
[https://github.com/googlecreativelab/open-nsynth-super#4-install-the-firmware](url)

RoaX2, 2018-11-25:
OK, thanks so far. I'll have a try next days.

troglodisme, 2018-12-14:
Hi @kaosbeat @RoaX2 good to see somebody is having the same issues.

I have assembled my own boards and pretty sure they are 100% correct, but I am failing to install the firwmare! As soon as I power the board I can see the pi is quickly booting up for a few seconds (it doens't asked me to login like detailed in the guide here), then it starts showing the grid on the little display and also on my monitor, but nothing else happens. No sound, no potentiometers.. nothing.

I think I might have to go back and install the firmware? Do you know how I can load the terminal from that stage?

Thanks!

kaosbeat, 2018-12-14:
Hey, measure the voltage on de voltage regulators it should be 3.3v if not you have faulty regulators. A batch was produced having this issue and it will have the symptoms you describe.

troglodisme, 2018-12-15:
Hey thanks @kaosbeat. I read your posts on that issue, but I doubt it would be the same problem because I didn't buy the PCBs from tindie.

I have measured U4, U5, U6 and I can see 3.3 on the top left pin and 1.15 on the top right pin, using the bottom middle pin a GND reference. Could you confirm that is the correct reading?

I have also posted [here](https://github.com/googlecreativelab/open-nsynth-super/issues/68) to see if I could go back to the terminal and try to reinstall the firmware? Would you be able to help on that? Total newbie here!

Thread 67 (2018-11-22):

make install problem

cnuty, 2018-11-22:
Hello,
I read all the preview posts about a "make install" problem. I reflowed the Pi interface connector and all the STM32 connections. Same error with the lite version. The message is the following:
....
_BCM2835 GPIO nums: swclk = 25, swdio = 24
BCM2835 GPIO config: srst = 23
srst_only separate srst_gates_jtag srst_push_pull connect_deassert_srst
srst_only separate srst_nogate srst_push_pull connect_deassert_srst
adapter_nsrst_delay: 100
adapter_nsrst_assert_width: 100
Info: BCM2835 GPIO JTAG/SWD bitbang driver
Info: SWD only mode enabled (specify tck, tms, tdi and tdo gpios to add JTAG mode)
Info: clock speed 1001 kHz
in procedure 'init' called at file "openocd.cfg", line 20
in procedure 'ocd_bouncer'

Makefile:40: recipe for target 'install' failed
make: *** [install] Error 1

Please, do you have an idea how I can fix it?
Thanks a lot,
Cnuty

ajmonkey, 2018-11-24:
I'm having the same probem too! I've tried to rebuild from scratch--by downloading the nsyth-super-master here's my error-log:
pi@raspberrypi:~/open-nsynth-super-master/firmware/src $ sudo mount -o remount,rw /
pi@raspberrypi:~/open-nsynth-super-master/firmware/src $ make install
sudo openocd --file openocd.cfg --command "program ../bin/main.elf verify reset exit"
Open On-Chip Debugger 0.10.0 (2018-03-07-13:33)
Licensed under GNU GPL v2
For bug reports, read
	http://openocd.org/doc/doxygen/bugs.html
BCM2835 GPIO nums: swclk = 25, swdio = 24
BCM2835 GPIO config: srst = 23
srst_only separate srst_gates_jtag srst_push_pull connect_deassert_srst
adapter speed: 1000 kHz
adapter_nsrst_delay: 100
srst_only separate srst_nogate srst_push_pull connect_deassert_srst
cortex_m reset_config sysresetreq
srst_only separate srst_nogate srst_push_pull connect_deassert_srst
adapter_nsrst_delay: 100
adapter_nsrst_assert_width: 100
Info : BCM2835 GPIO JTAG/SWD bitbang driver
Info : SWD only mode enabled (specify tck, tms, tdi and tdo gpios to add JTAG mode)
Info : clock speed 1001 kHz
in procedure 'init' called at file "openocd.cfg", line 20
in procedure 'ocd_bouncer'

Makefile:40: recipe for target 'install' failed
make: *** [install] Error 1

When I start up the raspi with nsyth board the power comes on--the oled displays the grid--if I move my mouse--the Grid on the monitor/Raspi software works---it moves the cursor position on the OLED--when I try moving/changing the cursor position on the trackpad--nothing happens--will check soldering---no idea why I can't build from Makefile--any trouble shooting steps or testing steps would be greatly appreciated-thanks!

kaosbeat, 2018-11-24:
same problem here,
tried building myself, and used the lite image as well...

is this a hardware bug?

kaosbeat, 2018-11-25:
I did some debugging.

My hardware seems to be fine, I verified the pin connections to the RPi and they are OK. If you need to verify check at least these connections (not testing the pots etc... just the programming interface)
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

The RPi itself seems to be ok as well

I started hacking the openocd.cfg in the `~/open-nsynth-super/firmware/src` folder, this changes behaviour, but no luck so far (just more bugs) I just want a simple test routine to verify the connection to the STM32, but I don't know how this works... anybody?

thanks

kaosbeat, 2018-11-26:
When cranking up the debugger using the `-d 3`flag passed on the openocd in the `Makefile` I get lot's of extra output. Still not making a lot of sense to me though.
I added the `transports` command to the `openocd.cfg` before the init, and there it works fine.
first thing that is off seems to be this:
`Debug: 311 26 bitbang.c:470 bitbang_swd_read_reg(): No valid acknowledge: ack=5``

full output below

```
:~/open-nsynth-super/firmware/src $ sudo make install
sudo /usr/bin/openocd -d 3 --file openocd.cfg --command "program ../bin/main.elf verify reset exit"
Open On-Chip Debugger 0.10.0 (2018-03-07-13:33)
Licensed under GNU GPL v2
For bug reports, read
	http://openocd.org/doc/doxygen/bugs.html
User : 13 5 command.c:544 command_print(): debug_level: 3
Debug: 14 5 options.c:181 add_default_dirs(): bindir=/usr/bin
Debug: 15 5 options.c:182 add_default_dirs(): pkgdatadir=/usr/share/openocd
Debug: 16 5 options.c:183 add_default_dirs(): exepath=/usr/bin
Debug: 17 5 options.c:184 add_default_dirs(): bin2data=../share/openocd
Debug: 18 5 configuration.c:42 add_script_search_dir(): adding /root/.openocd
Debug: 19 5 configuration.c:42 add_script_search_dir(): adding /usr/bin/../share/openocd/site
Debug: 20 5 configuration.c:42 add_script_search_dir(): adding /usr/bin/../share/openocd/scripts
Debug: 21 5 configuration.c:82 find_file(): found openocd.cfg
Debug: 22 5 command.c:143 script_debug(): command - ocd_command ocd_command type ocd_interface bcm2835gpio
Debug: 23 5 command.c:143 script_debug(): command - interface ocd_interface bcm2835gpio
Debug: 25 5 command.c:364 register_command_handler(): registering 'ocd_bcm2835gpio_jtag_nums'...
Debug: 26 5 command.c:323 command_new(): BUG: command 'bcm2835gpio_tck_num' does not have the '.usage' field filled out
Debug: 27 6 command.c:364 register_command_handler(): registering 'ocd_bcm2835gpio_tck_num'...
Debug: 28 6 command.c:323 command_new(): BUG: command 'bcm2835gpio_tms_num' does not have the '.usage' field filled out
Debug: 29 6 command.c:364 register_command_handler(): registering 'ocd_bcm2835gpio_tms_num'...
Debug: 30 6 command.c:323 command_new(): BUG: command 'bcm2835gpio_tdo_num' does not have the '.usage' field filled out
Debug: 31 6 command.c:364 register_command_handler(): registering 'ocd_bcm2835gpio_tdo_num'...
Debug: 32 6 command.c:323 command_new(): BUG: command 'bcm2835gpio_tdi_num' does not have the '.usage' field filled out
Debug: 33 6 command.c:364 register_command_handler(): registering 'ocd_bcm2835gpio_tdi_num'...
Debug: 34 6 command.c:364 register_command_handler(): registering 'ocd_bcm2835gpio_swd_nums'...
Debug: 35 6 command.c:323 command_new(): BUG: command 'bcm2835gpio_swclk_num' does not have the '.usage' field filled out
Debug: 36 6 command.c:364 register_command_handler(): registering 'ocd_bcm2835gpio_swclk_num'...
Debug: 37 6 command.c:323 command_new(): BUG: command 'bcm2835gpio_swdio_num' does not have the '.usage' field filled out
Debug: 38 6 command.c:364 register_command_handler(): registering 'ocd_bcm2835gpio_swdio_num'...
Debug: 39 6 command.c:323 command_new(): BUG: command 'bcm2835gpio_srst_num' does not have the '.usage' field filled out
Debug: 40 6 command.c:364 register_command_handler(): registering 'ocd_bcm2835gpio_srst_num'...
Debug: 41 6 command.c:323 command_new(): BUG: command 'bcm2835gpio_trst_num' does not have the '.usage' field filled out
Debug: 42 6 command.c:364 register_command_handler(): registering 'ocd_bcm2835gpio_trst_num'...
Debug: 43 6 command.c:323 command_new(): BUG: command 'bcm2835gpio_speed_coeffs' does not have the '.usage' field filled out
Debug: 44 6 command.c:364 register_command_handler(): registering 'ocd_bcm2835gpio_speed_coeffs'...
Debug: 45 6 command.c:323 command_new(): BUG: command 'bcm2835gpio_peripheral_base' does not have the '.usage' field filled out
Debug: 46 7 command.c:364 register_command_handler(): registering 'ocd_bcm2835gpio_peripheral_base'...
Debug: 47 7 command.c:143 script_debug(): command - ocd_command ocd_command type ocd_bcm2835gpio_peripheral_base 0x3F000000
Debug: 48 7 command.c:143 script_debug(): command - bcm2835gpio_peripheral_base ocd_bcm2835gpio_peripheral_base 0x3F000000
Debug: 50 7 command.c:143 script_debug(): command - ocd_command ocd_command type ocd_bcm2835gpio_speed_coeffs 146203 36
Debug: 51 7 command.c:143 script_debug(): command - bcm2835gpio_speed_coeffs ocd_bcm2835gpio_speed_coeffs 146203 36
Debug: 53 7 command.c:143 script_debug(): command - ocd_command ocd_command type ocd_bcm2835gpio_swd_nums 25 24
Debug: 54 7 command.c:143 script_debug(): command - bcm2835gpio_swd_nums ocd_bcm2835gpio_swd_nums 25 24
User : 56 7 command.c:544 command_print(): BCM2835 GPIO nums: swclk = 25, swdio = 24
Debug: 57 7 command.c:143 script_debug(): command - ocd_command ocd_command type ocd_bcm2835gpio_srst_num 23
Debug: 58 7 command.c:143 script_debug(): command - bcm2835gpio_srst_num ocd_bcm2835gpio_srst_num 23
User : 60 7 command.c:544 command_print(): BCM2835 GPIO config: srst = 23
Debug: 61 7 command.c:143 script_debug(): command - ocd_command ocd_command type ocd_reset_config srst_only srst_push_pull
Debug: 62 8 command.c:143 script_debug(): command - reset_config ocd_reset_config srst_only srst_push_pull
User : 64 8 command.c:544 command_print(): srst_only separate srst_gates_jtag srst_push_pull connect_deassert_srst
Debug: 65 8 command.c:143 script_debug(): command - ocd_command ocd_command type ocd_transport select swd
Debug: 66 8 command.c:143 script_debug(): command - ocd_transport ocd_transport select swd
Debug: 67 8 command.c:323 command_new(): BUG: command 'swd' does not have the '.usage' field filled out
Debug: 68 8 command.c:364 register_command_handler(): registering 'ocd_swd'...
Debug: 69 8 bitbang.c:353 bitbang_swd_init(): bitbang_swd_init
Debug: 70 8 configuration.c:82 find_file(): found /usr/bin/../share/openocd/scripts/target/stm32f0x.cfg
Debug: 71 9 configuration.c:82 find_file(): found /usr/bin/../share/openocd/scripts/target/swj-dp.tcl
Debug: 72 9 command.c:143 script_debug(): command - ocd_command ocd_command type ocd_transport select
Debug: 73 9 command.c:143 script_debug(): command - ocd_transport ocd_transport select
Debug: 74 9 configuration.c:82 find_file(): found /usr/bin/../share/openocd/scripts/mem_helper.tcl
Debug: 75 10 command.c:143 script_debug(): command - ocd_command ocd_command type ocd_add_usage_text mrw address
Debug: 76 10 command.c:143 script_debug(): command - add_usage_text ocd_add_usage_text mrw address
Debug: 78 10 command.c:1098 help_add_command(): added 'mrw' help text
Debug: 79 10 command.c:143 script_debug(): command - ocd_command ocd_command type ocd_add_help_text mrw Returns value of word in memory.
Debug: 80 10 command.c:143 script_debug(): command - add_help_text ocd_add_help_text mrw Returns value of word in memory.
Debug: 82 10 command.c:1111 help_add_command(): added 'mrw' help text
Debug: 83 10 command.c:143 script_debug(): command - ocd_command ocd_command type ocd_add_usage_text mrb address
Debug: 84 10 command.c:143 script_debug(): command - add_usage_text ocd_add_usage_text mrb address
Debug: 86 10 command.c:1098 help_add_command(): added 'mrb' help text
Debug: 87 10 command.c:143 script_debug(): command - ocd_command ocd_command type ocd_add_help_text mrb Returns value of byte in memory.
Debug: 88 10 command.c:143 script_debug(): command - add_help_text ocd_add_help_text mrb Returns value of byte in memory.
Debug: 90 10 command.c:1111 help_add_command(): added 'mrb' help text
Debug: 91 10 command.c:143 script_debug(): command - ocd_command ocd_command type ocd_add_usage_text mmw address setbits clearbits
Debug: 92 10 command.c:143 script_debug(): command - add_usage_text ocd_add_usage_text mmw address setbits clearbits
Debug: 94 11 command.c:1098 help_add_command(): added 'mmw' help text
Debug: 95 11 command.c:143 script_debug(): command - ocd_command ocd_command type ocd_add_help_text mmw Modify word in memory. new_val = (old_val & ~clearbits) | setbits;
Debug: 96 11 command.c:143 script_debug(): command - add_help_text ocd_add_help_text mmw Modify word in memory. new_val = (old_val & ~clearbits) | setbits;
Debug: 98 11 command.c:1111 help_add_command(): added 'mmw' help text
Debug: 99 11 command.c:143 script_debug(): command - ocd_command ocd_command type ocd_transport select
Debug: 100 11 command.c:143 script_debug(): command - ocd_transport ocd_transport select
Debug: 101 11 command.c:143 script_debug(): command - ocd_command ocd_command type ocd_transport select
Debug: 102 11 command.c:143 script_debug(): command - ocd_transport ocd_transport select
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

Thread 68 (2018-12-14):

Can't get to terminal to install the firmware

troglodisme, 2018-12-14:
I have finished assembling my boards and was excited to start installing the firmware but as soon as I powered the board (with the raspberry pi connected to both screen and monitor), the booting started without asking me to login (as described in the instructions) and after a few seconds both the little screen and the monitor were displaying the nsynth grid correctly. The touchpad, potentiometers and midi don't seem to work though, and most importantly no sound is coming out the minijack.

I assume the firmware is not properly installed? I would like to go back to the terminal and try running the mount commands, but.. how do I get to back to the terminal??

Thanks!

kaosbeat, 2018-12-22:
Hey I just read [here](https://github.com/googlecreativelab/open-nsynth-super/issues/32#issuecomment-393398718) how to do it.

> To replace the file and recompile the application you will need access to the Raspberry Pi. Hook it up to an HDMI monitor and a USB keyboard and boot it. Initially, you will see a copy of the Open NSynth Super screen. Hitting the ESC key will get you to a login prompt. Use the username "pi" (without quotes) and the password "raspberry" to log in. As the SD card is mounted as read only by default, you will need write access by remounting it: "sudo mount -u remount,rw /".

Hope this works!

K

troglodisme, 2019-01-10:
Thanks @kaosbeat - I eventually found out randomly while I was trying to get this done! Do you know if there is a way to add that to the guide/description? I feel other people might benefit from it.

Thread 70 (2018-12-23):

broken voltage regulators (U4-U5-U6) (bad Tindie batch) - FIXED

kaosbeat, 2018-12-23:
Hi all,

For those of you having a faulty board with the wrong voltage regulators (U4-U6) good news. I patched the board without using any voltage regulators at all, but this is considered experimental. It's a hack that worked for me, but there might be unknown side effects.
Basically I just draw the 3.3V off the RPi power rail. I soldered a wire to the connector on top (it's the "square" connector), feed it through a hole in the PCB and patch it into the output connectors of the different 3.3V circuits...

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

I read you can pull up to 800mAh form the 3.3V rail, given a sufficient power supply to the Rpi. This seems plenty for what it needs to do... YMMV

it works, and it is stable so far, but I'm ordering the correct voltage regulators. There must be a good reason somewhere to use these... would like to know the reason by the way.

good luck

kaosbeat, 2018-12-23:
fixed, so it can be closed. People in #67 will have had this problem as well some other issues can be related. Tindie has shipped out replacement boards (but I have not yet received mine) and desoldering all the pot's and the screen might be a lot more work then desoldering 3 voltage regulators... So that is why this can be a good thing to try.

cnuty, 2019-01-01:
Hi all,
And happy new year.
I received the new board yesterday. Now - when i'll have time - , I have to unsolder pots, encoders, display, and first to test software Pi interface connector. Maybe this connector is only sufficient to test software.
Give news when boards received and software tested. Thanks.

Closed 2018-12-23.

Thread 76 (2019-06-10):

Make install stm32x device protected error

songproducer, 2019-06-10:
```
  Prerequisite '../cube/Drivers/CMSIS/Device/ST/STM32F0xx/Source/Templates/gcc/startup_stm32f030xc.s' is older than target '../bin/main.elf'.
  No need to remake target '../bin/main.elf'.
 Finished prerequisites of target file 'install'.
Must remake target 'install'.
sudo openocd --file openocd.cfg --command "program ../bin/main.elf verify reset exit"
Putting child 0x72f8b0 (install) PID 1772 on the chain.
Live child 0x72f8b0 (install) PID 1772
Open On-Chip Debugger 0.10.0 (2019-06-10-11:18)
Licensed under GNU GPL v2
For bug reports, read
	http://openocd.org/doc/doxygen/bugs.html
BCM2835 GPIO nums: swclk = 25, swdio = 24
BCM2835 GPIO config: srst = 23
srst_only separate srst_gates_jtag srst_push_pull connect_deassert_srst
adapter speed: 1000 kHz
adapter_nsrst_delay: 100
srst_only separate srst_nogate srst_push_pull connect_deassert_srst
cortex_m reset_config sysresetreq
srst_only separate srst_nogate srst_push_pull connect_deassert_srst
adapter_nsrst_delay: 100
adapter_nsrst_assert_width: 100
Info : BCM2835 GPIO JTAG/SWD bitbang driver
Info : SWD only mode enabled (specify tck, tms, tdi and tdo gpios to add JTAG mode)
Info : clock speed 1001 kHz
Info : SWD DPIDR 0x0bb11477
Info : stm32f0x.cpu: hardware has 4 breakpoints, 2 watchpoints
    TargetName         Type       Endian TapName            State
--  ------------------ ---------- ------ ------------------ ------------
 0* stm32f0x.cpu       cortex_m   little stm32f0x.cpu       halted
adapter speed: 1001 kHz
target halted due to debug-request, current mode: Handler HardFault
xPSR: 0xc1000003 pc: 0xfffffffe msp: 0xfffffffc
adapter speed: 1001 kHz
target halted due to debug-request, current mode: Handler HardFault
xPSR: 0xc1000003 pc: 0xfffffffe msp: 0xfffffffc
adapter speed: 4061 kHz
** Programming Started **
auto erase enabled
Info : device id = 0x10006444
Info : flash size = 32kbytes
Error: stm32x device protected
Error: failed erasing sectors 0 to 15
** Programming Failed **
shutdown command invoked

Reaping losing child 0x72f8b0 PID 1772
Makefile:40: recipe for target 'install' failed
make: *** [install] Error 1
Removing child 0x72f8b0 PID 1772 from chain.
```

AR17HY, 2022-01-16:
Error: stm32x device protected => use ST-link utility to unlock your memory (you can keep the boot-loader section protected)
If it is no enough, you might need to change the flash address in your Linker

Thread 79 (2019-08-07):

all controller is ok , but no sound

PantalaLabs, 2019-08-07:
Hi ,

Just got my unit.
All controls runs fine. But no sound at jack.
Is there any command line to test the sound ?

Thank you.

JasonQRY, 2021-01-16:
Hi，

Me, too. My unit has all functions, only can't output sound. I try to figure out the problem. Now I try to replace the PCM512 chip.

Did you have already solved the problem ?

Thx

PantalaLabs, 2021-01-16:
Hi Jason.

I my case , the problem was the optocoupler (i cant remember now, but i think it is the 6n139) .
Replaced and everything worked fine.

JasonQRY, 2021-01-16:
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

Oh, thx for the answer ! I will also check my optocoupler. Your answer is really helpful!

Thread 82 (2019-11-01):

Contents of OLED too far left - first column of pixels missing

TTRCmedia, 2019-11-01:
Hello!
I got an SMT presoldered PCB from ebay really cheap and just finished building my NSynth Super :) It is working, all pots and encoders functioning correctly. The only issue I have so far is that the contents on the OLED display seem to be too far left - just one pixel I think - so the first column is cut off. Perhaps the OLED is buggy, but as it is quite expensive and I don´t want to order a new one, is there a way to change the position of the displays´ contents, so I could move everything just this one pixel to the right?
Regards,
Danyel

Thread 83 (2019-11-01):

Upgrading hardware to 1.2 - wire encoder switches

TTRCmedia, 2019-11-01:
Hello!
I just finished my build, using the original PCB layout. As I did not get the encoders without momentary switch, I use encoders with switch. but I did not cut off the unnecessary legs, I just bent them upwards so they are lying on top of the PCB.
If I read the current version of the schematics correctly, the switches for using the "new" feature to store patches are connected between ground and GPIO pins. So would it be possible to use some thin wire to connect one pin of each encoder to ground and the other one to the correct GPIO pin, or are there other changes to the schematics to make this feature work?
Regards,
Danyel

Jonny0815, 2019-11-10:
having the same question

nervousapps, 2019-11-10:
Just wire the encoder switch pins to the corresponding GPIO pins and upgrade the firmware. It works great !

TTRCmedia, 2019-11-10:
Great! I´ll give it a try :)

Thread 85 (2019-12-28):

Black OLED screen and  no sound

Faye108, 2019-12-28:
Hi,

I'm experiencing some strange issue with my Nsynth build. I already spent hours to troubleshoot, but couldn't source the problem. I am very desperate.

Everything seems to be working fine except:
- the OLED screen doesn't work (remains totally black)
- there is no sound at all
- since there is no sound, I don't know if midi signals get processed or not.

I already checked for any soldering bridges and checked for the right polarity of all components.
Even though I'm quite confident in my soldering skills, out of pure desperation I decided to build a second unit with a second set of components (including a new screen). As for the second unit, I followed [this advice](https://github.com/googlecreativelab/open-nsynth-super/issues/27#issuecomment-388999063) and left a tiny gap between the 2 PCB to avoid any solder bridges. To my surprise, the finished build shows **EXACTLY** the same issue as the first one.....

- I used Elecrow to produce the PCB according to the build instructions.
- I sourced and soldered all components myself (including SMD)
- I have a raspberry B+ with the 64gb image.
- I also tried it with a raspberry B, but still the same problem.
- Nsynth starts up normally. I logged in and successfully flashed the board.
- When I connect the Nsynth to a monitor via HDMI, the mini-screen appears on the upper left corner. I can see on the monitor that the encoders, the pots and the touch panel work completely fine.
- All pins on the OLED PCB have voltage. So unlike [this user](https://github.com/googlecreativelab/open-nsynth-super/issues/27#issuecomment-392628556), it doesn't seem that bad solder joint are the cause of the problem.
- I bridged both the SJ1 and SJ2 on the OLED PCB.
- Running i2cdetect -y 1 shows MCU at 0x47, the display at 0x3d and a device at 0x4c.

Please help... :/

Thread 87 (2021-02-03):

NSynth Samples lib

Fluqz, 2021-02-03:
Hey, I built a NSynth 1-2 years ago and always had the problem that id like to upload more or different samples, but I have a 15 year old windows computer, which will probably take weeks to process the audio. I also dont have linux installed. The [NSynth Sound Maker](https://experiments.withgoogle.com/ai/sound-maker/view/) is the only project I found with different audio files, but I have no idea how to upload them to my NSynth.

Id really appreciate if anyone would share his audio files and maybe could give me some hints on how to upload them!

Thanks in advance :)

where-is-brett, 2022-07-02:
Hey mate, I am training two sets of samples at the moment, you can find them [here](https://github.com/where-is-brett/nsynth-pipeline/tree/main/audio/workdir/audio_input) and [here](https://github.com/where-is-brett/open-nsynth-super/tree/master/audio/workdir). I am happy to share the generated audio files if you're still interested. Just need a place to host the files (they are large ~40GB).

Fluqz, 2023-04-18:
Hey dude, thanks for your reply. Im a bit late, but did you manage to use your audio files? I sure am interested in the files, if we find a way to share 40gb :D

where-is-brett, 2023-06-14:
Unfortunately not. I only had access to a newer machine which didn't support python 2 or TF1.5, so I had to tweak the nsynth training pipeline to make it run on python 3. I did manage to make it run on python 3 with the later TF versions but the training performance was really poor - would have run for a month on a A100 machine! This is probably a matter of GPU drivers as the same tweaked pipeline trained 3x as fast on Colab GPU (with Pro subscription).

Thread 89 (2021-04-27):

NSynth not receiving MIDI??

jimpendo, 2021-04-27:
Not sure if this is even remotely active here, but worth a shot.

Build went fine, flashing went fine, all the pots etc seem to work, but it's not receiving MIDI. Any ideas?

I guess it may also be the audio as there's no way to tell?

Tried outputting on multiple channels / devices.

Help!!

Fluqz, 2021-05-18:
Maybe this is helping you https://github.com/googlecreativelab/open-nsynth-super/issues/32

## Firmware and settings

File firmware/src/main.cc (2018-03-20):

/*
Copyright 2016 Google Inc. All Rights Reserved.
Licensed under the Apache License, Version 2.0 (the "License");
you may not use this file except in compliance with the License.
You may obtain a copy of the License at
    http://www.apache.org/licenses/LICENSE-2.0
Unless required by applicable law or agreed to in writing, software
distributed under the License is distributed on an "AS IS" BASIS,
WITHOUT WARRANTIES OR CONDITIONS OF ANY KIND, either express or implied.
See the License for the specific language governing permissions and
limitations under the License.
*/

#include <stdbool.h>
#include <string.h>

#include "main.h"
#include "bitbang_i2c.h"
#include "rotary.h"


#define I2C_ADDRESS 0x47

#define ADC_PORT GPIOA
#define ADC_PIN_POT0 GPIO_PIN_0
#define ADC_PIN_POT1 GPIO_PIN_1
#define ADC_PIN_POT2 GPIO_PIN_2
#define ADC_PIN_POT3 GPIO_PIN_3
#define ADC_PIN_POT4 GPIO_PIN_4
#define ADC_PIN_POT5 GPIO_PIN_5
#define NUM_POTS 6

#define ROT0_PORT GPIOA
#define ROT0_A_PIN GPIO_PIN_6
#define ROT0_B_PIN GPIO_PIN_7

#define ROT1_PORT GPIOB
#define ROT1_A_PIN GPIO_PIN_0
#define ROT1_B_PIN GPIO_PIN_1

#define ROT2_PORT GPIOA
#define ROT2_A_PIN GPIO_PIN_8
#define ROT2_B_PIN GPIO_PIN_9

#define ROT3_PORT GPIOA
#define ROT3_A_PIN GPIO_PIN_10
#define ROT3_B_PIN GPIO_PIN_11
#define NUM_ROTARIES 4


// Stores the values of all the hardware inputs.
struct Inputs {
  // The reported touch position, either 0-10 or 255 on no touch.
  uint8_t touch[2];

  // The position for each rotary encoder. From 0-255 wrapping in both
  // directions.
  uint8_t rotaries[NUM_ROTARIES];

  // The most significant 8 bits from the ADC readings on each potentiometer.
  uint8_t pots[NUM_POTS];
};


// Stores a message to be sent over the I2C bus to the master. This includes
// all the inputs and a checksum. The checksum is calculated as:
//   0xaa55aa55 +
//   the first 32 bits of inputs +
//   the second 32 bits of inputs +
//   the third 32 bits of inputs
struct I2cMessage {
    Inputs inputs;
    uint32_t chk;
};


// Global instances.
static ADC_HandleTypeDef adc_handle;
static GPIO_InitTypeDef  gpio_init;
static I2C_HandleTypeDef i2c_handle;
static TIM_HandleTypeDef tim16_handle;

static BitBangI2C touch_i2c(GPIO_PIN_5, GPIO_PIN_3 | GPIO_PIN_4);
static Inputs current_inputs = {0};
static I2cMessage i2c_message = {0};
static Rotary rotaries[NUM_ROTARIES];


// Handles errors by looping forever. This can be very useful is a debugger
// is attached as the stack trace can pin point the problem.
static void ErrorHandler() {
  while (true) {
    HAL_Delay(20);
  }
}


// Sets up the ADC hardware for reading the potentiometers.
static void InitAdc(void) {
  gpio_init.Mode = GPIO_MODE_ANALOG;
  gpio_init.Pull = GPIO_NOPULL;
  gpio_init.Speed = GPIO_SPEED_FREQ_HIGH;
  gpio_init.Pin = (
      ADC_PIN_POT0 | ADC_PIN_POT1 | ADC_PIN_POT2 |
      ADC_PIN_POT3 | ADC_PIN_POT4 | ADC_PIN_POT5);
  HAL_GPIO_Init(ADC_PORT, &gpio_init);

  ADC_ChannelConfTypeDef adcChannel;

  adc_handle.Instance = ADC1;

  adc_handle.Init.ClockPrescaler = ADC_CLOCK_SYNC_PCLK_DIV2;
  adc_handle.Init.Resolution = ADC_RESOLUTION_12B;
  adc_handle.Init.ScanConvMode = DISABLE;
  adc_handle.Init.ContinuousConvMode = DISABLE;
  adc_handle.Init.DiscontinuousConvMode = ENABLE;
  adc_handle.Init.ExternalTrigConvEdge = ADC_EXTERNALTRIGCONVEDGE_NONE;
  adc_handle.Init.DataAlign = ADC_DATAALIGN_RIGHT;
  adc_handle.Init.DMAContinuousRequests = DISABLE;
  adc_handle.Init.EOCSelection = DISABLE;

  HAL_ADC_Init(&adc_handle);

  for (int i=0; i<NUM_POTS; ++i) {
    adcChannel.Channel = ADC_CHANNEL_0 + i;
    adcChannel.Rank = i + 1;
    adcChannel.SamplingTime = ADC_SAMPLETIME_239CYCLES_5;

    if (HAL_ADC_ConfigChannel(&adc_handle, &adcChannel) != HAL_OK) {
      ErrorHandler();
    }
  }
}


// Sets up the I2C hardware for communicating with the master.
static void InitI2c() {
  i2c_handle.Instance = I2C1;
  //    Bits 31:28
  //        PRESC[3:0] : Timing prescaler
  //    Bits 27:24  Reserved, must be kept at reset value.
  //    Bits 23:20
  //        SCLDEL[3:0] : Data setup time
  //    Bits 19:16
  //        SDADEL[3:0] : Data hold time
  //    Bits 15:8
  //        SCLH[7:0] : SCL high period (master mode)
  //    Bits 7:0
  //        SCLL[7:0] : SCL low period (master mode)
  // The SCLDEL and SDADEL times are set to 0 to support 400KHz speeds.
  i2c_handle.Init.Timing = 0x10000f13;
  i2c_handle.Init.OwnAddress1 = I2C_ADDRESS << 1;
  i2c_handle.Init.OwnAddress2 = 0xff;
  i2c_handle.Init.AddressingMode = I2C_ADDRESSINGMODE_7BIT;
  i2c_handle.Init.DualAddressMode = I2C_DUALADDRESS_DISABLE;
  i2c_handle.Init.GeneralCallMode = I2C_GENERALCALL_DISABLE;
  i2c_handle.Init.NoStretchMode = I2C_NOSTRETCH_ENABLE;

  if (HAL_I2C_Init(&i2c_handle) != HAL_OK) {
    ErrorHandler();
  }

  HAL_I2CEx_ConfigAnalogFilter(&i2c_handle,I2C_ANALOGFILTER_ENABLE);

  gpio_init.Mode  = GPIO_MODE_AF_OD;
  gpio_init.Pull  = GPIO_PULLUP;
  gpio_init.Speed = GPIO_SPEED_FREQ_HIGH;
  gpio_init.Alternate = GPIO_AF1_I2C1;
  gpio_init.Pin = GPIO_PIN_6 | GPIO_PIN_7;
  HAL_GPIO_Init(GPIOB, &gpio_init);
}


// Sets up the hardware for reading from the rotary encoders.
static void InitRot() {
  gpio_init.Mode = GPIO_MODE_INPUT;
  gpio_init.Pull = GPIO_PULLUP;
  gpio_init.Speed = GPIO_SPEED_FREQ_HIGH;

  gpio_init.Pin = ROT0_A_PIN | ROT0_B_PIN;
  HAL_GPIO_Init(ROT0_PORT, &gpio_init);

  gpio_init.Pin = ROT1_A_PIN | ROT1_B_PIN;
  HAL_GPIO_Init(ROT1_PORT, &gpio_init);

  gpio_init.Pin = ROT2_A_PIN | ROT2_B_PIN;
  HAL_GPIO_Init(ROT2_PORT, &gpio_init);

  gpio_init.Pin = ROT3_A_PIN | ROT3_B_PIN;
  HAL_GPIO_Init(ROT3_PORT, &gpio_init);

  rotaries[0].Init(
      HAL_GPIO_ReadPin(ROT0_PORT, ROT0_A_PIN),
      HAL_GPIO_ReadPin(ROT0_PORT, ROT0_B_PIN));
  rotaries[1].Init(
      HAL_GPIO_ReadPin(ROT1_PORT, ROT1_A_PIN),
      HAL_GPIO_ReadPin(ROT1_PORT, ROT1_B_PIN));
  rotaries[2].Init(
      HAL_GPIO_ReadPin(ROT2_PORT, ROT2_A_PIN),
      HAL_GPIO_ReadPin(ROT2_PORT, ROT2_B_PIN));
  rotaries[3].Init(
      HAL_GPIO_ReadPin(ROT3_PORT, ROT3_A_PIN),
      HAL_GPIO_ReadPin(ROT3_PORT, ROT3_B_PIN));

  tim16_handle.Instance = TIM16;

  tim16_handle.Init.Prescaler = (uint32_t)(SystemCoreClock / 20000);
  tim16_handle.Init.Period = 5 - 1;
  tim16_handle.Init.ClockDivision = 0;
  tim16_handle.Init.CounterMode = TIM_COUNTERMODE_UP;
  tim16_handle.Init.RepetitionCounter = 0;

  if (HAL_TIM_Base_Init(&tim16_handle) != HAL_OK) {
    ErrorHandler();
  }
}


// Sets up the touch controllers.
static void InitTouch() {
  uint8_t buf[2];

  // Put every key in the same group, disabling multiple touches.
  for (int key=0; key<11; ++key) {
    buf[0] = 28+key;
    buf[1] = 4;
    touch_i2c.Send(0x1c, buf, 2);
  }

  // Set the Detection Integrator to 1 for the fastest response times.
  buf[0] = 11;
  buf[1] = 1;
  touch_i2c.Send(0x1c, buf, 2);
}


// Starts reading from the rotary encoders.
static void StartRot() {
  if (HAL_TIM_Base_Start_IT(&tim16_handle) != HAL_OK) {
    ErrorHandler();
  }
}


// Starts handling I2C comms with the master.
static void StartI2c() {
  uint32_t flags = 0U;
  flags |= I2C_IT_ADDRI | I2C_IT_STOPI | I2C_IT_NACKI | I2C_IT_ERRI;
  flags |= I2C_IT_TCI | I2C_IT_TXI | I2C_IT_RXI;
  __HAL_I2C_ENABLE_IT(&i2c_handle, flags);
  i2c_handle.Instance->CR2 &= ~I2C_CR2_NACK;
}


// Reads from both touch sensors using I2C.
static void ReadTouch() {
  uint8_t buf[2];

  // Send address 0.
  buf[0] = 3;
  touch_i2c.Send(0x1c, buf, 1);

  // Read 2 bytes.
  touch_i2c.Recv(0x1c, 2);

  // Loop over both busses.
  static uint16_t data_pins[2] = {GPIO_PIN_3, GPIO_PIN_4};
  for (int channel=0; channel<2; ++channel) {
    uint16_t data_pin = data_pins[channel];

    if (touch_i2c.Acknowledged(data_pin)) {
      touch_i2c.GetResponse(data_pin, buf, 2);

      uint16_t keys = buf[0] | (buf[1] << 8);
      int key;
      for (key=0; key<11; ++key) {
        if (keys & (1 << key)) {
          break;
        }
      }

      if (key < 11) {
        // Invert the position so that the position is reported
        // relative to the top left corner (screen co-ordinates).
        key = 10 - key;
      } else {
        // The no-touch value.
        key = 0xff;
      }

      current_inputs.touch[channel] = key;
    }
  }
}


// Updates the rotary inputs.
static void ReadRots() {
  current_inputs.rotaries[0] += rotaries[0].Update(
      HAL_GPIO_ReadPin(ROT0_PORT, ROT0_A_PIN),
      HAL_GPIO_ReadPin(ROT0_PORT, ROT0_B_PIN));
  current_inputs.rotaries[1] += rotaries[1].Update(
      HAL_GPIO_ReadPin(ROT1_PORT, ROT1_A_PIN),
      HAL_GPIO_ReadPin(ROT1_PORT, ROT1_B_PIN));
  current_inputs.rotaries[2] += rotaries[2].Update(
      HAL_GPIO_ReadPin(ROT2_PORT, ROT2_A_PIN),
      HAL_GPIO_ReadPin(ROT2_PORT, ROT2_B_PIN));
  current_inputs.rotaries[3] += rotaries[3].Update(
      HAL_GPIO_ReadPin(ROT3_PORT, ROT3_A_PIN),
      HAL_GPIO_ReadPin(ROT3_PORT, ROT3_B_PIN));
}


// Copies the current inputs to the i2c_message, also calculating the checksum.
static void CopyInputs() {
  static_assert(
      sizeof(current_inputs) == sizeof(uint32_t) * 3,
      "Hard coded copy does not match source size.");
  static_assert(
      sizeof(i2c_message.inputs) == sizeof(uint32_t) * 3,
      "Hard coded copy does not match destination size.");

  // This is hard coded as 3 uint32_t copies, which ties in with the checksum
  // calculation.
  uint32_t *src = (uint32_t *)&current_inputs;
  uint32_t *dst = (uint32_t *)&i2c_message.inputs;

  uint32_t chk = 0xaa55aa55;
  uint32_t data;
  data = *src++;
  *dst++ = data;
  chk += data;
  data = *src++;
  *dst++ = data;
  chk += data;
  data = *src++;
  *dst++ = data;
  chk += data;

  i2c_message.chk = chk;
}


// Handles IRQs for the master I2C hardware.
extern "C"
void I2C1_IRQHandler(void) {
  static unsigned int tx_idx = 0;
  uint32_t it_flags   = READ_REG(i2c_handle.Instance->ISR);

  if (it_flags & I2C_FLAG_TXIS) {
    // Need to send some data.
    if (tx_idx < sizeof(i2c_message)) {
      i2c_handle.Instance->TXDR = ((uint8_t *)&i2c_message)[tx_idx++];
    } else {
      i2c_handle.Instance->TXDR = 0x00;
    }
  }

  if (it_flags & I2C_FLAG_ADDR) {
    // Address match.
    uint8_t transferdirection = I2C_GET_DIR(&i2c_handle);

    __HAL_I2C_CLEAR_FLAG(&i2c_handle,I2C_FLAG_ADDR);

    if (transferdirection == I2C_DIRECTION_RECEIVE) {
      // Start sending the first byte of the i2c_message.
      i2c_handle.Instance->TXDR = ((uint8_t *)&i2c_message)[0];
      tx_idx = 1;
    } else {
      // Writing to this device causes the inputs to be copied to the
      // send buffer.
      CopyInputs();
    }
  }

  if (it_flags & I2C_FLAG_RXNE) {
    // Received some data.
    volatile uint8_t data = i2c_handle.Instance->RXDR;
    UNUSED(data);
  }

  if (it_flags & (I2C_FLAG_AF | I2C_FLAG_STOPF)) {
    // Finished.
    __HAL_I2C_CLEAR_FLAG(&i2c_handle, I2C_FLAG_AF);
    __HAL_I2C_CLEAR_FLAG(&i2c_handle, I2C_FLAG_STOPF);
    __HAL_I2C_CLEAR_FLAG(&i2c_handle, I2C_FLAG_ADDR);
    I2C_RESET_CR2(&i2c_handle);
    if (__HAL_I2C_GET_FLAG(&i2c_handle, I2C_FLAG_TXIS) != RESET) {
      i2c_handle.Instance->TXDR = 0x00U;
    }
    if (__HAL_I2C_GET_FLAG(&i2c_handle, I2C_FLAG_TXE) == RESET) {
      __HAL_I2C_CLEAR_FLAG(&i2c_handle, I2C_FLAG_TXE);
    }

    i2c_handle.Instance->CR2 |= I2C_CR2_NACK;
  }

  __HAL_I2C_CLEAR_FLAG(&i2c_handle, I2C_FLAG_BERR);
  __HAL_I2C_CLEAR_FLAG(&i2c_handle, I2C_FLAG_OVR);
  __HAL_I2C_CLEAR_FLAG(&i2c_handle, I2C_FLAG_ARLO);

  i2c_handle.Instance->CR2 &= ~I2C_CR2_NACK;
}


// Handles IRQs for timer 16 - used for the rotary encoders.
extern "C"
void TIM16_IRQHandler(void) {
  if (__HAL_TIM_GET_FLAG(&tim16_handle, TIM_FLAG_UPDATE) != RESET) {
    if (__HAL_TIM_GET_IT_SOURCE(&tim16_handle, TIM_IT_UPDATE) != RESET) {
      __HAL_TIM_CLEAR_IT(&tim16_handle, TIM_IT_UPDATE);
      HAL_TIM_PeriodElapsedCallback(&tim16_handle);
      ReadRots();
    }
  }
}


// Handles IRQs for ADC1.
extern "C" void ADC1_IRQHandler(void) {
  HAL_ADC_IRQHandler(&adc_handle);
}


// Handles ADC results.
extern "C" void HAL_ADC_ConvCpltCallback(ADC_HandleTypeDef* hadc) {
  static int channel = 0;
  static int sample = 0;
  static uint16_t history[NUM_POTS][16] = {0};
  static uint32_t last_value[NUM_POTS] = {0};

  uint16_t adc = (uint16_t)HAL_ADC_GetValue(&adc_handle);

  // Take the average of 16 samples.
  history[channel][sample] = adc;
  uint32_t sum = 0;
  for (int i=0; i<16; ++i) {
      sum += uint32_t(history[channel][i]);
  }
  uint32_t average = sum >> 4;

  // Perform an addition filter while still working with 12 bits.
  // If the value changes less than 12 do not update it.
  uint32_t delta;
  if (last_value[channel] > average) {
    delta = last_value[channel] - average;
    if (delta >= 12) {
      last_value[channel] = average;
    }
  } else {
    delta = average - last_value[channel];
    if (delta >= 12) {
      last_value[channel] = average;
    }
  }

  // Right shift by 4 to reduce the 12 bit result to 8 bits.
  current_inputs.pots[channel] = last_value[channel] >> 4;

  if (++channel >= NUM_POTS) {
    channel = 0;
    sample = (sample + 1) % 16;
  }

  // Start another conversion.
  HAL_ADC_Start_IT(&adc_handle);
}


// Configures the system clocks for 48MHz operation.
void SystemClockConfig() {
  RCC_ClkInitTypeDef RCC_ClkInitStruct;
  RCC_OscInitTypeDef RCC_OscInitStruct;

  // Select HSI as the temporary system clock source.
  RCC_ClkInitStruct.ClockType = RCC_CLOCKTYPE_SYSCLK;
  RCC_ClkInitStruct.SYSCLKSource = RCC_SYSCLKSOURCE_HSI;
  RCC_ClkInitStruct.AHBCLKDivider = RCC_SYSCLK_DIV1;
  RCC_ClkInitStruct.APB1CLKDivider = RCC_HCLK_DIV1;
  if (HAL_RCC_ClockConfig(&RCC_ClkInitStruct, FLASH_LATENCY_1) != HAL_OK) {
    ErrorHandler();
  }

  // Activate PLL with HSI/2 as source.
  RCC_OscInitStruct.OscillatorType = RCC_OSCILLATORTYPE_NONE;
  RCC_OscInitStruct.PLL.PLLState = RCC_PLL_ON;
  RCC_OscInitStruct.PLL.PLLSource = RCC_PLLSOURCE_HSI;
  RCC_OscInitStruct.PLL.PREDIV = RCC_PREDIV_DIV1;
  RCC_OscInitStruct.PLL.PLLMUL = RCC_PLL_MUL12;
  if (HAL_RCC_OscConfig(&RCC_OscInitStruct)!= HAL_OK) {
    ErrorHandler();
  }

  // Select PLL as system clock source and configure the HCLK, PCLK1 clocks
  // dividers.
  RCC_ClkInitStruct.ClockType = (
      RCC_CLOCKTYPE_SYSCLK | RCC_CLOCKTYPE_HCLK | RCC_CLOCKTYPE_PCLK1);
  RCC_ClkInitStruct.SYSCLKSource = RCC_SYSCLKSOURCE_PLLCLK;
  RCC_ClkInitStruct.AHBCLKDivider = RCC_SYSCLK_DIV1;
  RCC_ClkInitStruct.APB1CLKDivider = RCC_HCLK_DIV1;
  if (HAL_RCC_ClockConfig(&RCC_ClkInitStruct, FLASH_LATENCY_1)!= HAL_OK) {
    ErrorHandler();
  }
}


int main(void) {
  HAL_Init();
  SystemClockConfig();

  // Set up all the hardware.
  __HAL_RCC_GPIOA_CLK_ENABLE();
  __HAL_RCC_GPIOB_CLK_ENABLE();
  __HAL_RCC_ADC1_CLK_ENABLE();
  __HAL_RCC_I2C1_CLK_ENABLE();
  __HAL_RCC_TIM16_CLK_ENABLE();
  __HAL_RCC_TIM17_CLK_ENABLE();

  touch_i2c.Setup(GPIOB);

  InitAdc();
  InitI2c();
  InitRot();
  InitTouch();

  // Comms to the RPi are given top priority so that they do not fail.
  HAL_NVIC_SetPriority(I2C1_IRQn, 0, 0);
  HAL_NVIC_EnableIRQ(I2C1_IRQn);

  // The rotary timer is given second priority so that the encoders are
  // read consistently.
  HAL_NVIC_SetPriority(TIM16_IRQn, 1, 0);
  HAL_NVIC_EnableIRQ(TIM16_IRQn);

  // The potentiometers are given last priority.
  HAL_NVIC_SetPriority(ADC1_IRQn, 1, 2);
  HAL_NVIC_EnableIRQ(ADC1_IRQn);

  // Perform an initial read of all inputs and then start I2C comms
  // with the host.
  StartRot();
  HAL_ADC_Start_IT(&adc_handle);
  ReadTouch();
  HAL_Delay(16);

  StartI2c();

  while (true) {
    ReadTouch();
    HAL_Delay(4);
  }
}

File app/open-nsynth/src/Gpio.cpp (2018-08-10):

/*
Copyright 2017 Google Inc. All Rights Reserved.
Licensed under the Apache License, Version 2.0 (the "License");
you may not use this file except in compliance with the License.
You may obtain a copy of the License at
    http://www.apache.org/licenses/LICENSE-2.0
Unless required by applicable law or agreed to in writing, software
distributed under the License is distributed on an "AS IS" BASIS,
WITHOUT WARRANTIES OR CONDITIONS OF ANY KIND, either express or implied.
See the License for the specific language governing permissions and
limitations under the License.
*/

#include "Gpio.h"

#include <chrono>
#include <fcntl.h>
#include <sys/ioctl.h>
#include <sys/mman.h>
#include <thread>
#include <unistd.h>


constexpr int SET = 7;
constexpr int CLEAR = 10;
constexpr int GET = 13;
constexpr int MAP_SIZE = 0xb4;
constexpr int GPPUD = 37;
constexpr int GPPUDCLK = 38;


Gpio::Gpio(){
	int fd = open("/dev/gpiomem", O_RDWR | O_SYNC);
	if(fd >= 0){
		gpioReg = (uint32_t *)mmap(
				NULL, MAP_SIZE, PROT_READ|PROT_WRITE, MAP_SHARED, fd, 0);

		if(gpioReg == MAP_FAILED){
			gpioReg = nullptr;
		}

		close(fd);
	}
}


Gpio::~Gpio(){
	if(gpioReg){
		munmap(const_cast<uint32_t *>(gpioReg), MAP_SIZE);
	}
}


Gpio::operator bool() const{
	return gpioReg != nullptr;
}


bool Gpio::setInput(int pin, Pull pull){
	if(!gpioReg || pin < 2 || pin > 27){
		return false;
	}

	int reg = pin / 10;
	int shift = (pin % 10) * 3;

	gpioReg[reg] = (gpioReg[reg] & ~(7<<shift));

	gpioReg[GPPUD] = pull & 3;
	std::this_thread::sleep_for(std::chrono::milliseconds(1));
	gpioReg[GPPUDCLK] = 1 << pin;
	std::this_thread::sleep_for(std::chrono::milliseconds(1));

	gpioReg[GPPUD] = 0;
	gpioReg[GPPUDCLK] = 0;

	return true;
}


bool Gpio::setOutput(int pin){
	if(!gpioReg || pin < 2 || pin > 27){
		return false;
	}

	int reg = pin / 10;
	int shift = (pin % 10) * 3;

	gpioReg[reg] = (gpioReg[reg] & ~(7<<shift)) | (1<<shift);

	return true;
}


bool Gpio::write(int pin, bool high){
	if(!gpioReg || pin < 2 || pin > 27){
		return false;
	}

	gpioReg[high ? SET : CLEAR] = 1 << (pin & 0x1f);
	return true;
}


bool Gpio::read(int pin){
	if(!gpioReg || pin < 2 || pin > 27){
		return false;
	}

	return (gpioReg[GET] & (1 << (pin & 0x1f))) != 0;
}


void Gpio::reset(int pin, size_t uSecHold, size_t uSecDelay){
	// Set the pin to an output and drive it low.
	setOutput(pin);
	write(pin, false);
	std::this_thread::sleep_for(std::chrono::microseconds(uSecHold));

	// Restore the pin
	write(pin, 1);
	setInput(pin, PULL_UP);
	std::this_thread::sleep_for(std::chrono::microseconds(uSecDelay));
}

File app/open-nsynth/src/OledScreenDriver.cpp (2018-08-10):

/*
Copyright 2017 Google Inc. All Rights Reserved.
Licensed under the Apache License, Version 2.0 (the "License");
you may not use this file except in compliance with the License.
You may obtain a copy of the License at
    http://www.apache.org/licenses/LICENSE-2.0
Unless required by applicable law or agreed to in writing, software
distributed under the License is distributed on an "AS IS" BASIS,
WITHOUT WARRANTIES OR CONDITIONS OF ANY KIND, either express or implied.
See the License for the specific language governing permissions and
limitations under the License.
*/

#include "OledScreenDriver.h"

#include <fcntl.h>
#include <linux/i2c-dev.h>
#include <sys/ioctl.h>
#include <sys/mman.h>
#include <unistd.h>


bool OledScreenDriver::setup(int i2cFd_, uint8_t address_){
	i2cFd = i2cFd_;
	address = address_;

	if(i2cFd < 0){
		return false;
	}
	if(ioctl(i2cFd, I2C_SLAVE, address) < 0){
		return false;
	}

	// Send the screen setup commands.
	static uint8_t setup0[] = {
		0, 174, 213, 128, 168, 63, 211, 0, 64, 141, 20, 32,
		0, 161, 200, 218, 18, 217, 241, 219, 64, 164, 166
	};
	static uint8_t setup1[] = {
		0, 129, 207
	};
	static uint8_t setup2[] = {
		0, 33, 0, 127, 34, 0, 7
	};

	if(write(i2cFd, setup0, sizeof(setup0)) != sizeof(setup0)){
		return false;
	}
	if(write(i2cFd, setup1, sizeof(setup1)) != sizeof(setup1)){
		return false;
	}
	if(write(i2cFd, setup2, sizeof(setup2)) != sizeof(setup2)){
		return false;
	}

	return true;
}


void OledScreenDriver::draw(ofFbo &fbo){
	if(i2cFd < 0){
		return;
	}
	if(ioctl(i2cFd, I2C_SLAVE, address) < 0){
		return;
	}

	ofPixels pixels;
	fbo.readToPixels(pixels);

	uint8_t buf[129];

	// Write data command.
	buf[0] = 64;

	int pixelIdx = 0;
	for(int seg=0; seg<8; ++seg){
		// The screen is drawn in 8 horizontal segments.
		// Each segment is 128x8 pixels.
		// Each byte represents one column.

		// Clear the buffer first.
		for(unsigned int x=1; x<sizeof(buf); ++x){
			buf[x] = 0;
		}

		// Traverse the 8 rows.
		for(int y=0; y<8; ++y){
			for(int x=0; x<128; ++x){
				int set = pixels[pixelIdx] >= 127;
				buf[x+1] |= set << y;
				pixelIdx += 4;
			}
		}

		if(write(i2cFd, buf, sizeof(buf)) != sizeof(buf)){
			break;
		}
	}

	// Flush the new data to the screen.
	static uint8_t flush[] = {
		0, 175
	};

	if(write(i2cFd, flush, sizeof(flush)) != sizeof(flush)){
		return;
	}
}

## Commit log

2018-03-20 Repo sync commit
    [NSynth_Super_Dial_Big.stl, NSynth_Super_Lasercut_Template.dxf, NSynth_Super_Small_Dial.stl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]
2018-04-04 Updated readmes following Raspberry Pi 3B+ release
2018-05-28 Fix #43 by filtering out system real-time messages
2018-07-30 Filtered out all system real-time messages
2018-08-10 Added Raspberry Pi 3B+ support
2018-08-10 Add encoder switches to use for patches
    [mcu.sch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]
